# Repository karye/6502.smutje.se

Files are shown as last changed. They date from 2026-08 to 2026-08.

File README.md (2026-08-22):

# W65C02 8-bitarsdator med Arduino Mega-emulering

En hembyggd 8-bitarsdator med **W65C02S** CPU och **Arduino Mega 2560** som minnesemulator och klockgenerator. Projektet byggs stegvis — från en blinkande LED till en fullt fungerande dator med I/O-expansion (W65C22 VIA) och LCD-display styrd direkt av 6502-processorn.

---

## Webbplatsen (Material for MkDocs)

Sajten (6502.smutje.se) byggs från markdown-filerna i `docs/` med **Material for MkDocs**. `docs/` är källan — du redigerar bara markdown, aldrig `site/`.

### Bygga

```bash
cd /var/www/6502.smutje.se
.venv/bin/mkdocs build      # bygger site/ — Apache servear site/ direkt
.venv/bin/mkdocs serve      # lokal förhandsvisning på http://localhost:8000
```

### Arbetsflöde

1. Redigera `docs/*.md` (text, tabeller, bildreferenser)
2. Kör `mkdocs build`
3. Sajten är omedelbart uppdaterad — inget mer behövs

### Regler att hålla

- **Blankrader kring tabeller** — en tabell måste ha tomrad före och efter. Utan tomrad efter tabellen slukar tabellen nästa rubrik som tabellrad.
- **Kodrutorna är live** — kod visas via snippets (`--8<--`) direkt från `Mega_2560_6502/src/*.inc`, `asm/*.asm` och `scripts/*.py`. Ändra källfilen → nästa bygge visar nya koden, utan att röra md.
- **`site/` rörs aldrig** — genereras vid varje bygge och skrivs över.
- **`legacy/`** — arkiv av den gamla handskrivna HTML-sajten (stepX.html, style.css).
- Nya sidor läggs till i `nav:` i `mkdocs.yml`.

### Installation på ny maskin

```bash
python3 -m venv .venv
.venv/bin/pip install mkdocs-material mdx-truly-sane-lists
```

---

## Komponenter (alla steg)

| Antal | Komponent |
|---|---|
| 1 | W65C02S (DIP-40) |
| 1 | Arduino Mega 2560 |
| 1 | W65C22 VIA (DIP-40) — steg 7 |
| 1 | 74HC00 (quad NAND) — steg 7 |
| 1 | 74HC00 (quad NAND) — steg 10 (EEPROM-avkodning) |
| 1 | 62256 SRAM (DIP-28, 32 KB) — steg 9 |
| 1 | AT28C256 EEPROM (DIP-28, 32 KB) — steg 10 |
| 1 | Arduino Mega 2560 (till) — EEPROM-programmerare, steg 10 |
| 1 | LCD 16×2 eller 20×4 (parallell, t.ex. QC1602A) — steg 5 |
| 1 | Lysdiod (klockindikering) |
| 1 | 220 Ω motstånd (LED-strömbegränsning) |
| 1 | 220 Ω motstånd (LCD-bakgrundsbelysning) |
| 1 | 10 kΩ potentiometer (LCD-kontrast) |
| 4 | 10 kΩ motstånd (pull-up: RDY, IRQB, NMIB, SOB) |
| 1 | 10 kΩ motstånd (pull-up: BE → +5V) |
| 8 | 100 Ω motstånd (databuss-skydd) |
| 1 | 100 nF keramisk kondensator (avkoppling CPU) |
| 1 | 10 µF elektrolytisk kondensator (strömstabilisering) |
| 2 | Tryckknappar (klocksteg, instruktionssteg) |
| 1 | 16 MHz-oscillator (DIL-14) — steg 12 |
| 1 | 74HC393 (dubbel 4-bitars ripple-räknare) — steg 12 |
| 1 | Tryckknapp (till) — reset, steg 12 |
| 1 | 10 kΩ motstånd (till) — reset pull-up, steg 12 |
| 1 | 10 µF elektrolytisk kondensator (till) — reset-RC, steg 12 |
| — | Kopplingsdäck + kopplingstråd |

---

## W65C02S — pinout  

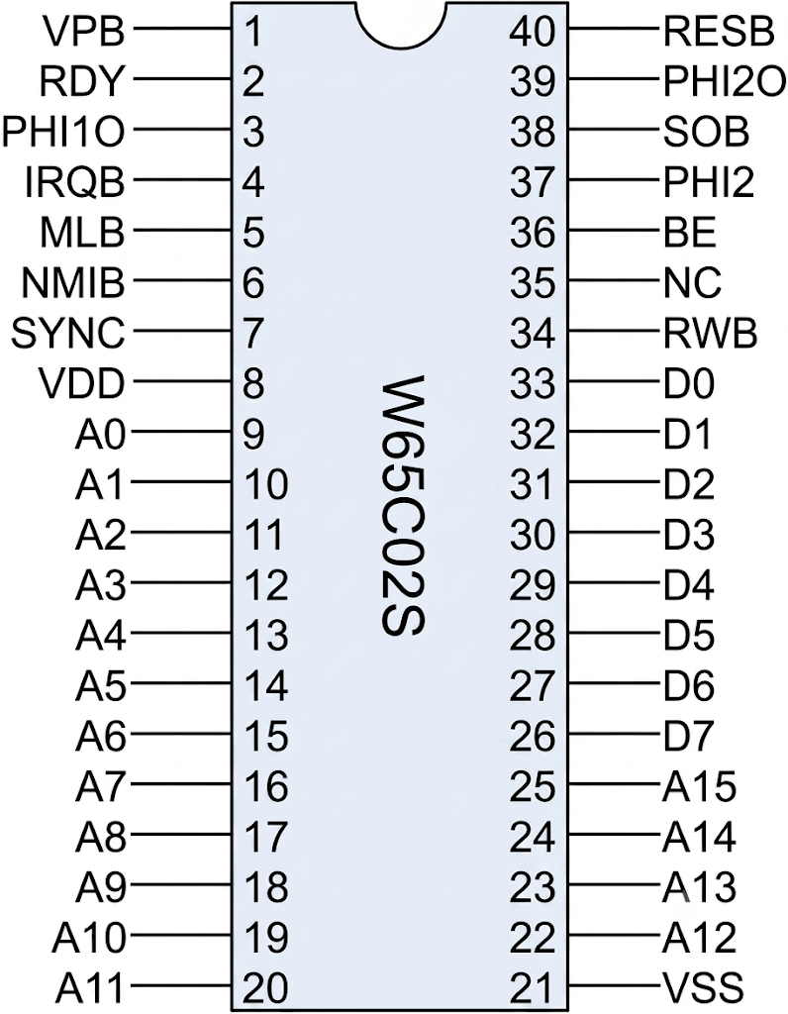
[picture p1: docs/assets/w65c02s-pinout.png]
W65C02S pinout


| Pin | Namn | I/O | Beskrivning |
|-----|---|-----|---|
| 1 | VPB | Ut | Vector Pull — utgång, ansluts ej |
| 2 | RDY | In | Ready — HÖG = CPU kör, LÅG = paus |
| 3 | PHI1O | Ut | Phase 1 Out — klocka ut, ansluts ej |
| 4 | IRQB | In | Interrupt Request (aktiv LÅG) |
| 5 | MLB | Ut | Memory Lock — utgång, ansluts ej |
| 6 | NMIB | In | Non-Maskable Interrupt (aktiv LÅG) |
| 7 | SYNC | Ut | Opcode fetch — HÖG vid instruktionshämtning |
| 8 | VDD | — | Strömmatning +5V |
| 9 | A0 | Ut | Adressbuss bit 0 |
| 10 | A1 | Ut | Adressbuss bit 1 |
| 11 | A2 | Ut | Adressbuss bit 2 |
| 12 | A3 | Ut | Adressbuss bit 3 |
| 13 | A4 | Ut | Adressbuss bit 4 |
| 14 | A5 | Ut | Adressbuss bit 5 |
| 15 | A6 | Ut | Adressbuss bit 6 |
| 16 | A7 | Ut | Adressbuss bit 7 |
| 17 | A8 | Ut | Adressbuss bit 8 |
| 18 | A9 | Ut | Adressbuss bit 9 |
| 19 | A10 | Ut | Adressbuss bit 10 |
| 20 | A11 | Ut | Adressbuss bit 11 |
| 21 | VSS | — | Systemjord GND |
| 22 | A12 | Ut | Adressbuss bit 12 |
| 23 | A13 | Ut | Adressbuss bit 13 |
| 24 | A14 | Ut | Adressbuss bit 14 |
| 25 | A15 | Ut | Adressbuss bit 15 |
| 26 | D7 | I/O | Databuss bit 7 (MSB) |
| 27 | D6 | I/O | Databuss bit 6 |
| 28 | D5 | I/O | Databuss bit 5 |
| 29 | D4 | I/O | Databuss bit 4 |
| 30 | D3 | I/O | Databuss bit 3 |
| 31 | D2 | I/O | Databuss bit 2 |
| 32 | D1 | I/O | Databuss bit 1 |
| 33 | D0 | I/O | Databuss bit 0 (LSB) |
| 34 | RWB | Ut | Read/Write — HÖG = läs, LÅG = skriv |
| 35 | NC | — | Ej ansluten |
| 36 | BE | In | Bus Enable — HÖG = bussar aktiva, LÅG = tri-state |
| 37 | PHI2 | In | Phase 2 In — klockingång |
| 38 | SOB | In | Set Overflow (aktiv LÅG) |
| 39 | PHI2O | Ut | Phase 2 Out — klocka ut, ansluts ej |
| 40 | RESB | In | Reset (aktiv LÅG) |

---

## W65C22 VIA — pinout

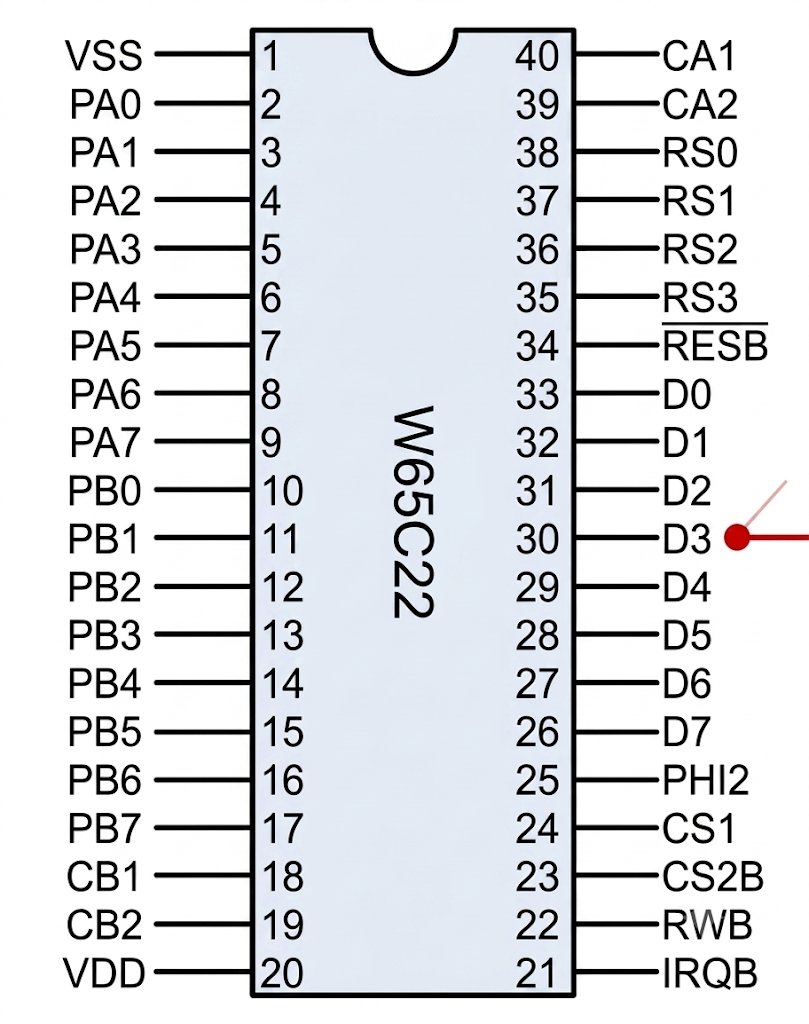
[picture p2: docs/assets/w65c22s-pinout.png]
W65C22 VIA pinout


## 74HC00 — pinout

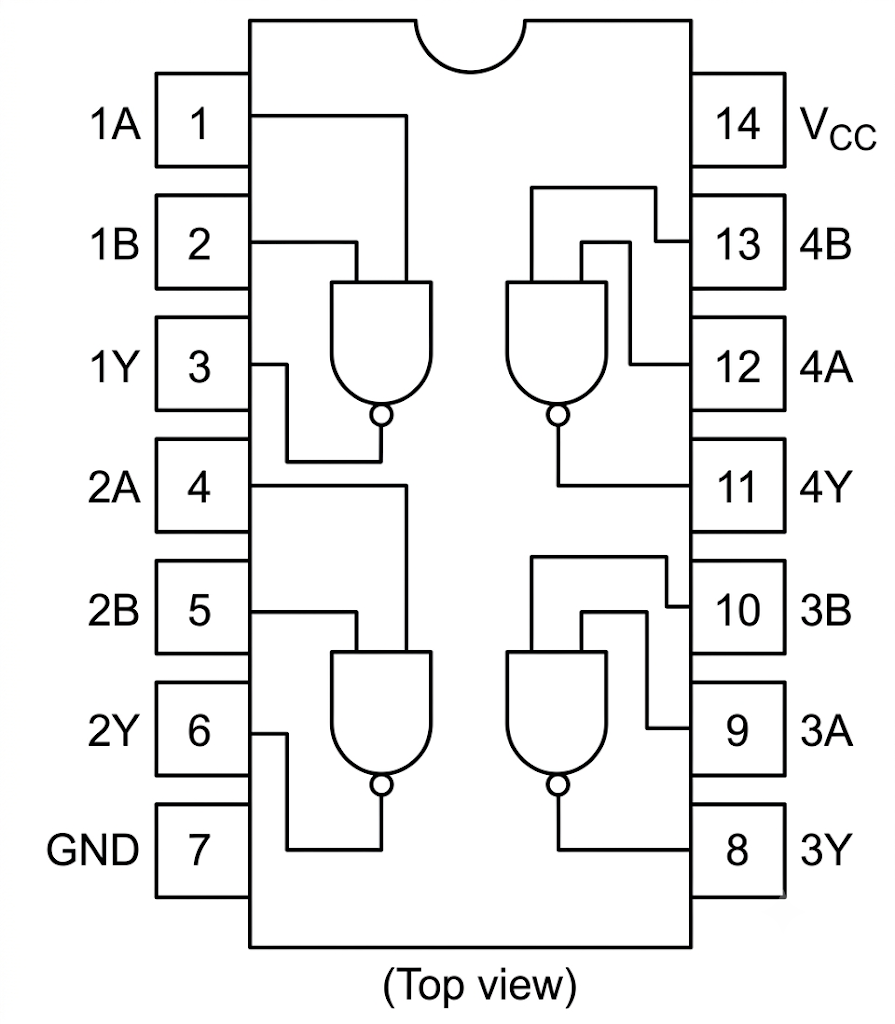
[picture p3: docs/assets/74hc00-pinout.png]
74HC00 pinout


---

## CPU-kopplingar (gäller alla steg)

| CPU-pin | Signal | Arduino | Not |
|---|---|---|-----|
| 8 | VDD | 5V | Strömmatning |
| 21 | VSS | GND | Systemjord |
| 37 | PHI2 | D2 | Klocka (500 Hz) |
| 34 | R/W | D3 | Read/Write |
| 40 | /RESET | D4 | Reset |
| 2 | RDY | 5V via 10kΩ | Pull-up |
| 4 | /IRQ | 5V via 10kΩ | Pull-up |
| 6 | /NMI | 5V via 10kΩ | Pull-up |
| 36 | BE | +5V via 10kΩ | Bus Enable — HÖG = bussar aktiva |
| 38 | /SO | 5V via 10kΩ | Pull-up |

### Adressbuss (1:1)
| CPU | Arduino | Register |
|-----|---|---|
| A0–A7 (pin 9–16) | A0–A7 | `PORTF` |
| A8–A15 (pin 17–20,22–25) | A8–A15 | `PORTK` |

### Databuss
| CPU | Arduino | Register |
|-----|---|---|
| D0–D7 (pin 26–33) | D22–D29 | `PORTA` |

### Knappar & SYNC
| Signal | Arduino |
|---|---|
| SYNC (CPU pin 7) | D13 |
| BTN1 (klocksteg) | D11 → GND |
| BTN2 (instr.steg) | D12 → GND |

---

## Adressrymd

```
$FFFF ┌──────────────┐
      │  EEPROM ROM   │  $C000–$FFFF (steg 11: program + vektorer)
$C000 ├──────────────┤
$BFFF │  W65C22 VIA   │  $8000–$BFFF (I/O-fönster, 16 KB)
$8000 ├──────────────┤
      │              │
$7FFF ├──────────────┤
      │  62256 SRAM   │  $0000–$7FFF (steg 11: 32 KB, hela chippet)
$0000 └──────────────┘
```

Steg 7–10 använde VIA på $4000 (register speglas i $4000–$7FFF). Steg 9–10 använde SRAM på $0000–$3FFF; steg 7–8 hade Arduino-emulerat RAM (1 KB). Från och med steg 11: SRAM täcker hela 32 KB, VIA sitter i ett I/O-fönster på $8000 och EEPROM på $C000.

---

## Stegöversikt

| Steg | Innehåll | Ny hårdvara |
|---|---|---|
| 1 | CPU + ström + klocka + LED | CPU, LED, 100nF, 10µF |
| 2 | Adressbuss + reset | 16 kopplingstrådar |
| 3 | Databuss + minnesemulering | 8×100Ω |
| 4 | Knappar + stegning | 2 knappar |
| 5 | LCD via Arduino (parallell 4-bit) | LCD, 10kΩ pot, 220Ω |
| 6 | Eget 6502-program (räknare) | — (samma hårdvara) |
| 7 | W65C22 VIA + 74HC00, LCD via VIA | VIA, 74HC00 |
| 8 | Assembler-bygge med ca65 | — (samma hårdvara) |
| 9 | Riktigt RAM (62256 SRAM) | 62256 SRAM |
| 10 | EEPROM som ROM (AT28C256) | AT28C256 EEPROM, 2:a 74HC00, 2:a Arduino (programmerare) |
| 11 | Städad adressrymd | — (omkoppling, ingen ny krets) |
| 12 | Fristående klocka | 16 MHz-oscillator, 74HC393 |

---

## Steg 5–6: LCD-koppling (parallell 4-bit, Arduino direkt)

| LCD-pin | Arduino | Funktion |
|---|---|---|
| VSS (1) | GND | Jord |
| VDD (2) | 5V | Ström |
| VO (3) | Potentiometer | Kontrast |
| RS (4) | D5 | Register Select |
| R/W (5) | GND | Write-only |
| E (6) | D6 | Enable |
| DB4 (11) | D10 | Data (omvänd ordning) |
| DB5 (12) | D9 | |
| DB6 (13) | D8 | |
| DB7 (14) | D7 | |
| A (15) | 5V via 220Ω | Bakgrundsbelysning |
| K (16) | GND | |

## PlatformIO — växla mellan steg

Steg 1–11 finns som separata `.inc`-filer i `src/`. `main.cpp` är en dispatcher som inkluderar rätt fil baserat på `-DSTEPx`. Steg 12 är helt fristående — ingen Arduino-kod, programmet bränns i EEPROM:en.

### I VS Code
Välj aktiv miljö i PlatformIO-fliken: `env:step1` … `env:step11`, klicka sedan Upload.

### Kommandorad
```bash
pio run -e step11 -t upload -t monitor  # steg 11 (städad adressrymd)
pio run -e step10 -t upload -t monitor  # steg 10 (EEPROM som ROM)
pio run -e step8 -t upload -t monitor   # steg 8 (assembler-bygge)
pio run -e step7 -t upload -t monitor   # steg 7 (VIA + LCD)
pio run -e step6 -t upload -t monitor   # steg 6 (räknarprogram)
pio run -t upload -t monitor            # default = steg 9
```

### Filstruktur
```
src/
├── main.cpp        # dispatcher (#ifdef)
├── step1.inc       # klocka + lysdiod
├── step2.inc       # adressbuss + reset
├── step3.inc       # databuss + NOP
├── step4.inc       # knappar
├── step5.inc       # LCD via Arduino
├── step6.inc       # räknarprogram
├── step7.inc       # VIA + LCD
├── step8.inc       # Assembler-bygge (ca65)
├── step9.inc       # 62256 SRAM
├── step10.inc      # EEPROM som ROM
├── step11.inc      # städad adressrymd
├── program_hello.h # genereras av build_asm.py (ca65 → ld65 → bin2h)
└── program_fib.h   # genereras av build_asm.py

asm/
├── program.cfg     # ld65-länkskript
├── program_hello.asm
└── program_fib.asm

scripts/
├── build_asm.py    # pre-build-hook: ca65 + ld65 + bin2h för alla *.asm
├── bin2h.py        # .bin → C-header
└── upload_eeprom.py # skicka .bin till EEPROM-programmeraren (steg 10)

EEPROM_programmer/
└── EEPROM_programmer.ino  # separat Arduino (steg 10, Arduino IDE)
```

## Steg 7: LCD via VIA (8-bit parallell)

CPU:n ($8000-programmet) styr LCD:n genom att skriva till VIA:ns register ($4000–$4003).
Arduinon är endast minnesemulator + klocka — all LCD-logik körs på 6502.

### VIA → LCD

| VIA-pin | Signal | LCD-pin | Funktion |
|---|---|---|---|
| 2 | PA0 | 4 (RS) | Register Select |
| 4 | PA2 | 6 (E) | Enable |
| 10–17 | PB0–PB7 | 7–14 (DB0–DB7) | 8-bitars data |

### 74HC00 adressavkodning → VIA $4000–$400F

| 74HC00 | Ansluts till | Funktion |
|---|---|---|
| 1, 2 (U4A in) | CPU A15 | Inverterare (NOT A15) |
| 3 (U4A ut) | U4B pin 4 | NOT A15 → NAND-ingång |
| 5 (U4B in) | CPU A14 | (NOT A15) NAND A14 |
| 6 (U4B ut) | VIA pin 23 (CS2B) | LÅG vid $4000–$7FFF → VIA aktiv |
| 14 (VCC) | +5V | Strömmatning |
| 7 (GND) | GND | Systemjord |

### 6502-programflöde (steg 7)

1. **Sätt VIA-portar:** `LDA #$FF` → `STA $4002` (DDRB) → `STA $4003` (DDRA)
2. **LCD-init (8-bit):** $30 × 3 → $38 (function set) → $0C (display ON) → $01 (clear) → $06 (entry mode)
3. **Skriv text:** Flytta cursor via kommando ($80, $C0 för rad 1–2), skriv tecken via PORTB + pulsa E på PORTA
4. **Clear + loop:** $01 (clear display) → JMP tillbaka till start

### Felsökning steg 7

| Symptom | Trolig orsak |
|---|---|
| CPU startar ej (RWB=L, adress=0) | BE ej kopplad till +5V, eller RESB når ej CPU |
| CPU läser $FFFC/$FFFD men hoppar till $0000 | Databuss-timing: `DDRA=0x00` måste ske EFTER `PHI2=LOW` |
| VIA-skrivningar i logg men LCD visar inget | Kontrollera VIA→LCD-kablar, särskilt DB0–DB7 (8 st) |
| E/RS växlar men LCD blank | Vrid kontrast-potentiometer, kolla bakgrundsbelysning (A/K) |
| Text skrivs om på flera rader | JMP pekar tillbaka till hello-start istället för halt-loop |

---

## Varningar

- **100Ω seriemotstånd på databussen är obligatoriska** — utan dem kan en busskollision förstöra CPU och Arduino.
- **BE (pin 36) måste vara HÖG (+5V)** — LÅG tri-statar bussarna.
- **Använd 12–18V DC-adapter** till Arduino för stabil 5V-matning.
- **Kopplingsbrädor kan ha dolda kortslutningar** — flytta kretsen vid misstänkt fel.

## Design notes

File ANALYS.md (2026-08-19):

# Analys av 6502-projektet

Datum: 2026-08-19
Omfattning: hela repot (HTML, README, Arduino-kod, asm, byggskript, git).
KiCad-scheman är **utanför** denna granskning (hanteras manuellt) — men TODO-posternas förslag om BE/CS1 varnas för i avsnittet *Kritiska rön*, eftersom de är fel och påverkar det manuella arbetet.

## 1. Sammanfattning

Projektet är tekniskt väl genomtänkt och stegvis pedagogiskt uppbyggt. Kärnan — 6502-emuleringen i Arduino (portregister, DDRA-timing, tri-state), ca65/ld65-bygget och adressavkodningen i HTML-dokumentationen — är korrekt. Men det finns **tre kritiska rön**, två av dem i dokumentationen (BE-pinnen) och byggskriptet, och ett som är en kod-/dokument-motsägelse (adressläsningen i steg 2–6). Därutöver en handfull allvarliga luckor (steg 10–11 saknar körbar kod, README är inaktuell) och många mindre synkfel.

## 2. Metod och kriterier

Analysen utgår från följande källhierarki (per projektägarens direktiv):

1. **HTML-sidorna (steg 6–11) = referens** — mest aktuella sanningen om adressrymd, avkodning och kopplingar.
2. **KiCad-scheman** — hanteras manuellt, ej granskade här.
3. **README.md** — behandlad som föråldrad dokumentation; avvikelser mot HTML flaggas som inaktuella.
4. **Arduino-kod + asm + byggskript** — granskade mot HTML där de beskriver samma sak.

Kriterier: teknisk korrekthet mot datablad (w65c02s.pdf, w65c22.pdf), konsistens mellan källorna, byggbarhet/reproducerbarhet, kodkvalitet, kompletthet och git-hygien. Byggkedjan (ca65/ld65) testades körande; databladen verifierades med `pdftotext`.

## 3. Inventering

### HTML (referens)
| Fil | Senast ändrad | Kommentar |
|-----|---|---|
| step1–5.html | 13 aug | Grundsteg |
| step6–11.html | 19 aug | Senaste arbetsytan (steg 9–11 mest aktuella) |
| index.html | 13 aug | Översikt, alla länkar pekar på befintliga filer ✓ |

### Arduino-kod (Mega_2560_6502)
- `src/main.cpp` — dispatcher med `STEP1`–`STEP9` (inget `STEP10`/`STEP11`).
- `src/step1–9.inc` — steg 1–9. Steg 10 och 11 har **ingen** .inc-fil.
- `asm/` — program_hello.asm, program_fib.asm, program.cfg (+ kommitterade `.bin`/`.o`).
- `scripts/` — build_asm.py (trasig, se K2), bin2h.py (fungerar).
- `platformio.ini` — env:step1–step9; `default_envs = step9`.

### Övrigt
- `schematics/` — PNG för steg 1–7, 9, 10-1, 10-2. Saknas: steg-8 (medvetet, samma hårdvara som steg 7) och steg-11 (step11.html har placeholder ”Schema kommer snart”).
- `docs/` — datablad (w65c02s.pdf, w65c22.pdf) + pinout-PNG:er.
- Git: 339 commits; grenarna main, via-c000 (efter, sannolikt övergiven), responsive (tom mot main).

## 4. Verifierat korrekt

- **ca65/ld65-kedjan fungerar.** `program.cfg` + `program_hello.asm` och `program_fib.asm` bygger till 2054-byte-binärer som är identiska med de kommitterade `.bin`-filerna och `.h`-headerarna. Reproducerbart.
- **Steg 11:s program.cfg (från step11.html) fungerar.** ld65 ger 16 384-byte ROM med vektorer på $FFFA (reset → $C000) — verifierat körande.
- **LCD-kopplingen stämmer** mellan kod, README och HTML: RS=D5, E=D6, DB4=D10, DB5=D9, DB6=D8, DB7=D7.
- **BE-nivån i HTML** (steg 1, 2, 3, 7, 9): BE = +5V via 10 kΩ, HÖG = bussar aktiva — stämmer med databladet.
- **VIA CS1/CS2B per HTML**: CS1 (pin 24) = +5V, /CS2 (pin 23) = avkodning — stämmer med databladet (CS1 måste vara HÖG, /CS2B LÅG).
- **Adressavkodningen i HTML (steg 9/10/11)** är elektriskt korrekt: SRAM $0000–$3FFF (U4C+U4D), VIA $4000–$7FFF (U4A+U4B), EEPROM $8000–$FFFF (steg 10, NOT A15) respektive $C000–$FFFF (steg 11, NAND(A15,A14)).
- **Steg 7–9-koden** har korrekt portregisterhantering, tri-state före PHI2-stigande flank, och minnesrutor utan uppenbara fel (undantag: A4 nedan).
- **index.html** — alla interna länkar pekar på befintliga filer.

## 5. Rön

### Kritiska

#### K1 — BE-pinnen: README och TODO föreslår fel nivå (GND), databladet kräver HÖG
Databladet (docs/w65c02s.pdf, avsnitt 3.2): *”When Bus Enable is high, the Address, Data and RWB buffers are active. When BE is low, these buffers are set to the high impedance status.”*

Fel i README.md:
- rad 19: `10 kΩ motstånd (pull-down: BE → GND)` — ska vara pull-**up** till +5V.
- rad 69: `BE | In | Bus Enable — LÅG = bussar aktiva, HÖG = tri-state` — omvänt.
- rad 99: `BE | GND | Bus Enable — LÅG = bussar aktiva` — fel.

Rätt i README: rad 243 (felsökning) och rad 254 (varning). HTML-sidorna har rätt (+5V via 10 kΩ).

**TODO.md-varning:** posten ”BE (CPU pin 36) → GND i KiCad för alla steg” är fel — gör inte detta. Koppla BE till **+5V via 10 kΩ** i stället. (Viktigt inför det manuella KiCad-arbetet.)

Åtgärd: rätta README-rad 19/69/99; ändra TODO-posten till ”BE → +5V via 10kΩ”.

#### K2 — build_asm.py bygger en fil som inte finns
`Mega_2560_6502/scripts/build_asm.py` (rad 14–17) pekar på `asm/program_hello.hello.asm` — filen heter `program_hello.asm`. ca65 misslyckas → `pio run -e step8` / `-e step9` avbryts i pre-build-steget. (De kommitterade `.h`/`.bin`-filerna gör att befintliga byggen ser ut att fungera, men en ren checkout går inte att bygga.)

Åtgärd: byt till `program_hello.asm` (och justera `.o`/`.bin`-namnen i samma skript för konsistens).

#### K3 — Adressläsningen är byte-vänt i steg 2–6
- `src/step2.inc` … `src/step6.inc`: `uint16_t addr = (PINK << 0) | (PINF << 8);`
- `src/step7.inc`–`src/step9.inc`: `uint16_t a = (PINF << 0) | (PINK << 8);` (korrekt)
- HTML-tabellerna (step2–6 ”Kopplingar”): A0–A7 → Arduino A0–A7 (PORTF), A8–A15 → Arduino A8–A15 (PORTK). Låg byte = PINF.
- Exempelutskrifterna i step2/3/6.html visar korrekta adresser ($FFFC, $8000, $0200) — de motsäger formeln i steg 2–6.

Formeln i steg 2–6 introducerades i commit f2d2a41 (”Fix address calculation…”) — samma commit gav step8.inc den korrekta kl/kh-formen. Med nuvarande steg 2–6-kod och dokumenterad koppling skulle reset-vektorn läsas som $FCFF i stället för $FFFC och programmet aldrig starta på $8000.

Slutsats: antingen är koden fel (mest troligt, eftersom steg 7–9 och HTML-exemplen använder motsatt ordning) eller så är kopplingstabellerna fel. Måste verifieras mot hårdvara (se Öppna frågor), men kod och dokumentation måste i vilket fall synkas.

Åtgärd: ändra steg 2–6 till `(PINF << 0) | (PINK << 8)` — eller, om hårdvaran verkligen är omvänd, rätta tabellerna i stället.

### Allvarliga

#### A1 — README:s minneskarta för steg 11 är inaktuell
README rad 126–139: VIA på $A000–$A00F, EEPROM på $A010–$FFFF och $8000–$9FFF.
HTML (step11.html, referens): SRAM $0000–$7FFF (32 KB), VIA $8000–$BFFF (I/O-fönster), EEPROM $C000–$FFFF.
Åtgärd: uppdatera README till $8000/$C000-layouten (eller peka på step11.html).

#### A2 — Steg 10 och 11 har ingen körbar kod i repot
- Ingen `src/step10.inc` / `src/step11.inc`, inga `env:step10`/`env:step11` i platformio.ini, inga `STEP10`/`STEP11` i main.cpp.
- Steg 10:s EEPROM-programmerare (Arduino-skiss) och `upload_eeprom.py` (Python) finns bara som kodblock i step10.html.
- Steg 11:s Arduino-kod och nya program.cfg (ROM $C000) finns bara i step11.html.

Det går alltså inte att bygga steg 10–11 från repot. Åtgärd: lägg till kodfiler + envs (och gärna `upload_eeprom.py` under t.ex. `Mega_2560_6502/scripts/`).

#### A3 — README:s komponentlista saknar steg 9–11-hårdvara
62256 SRAM, AT28C256 EEPROM, andra Arduinon (programmerare, steg 10) och andra 74HC00 (steg 10) saknas i ”Komponenter (alla steg)”. BOM-raden för BE är dessutom fel (K1).

#### A4 — Latent busskollision på $4010–$7FFF i steg 7–10
I steg 7–10 är `is_via()` = $4000–$400F, men den fysiska VIA:n (CS1=+5V, /CS2 låg vid $4000–$7FFF) svarar på hela fönstret. Arduino:n driver då 0xEA på läsningar i $4010–$7FFF — båda driver databussen samtidigt. Demoprogrammen når aldrig dit, men en avläsning av området (t.ex. vid felsökning) ger en krock. I steg 11 är `is_via()` = $8000–$BFFF — korrekt hanterat där.
Åtgärd: utöka `is_via()` till hela VIA-fönstret även i steg 7–10.

### Mindre

- **M1 — Default-steg motsäger varandra:** main.cpp-kommentar ”default = steg 7”, fallback inkluderar step8.inc, README ”default = steg 8”, platformio.ini `default_envs = step9`.
- **M2 — Klockfrekvens-dokumentationen:** README rad 93 ”Klocka (20 Hz)” och stegtabeller i HTML (steg 2/3/7) säger 20 Hz; koden kör 500 Hz (steg 2+) / 1 Hz (steg 1). program_fib.asm-kommentaren ”≈ 1 sekund vid 50 Hz” är också inaktuell (nu ~0,1 s vid 500 Hz).
- **M3 — Inaktuella README-texter:** rad 180 ”Alla sju steg” (det finns nio .inc); rad 183 ”env:step1 … env:step8” (nio envs); rad 138 ”Steg 7–10 använde … SRAM på $0000–$3FFF” (steg 7–8 hade inget fysiskt SRAM); rad 157 steg 11 ”(andra 74HC00)” (HTML säger ”inga nya kretsar” — den andra 74HC00 kom i steg 10).
- **M4 — TODO.md: ”Via CS1 (pin 4) kopplas till GND — steg 7” (bockad):** fel pinnummer — CS1 är pin **24** (pin 4 är PA2, LCD E) — och fel nivå: CS1 ska vara **HÖG** för att VIA:n ska svara. Kontrollera om denna ändring redan gjordes i KiCad; i så fall fungerar inte VIA:n. (Viktigt inför det manuella KiCad-arbetet.)
- **M5 — Steg 1, RESB:** HTML säger ”/RESET lämnas flytande — CPU:n startar själv”, medan step1.inc håller RESB låg via D4 (CPU i reset). Dokumentation och kod säger emot varandra.
- **M6 — program_fib.h byggs inte automatiskt:** build_asm.py genererar bara program_hello.h. Vid ändring av program_fib.asm måste headern genereras manuellt.
- **M7 — Byggartefakter i git:** `asm/*.bin` och `asm/*.o` är kommitterade; Mega_2560_6502/.gitignore har inaktuella sökvägar (`src/program.o`, `src/program.bin`) och ignorerar inte `asm/*.o`, `asm/*.bin`.
- **M8 — Grenen `via-c000`** ligger efter main och innehåller en äldre VIA-$C000-variant — sannolikt övergiven. Rensa eller arkivera.
- **M9 — README ”6502-programflöde (steg 7)”** beskriver 4-radersprogrammet ($94/$D4), medan step7.inc skriver 2 rader (”W65C02 VIA LCD” + ”smutje.se W65C02”).

### Kosmetiska

- **Kos1 — step1.html:** step11-länken i nav har annorlunda indragning; step1 saknar ”→ Steg 2”-länk (övriga sidor har prev/next).
- **Kos2 — step9/step10-minneskartor** visar $4010–$7FFF som ”oanvänt” trots att VIA-register speglas där (presentationsval — förtydliga eller justera).

## 6. Status per steg

| Steg | Status |
|---|---|
| 1 | Kod ok; RESB-diskrepans (M5); klocka 1 Hz i kod vs ”20 Hz”-dok. |
| 2–6 | **Byte-vänt adressläsning (K3)**; LCD-koppling (steg 5–6) korrekt. |
| 7 | Kod korrekt med rik diagnostik; VIA-avkodning per HTML korrekt; latent krock (A4); README-flöde beskriver 4 rader (M9). |
| 8 | Byggkedjan dokumenterad men build_asm.py trasig (K2); program_hello.asm kompilerar; default-otydlighet (M1). |
| 9 | Kod ok (förutom A4); SRAM-avkodning i HTML korrekt; program_fib.h byggs ej automatiskt (M6). |
| 10 | Kod bara i HTML (A2); minneskarta ok i HTML; BOM saknar 2:a Arduino + 74HC00 + AT28C256 (A3). |
| 11 | Referenssida; minneskarta/avkodning korrekt och verifierad mot ld65; kod + program.cfg bara i HTML (A2); README inaktuell (A1); schema-placeholder ”kommer snart”. |

## 7. Prioriterad åtgärdslista

1. **K1** – Rätta BE i README (rad 19/69/99) och TODO (koppla BE till +5V via 10 kΩ, inte GND).
2. **M4** – Kontrollera CS1 i KiCad (pin 24 ska vara HÖG) innan schemana ritas klart.
3. **K2** – Fixa filnamnet i build_asm.py.
4. **K3** – Verifiera adressbussens koppling på hårdvara och synka steg 2–6-koden med steg 7–9 och HTML.
5. **A1** – Uppdatera README-minneskartan för steg 11.
6. **A2** – Lägg till körbar kod för steg 10–11 (step10/11.inc, env:step10/11, programmeraren + upload_eeprom.py).
7. **A3** – Komplettera README-komponentlistan.
8. **A4** – Utöka is_via() till hela VIA-fönstret i steg 7–10.
9. **M1–M3, M5–M9** – Dokumentations- och hygiensynk.
10. **Kos1–Kos2** – Kosmetik.

## 8. Öppna frågor (kräver hårdvara eller projektägaren)

- Är adressbussen i steg 2–6 verkligen kopplad A0–A7 → PORTF enligt tabellerna (då var koden fel), eller omvänt? Koden är nu synkad med tabellerna (K3-åtgärden); verifiera på hårdvara att steg 2–6 visar korrekta adresser i loggen.
- Har CS1-ändringen (”pin 4 → GND” i gamla TODO) redan gjorts i KiCad? (M4)
- Är det korrekt att steg 11 inte kräver någon ny krets (HTML), eller krävs ”andra 74HC00” (gamla README)? (M3)

## 9. Åtgärdsstatus (uppdaterad efter åtgärderna)

| Punkt | Åtgärd | Status |
|---|---|---|
| K1 | BE → +5V via 10 kΩ i README (BOM, pinout, CPU-tabell) + TODO.md rensad | ✅ |
| K2 | build_asm.py bygger nu rätt filnamn (alla asm/*.asm) | ✅ |
| K3 | steg 2–6-adressläsningen synkad med steg 7–9 (`PINF \| PINK<<8`) | ✅ (verifieras på hårdvara) |
| M4 | TODO.md: CS1 (pin 24) ska vara +5V — korrekt vägledning inför KiCad-arbetet | ✅ (dok) |
| A1 | README-minneskartan för steg 11 uppdaterad till $8000/$C000 | ✅ |
| A2 | step10.inc + step11.inc + env:step10/11 + EEPROM_programmer.ino + upload_eeprom.py | ✅ |
| A3 | README-BOM kompletterad (62256, AT28C256, 2:a Arduino, 2:a 74HC00) | ✅ |
| A4 | is_via() utökad till hela VIA-fönstret i steg 7–10 (+ step8/9/10.html-kodblocken) | ✅ |
| M1 | Default-steg synkat: main.cpp + platformio.ini + README → steg 9 | ✅ |
| M2 | Klockfrekvens-dok: 500 Hz i README + step7/9.html + fib-kommentar | ✅ |
| M3 | README-texter: ”elva steg”, env:step1…11, steg 9–10-SRAM, steg 11 utan ny krets | ✅ |
| M5 | step1.html: /RESET hålls låg av Arduino (i stället för ”flytande”) | ✅ |
| M6 | build_asm.py bygger både program_hello och program_fib (headers verifierade identiska) | ✅ |
| M7 | asm/*.o + asm/*.bin borttagna från git-spårning; .gitignore uppdaterad | ✅ |
| M8 | Grenen via-c000 lämnas — radera/arkivera vid tillfälle | ⏳ |
| M9 | README:s steg-7-programflöde korrigerat till 2 rader ($80, $C0) | ✅ |
| Kos1 | step1.html: nav-indragning rättad (nästa-länk fanns redan) | ✅ |
| Kos2 | Minnesskartornas presentationsval ($4010–$7FFF som ”oanvänt”) lämnas | ⏳ |

Ej gjorda (kräver projektägaren): M8 (grenrensning), Kos2 (presentation), KiCad-nätlister/PNG-export, samt hårdvaruverifiering av K3.

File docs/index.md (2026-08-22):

# W65C02 8-bitarsdator

## En hembyggd dator från grunden

 Ända sedan jag först läste om hur enkla 8-bitarsprocessorer fungerar har jag drömt om att bygga en egen dator. Inte en snabb, inte en modern — utan en dator där *varje komponent går att förstå*. En dator där jag kan följa varje etta och nolla från processorns instruktionsregister hela vägen ut till en lysdiod eller en LCD-display. 

## En Arduino som startmotor

En 6502-dator från 1970-talet behövde ROM och RAM som fysiska chips — och för att testa ett nytt program fick man bränna ett nytt EPROM under UV-ljus, en process som tog 20 minuter per försök. Här använder jag en **Arduino Mega 2560** som startmotor: den står för klocka, minne och diagnostik i början, så att jag kan fokusera på processorn och se varje signal på kopplingsdäcket. 

Steg för steg ersätter jag Arduinons uppgifter med riktiga kretsar. **SRAM**-chippet tar över minnet, **EEPROM**:et tar över programkoden, **VIA**-kretsen tar över I/O till LCD-displayen. 

Det här är inte en emulator i mjukvara — processorn kör på riktigt, med riktiga elektriska signaler. Allt jag lär mig om 6502:ans instruktionsuppsättning, timing och bussprotokoll gäller på riktigt. 

## Hur det hänger ihop

Så här pratar de olika kretsarna med varandra. CPU:n i mitten, adressbussen åt ena hållet och databussen åt det andra. Arduino är startmotorn — streckad, eftersom den fasas ut steg för steg.
Översikt över 6502-datorn

## Hur fungerar en 6502-processor?

### Två bussar — adress och data

Processorn har två uppsättningar ledningar ut till världen. Den första är adressbussen — 16 ledningar som tillsammans bildar ett tal mellan 0 och 65 535. Det talet är en minnesadress: *"jag vill läsa från adress 32 768"*, eller i hexadecimalt: `$8000`. Processorn lägger ut adressen på stiften A0–A15 och alla kretsar på bussen ser den samtidigt.

Den andra uppsättningen är databussen — 8 ledningar. Här kommer svaret tillbaka. När processorn vill läsa från en adress lägger den ut adressen, sätter R/W-signalen till HÖG (Read), och väntar. Den krets som känner igen adressen — i början Arduino, senare SRAM, EEPROM eller VIA — lägger ut rätt byte på databussen. Processorn läser av den och går vidare till nästa instruktion.

### Arduino emulerar ram och rom

En **6502**-dator från 1970-talet hade ROM och RAM som fysiska chips. Varje gång man vill testa ett nytt program får man bränna ett nytt EPROM under UV-ljus — en process som tar 20 minuter per försök. Arduino vänder på det här: jag laddar upp ett nytt program på två sekunder över USB. Arduino läser av processorns adressbuss, slår upp rätt byte i sin interna array, och lägger ut den på databussen — allt inom samma klockcykel. 

Detta är inte en emulator i mjukvara — processorn kör på riktigt, med riktiga elektriska signaler. Arduinon är bara minnet. Det betyder att allt jag lär mig om 6502:ans instruktionsuppsättning, timing och bussprotokoll gäller på riktigt. Jag kan ta bort Arduino och ersätta den med ett EEPROM och ett SRAM-chip — och datorn fungerar precis likadant. 

### Arduino läser adressbussen

Arduino Mega har 54 digitala I/O-pinnar — nästan tillräckligt för att täcka 16 adresslinjer + 8 datalinjer + kontrollsignaler. Men den har också något bättre: portregister. Istället för att läsa en pinne i taget med `digitalRead()` (långsamt!) läser jag hela 8-bitarsportar på en gång: 

- PORTF — 8 bitar, läser CPU:ns A0–A7 i en enda maskininstruktion
- PORTK — 8 bitar, läser CPU:ns A8–A15
- PORTA — 8 bitar, driver databussen D0–D7 (eller går tri-state)

Tre registerläsningar, en villkorssats, och jag vet exakt vad processorn vill göra — redo att svara inom samma klockcykel. 

## Byggstegen

| Steg | Du lär dig | Svårighet |
|---|---|---|
| 1 · Ström och klocka | 5V, GND, klocka, lysdiod | Lätt |
| 2 · Adressbuss | Hex, reset-vektorn, portregister | Lätt |
| 3 · Databuss | R/W, tri-state, minnesemulering | Medel |
| 4 · Knappar | SYNC, enstegning, debounce | Lätt |
| 5 · LCD | Parallell kommunikation, kontrast | Lätt |
| 6 · Eget program | Maskinkod, opcode/operand, little-endian | Medel |
| 7 · VIA + LCD | I/O-krets, minnesmappad I/O, adressavkodning | Hög — seriens största kliv |
| 8 · Assembler | ca65/ld65, labels, subrutiner | Hög |
| 9 · SRAM | Riktigt minne, chip enable, zero page, carry-aritmetik | Medel |
| 10 · EEPROM | ROM, programmering, bränning | Medel |
| 11 · Adressrymd | Chip select, spegling, minimal avkodning | Hög |
| 12 · Fristående klocka | Oscillator, frekvensdelning, tidshantering (delay-loopar) | Medel |

Fastnade du på ett ord? Se [Begrepp och förkortningar](begrepp.md).

## Verktyg och programvara
| Verktyg | Används till | Från steg |
|---|---|---|
| Multimeter | Mäta spänningar och kontrollera signaler — felsökningens viktigaste verktyg | 1 |
| Kopplingsdäck + trådar | Bygga kretsen utan lödning | 1 |
| PlatformIO + VS Code | Bygga och ladda upp Arduino-koden | 1 |
| ca65 + ld65 | Assemblera 6502-program till binärer | 8 |
| Python + pyserial | Skicka .bin-filer till EEPROM-programmeraren | 10 |
| Arduino IDE | Ladda upp EEPROM-programmeraren (andra Arduinon) | 10 |

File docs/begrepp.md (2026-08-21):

# Begrepp och förkortningar

En uppslagsplats för alla ord du möter i serien — förklaringar som är korta nog att slå upp mitt i bygget, och tillräckligt djupa för att du ska förstå varför.

## Bussar och signaler

Adressbuss — 16 ledningar (A0–A15) som talar om var processorn vill läsa eller skriva. Värdet på bussen är en adress, t.ex. `$8000`.

Databuss — 8 dubbelriktade ledningar (D0–D7) som bär själva datan mellan kretsarna.

R/W (Read/Write) — signalen som talar om ifall processorn läser (HÖG) eller skriver (LÅG). Pinnen på processorn heter `RWB`.

Klocka (`PHI2`) — pulsen som driver processorn. W65C02S är *statisk CMOS*: klockan kan stoppas hur länge som helst utan att tillståndet försvinner.

Tri-state — ett läge där en krets inte driver en ledning alls (hög impedans), så att någon annan kan göra det i stället.

Pull-up / pull-down — ett motstånd till +5V (pull-up) eller GND (pull-down) som håller en signal på en känd nivå när inget annat driver den.

Fallande flank — ögonblicket då en signal går från HÖG till LÅG. LCD:n läser databussen just då.

Chip select — en ingång som talar om för en krets om just den ska svara på bussen just nu.

## Minne

Adressrymd — alla 65 536 möjliga adresser (`$0000`–`$FFFF`) som processorn kan nå.

Reset-vektor — adresserna `$FFFC`/`$FFFD` där processorn efter reset läser var programmet börjar.

Hex — hexadecimala tal, bas 16, med prefixet `$`. `$FF` = 255, `$8000` = 32 768.

Little-endian — ordningen där en 16-bitars adress lagras med låg byte först (`$8000` skrivs `00 80`).

Zero page — minnesområdet `$0000`–`$00FF`; nås med kortare och snabbare instruktioner.

Stacken — minnesområdet `$0100`–`$01FF` där `JSR`/`PHA`/`RTS` automatiskt sparar och hämtar data.

RAM / SRAM — arbetsminne som försvinner när strömmen bryts. 62256 är 32 KB SRAM.

ROM / EEPROM — beständigt minne. AT28C256 är 32 KB EEPROM som kan raderas och skrivas om elektriskt.

Minnesmappad I/O — när en I/O-krets svarar på adresser som om den vore minne: att skriva till adressen styr en pinne.

Spegling (mirroring) — när en krets svarar på fler adresser än den behöver, eftersom chip select bara tittar på ett fåtal adressbitar.

## Program

Opcode — den första byten i en instruktion; talet som talar om vad processorn ska göra.

Operand — de följande 0–2 byten; data eller adress som instruktionen behöver.

Assembler — mänskligt läsbar 6502-kod (`LDX`, `STA`…) som översätts till maskinkod.

ca65 / ld65 — assembler och länkare från cc65-verktygslådan; bygger `.asm` till `.bin`.

Label — ett namn på en minnesadress i assembler, t.ex. `reset:` eller `fib_loop`.

Subrutin — ett namngivet kodblock som anropas med `JSR` och återvänder med `RTS`.

Carry-flagga — en minnesbit som minns om förra additionen rymdes; grunden för 16-bitars räkning i en 8-bitars CPU.

Branch — ett villkorligt hopp som beror på en flagga (`BEQ`, `BCC`, `BNE`…).

## Kretsar

VIA (W65C22) — I/O-krets med två 8-bitars portar (PA, PB) och kontrollpinnar; sitter på processorns bussar.

DDR — Data Direction Register; bestämmer om varje portpinne är utgång (1) eller ingång (0).

Port — en grupp pinnar som kretsen styr eller avläser som en byte.

74HC00 — krets med fyra NAND-grindar (14 pinnar); används här som adressavkodare.

LCD — flytande kristall-display (HD44780-kontroller) med parallell databuss och RS/E-signaler.

Avkopplingskondensator — en liten kondensator (100 nF) nära varje krets som filtrerar bort brus på strömförsörjningen.

Kristalloscillator — en komplett klockkrets i en kapsel (kristall + förstärkare): matning in, ren fyrkantsvåg ut. Här en 16 MHz-oscillator i DIL-14.

Ripple-räknare — en räknare där varje utsteg halverar ingångsfrekvensen (74HC393): 16 MHz → 8, 4, 2 och 1 MHz. Alla utgångar har 50% arbetscykel.

## Bygget

Kopplingsdäck — plåtar med förbundna hål som kopplar ihop komponenter utan lödning.

Kopplingstråd — trådar som förbinder hål på kopplingsdäcket.

Multimeter — instrument för att mäta spänning, ström och resistans; felsökningens viktigaste verktyg.

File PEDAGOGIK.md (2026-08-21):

# Pedagogisk analys av 6502-webbplatsen

Datum: 2026-08-19
Fokus: inlärningsupplevelsen i index.html + step1–11.html.
Viktning (per projektägaren): **jämn svårighetskurva utan plötsliga hopp** och **konkret byggbarhet** — man ska kunna bygga och testa fysiskt. Design/visualisering utvärderas som pedagogiskt verktyg, inte estetiskt.

## 1. Sammanfattning

Sajten är pedagogiskt stark: varje steg har Mål → Kopplingar (med *varför*) → Exempel på körning (med förväntad utdata) → Om det inte fungerar (med mätvärden), en genomgående berättelse och bra analogier (klocka = hjärtslag, R/W = trafikljus, buss = motorväg, Arduino = startmotor). Den stora styrkan är **konkretionen** — allt går att verifiera fysiskt.

De två svagaste punkterna, sett ur din viktning:

1. **Två plötsliga svårighetshopp**: steg 6→7 (VIA + 74HC00 + LCD-direkt + ett ~10× längre maskinkodsprogram på en gång) och steg 8→9 (från hello-program till Fibonacci med carry-aritmetik, stack och decimalomvandling i ett enda steg).
2. **Tre konkreta hål** där bygginstruktionen är ofullständig eller felaktig: step11 saknar kopplingsschema (placeholder), step8.html säger `pio run -t upload` (bygger nu default steg 9, inte steg 8), och step11.html pekar på `src/program.cfg` (filen ligger i `asm/`).

Därutöver: få aktiva lärande-markörer, ingen ordlista, ingen print-CSS, den mänskliga berättarrösten finns bara på index (se avsnitt 10) — och utseendet är inte helt enhetligt (se avsnitt 11).

## 2. Metod och kriterier

Analysen utgår från kriterierna i planen, med dina två viktningar överst:

1. **Jämn progression** — ett nytt konceptkluster per steg; inga hopp.
2. **Konkret byggbarhet** — varje steg ska gå att bygga och verifiera fysiskt.
3. Överblick och navigering.
4. Begrepp och förklaringar (definitioner, analogier, varför).
5. Aktivt lärande (övningar, experiment, kontrollfrågor).
6. Två spår: begrepp (hur en dator fungerar) och färdighet (bygga/felsöka).
7. Visualisering som pedagogiskt stöd.
8. Tillgänglighet/UX (mobil, kontrast, alt-texter, print).
9. **Röd tråd och berättarröst** (tillagt av projektägaren) — varje sida läses som en berättelse, inte en manual: mänsklig introduktion, konsekvent röst som bär genom hela sidan, framåtblickande avslut.
10. **Enhetligt utseende** (tillagt av projektägaren) — sidorna ska se ut som en serie: samma byggstenar (tabeller, kodblock, serielloggar, callouts, minneskartor), samma färger och formatering. Igenkänning hjälper läsaren.

## 3. Svårighetskurvan — kärnan

| Steg | Nya konceptkluster | Bedömning |
|---|---|---|
| 1 | Ström/5V, klocka (statisk CMOS), LED+motstånd, pull-ups, reset låg | Lugn start ✓ |
| 2 | Adressbuss, hex, reset-vektor $FFFC/$FFFD, portregister, seriemonitor | Mjuk ✓ |
| 3 | Databuss (dubbelriktad), R/W, tri-state/DDRA, minnesemulator, NOP-fallback | Största kodsteget hittills, väl förklarat ("kodens fyra lager") ✓ |
| 4 | SYNC, klocksteg vs instruktionssteg, debounce | Lätt ✓ |
| 5 | LCD 4-bit, LiquidCrystal, kontrastpot | Mjuk ✓ |
| 6 | Maskinkod (opcode/operand), little-endian, X-register, 4 opcodes | Mjuk — bra tabell per instruktion ✓ |
| 7 | **VIA + register + DDR + minnesmappad I/O + 74HC00-avkodning + chip select + LCD direkt från 6502 + tri-state-pass-through + program ~10× längre** | **HOPP ⚠** |
| 8 | Assembler (labels, JSR/RTS, segment, .byte/.word), ca65/ld65, program.cfg | Brant men utan ny hårdvara — acceptabelt |
| 9 | SRAM (CE/OE/WE), alla 4 NAND-grindar, zero page, **carry-aritmetik, stack, branchar, decimalomvandling** | **HOPP ⚠ (programmeringsfärdighet)** |
| 10 | EEPROM, bränning, andra Arduino + Python, sidprotokoll | Nytt arbetsflöde men begreppsmässigt lätt ✓ |
| 11 | Avkodningsdesign (chip select, spegling, minimal NAND), ny minneskarta | Djup men fokuserad, bra avslut ✓ |

### Hopp 1: steg 6 → 7

Steg 7 introducerar fem saker samtidigt: (a) vad en VIA är och dess register, (b) minnesmappad I/O med adressavkodning (74HC00 + chip select), (c) att 6502:an själv styr LCD:n via portpinnar, (d) tri-state-pass-through i Arduino-koden, (e) ett maskinkodsprogram som är en tiopotens längre än steg 6:s. Sektionerna är välstrukturerade (pinouts, registertabell, maskinkodstabell), men den samlade kognitiva belastningen är klart högst i hela serien.

**Förslag för att jämna ut:**
- Lägg till en kort konceptsektion "Så här fungerar en VIA" innan kopplingarna (register = brevlådor, DDR = vägskyltar för riktning, minnesmappad I/O = "chipet svarar på adresser som om det vore minne").
- Lägg en explicit "Vad är nytt i detta steg"-lista överst (Mål gör det delvis — gör checklistan fem punkter, en per kluster).
- Chunk:a maskinkodstabellen: först VIA-init, sedan LCD-init, sedan text — med en rubrik per chunk (tabellen har redan stegnummer — förstärk med delrubriker).

### Hopp 2: steg 8 → 9 (assembler-färdighet)

Steg 8 lär ut assembler med ett enkelt program (labels, JSR/RTS, LDA line1,x, .byte/.word). Steg 9 kräver på en gång: carry-aritmetik (CLC/ADC/SEC/SBC), branch-mönster (BCC/BNE), stack (PHA/PLA), jämförelseloopar (CMP), TXA/DEX/DEY, zero-page-variabler och en avancerad decimalomvandlingssubrutin. Texten förklarar allt väl — men *färdighetssteget* är stort, och till skillnad från steg 6 saknas en referenstabell över de nya instruktionerna.

**Förslag:**
- Lägg till en "Nya instruktioner i detta program"-tabell (som steg 6:s), med exempel på användning.
- Lägg till ett spårat exempel: "så här går det till när 144 ska visas" — följ show_num steg för steg (hundratal, tiotal, ental, mellanslagen).
- Alternativt/komplement: ett mellansteg — ett enkelt "räkna till 255 och visa på LCD" innan Fibonacci.

## 4. Konkret byggbarhet

**Styrkor (byggbarheten är sajtens bästa sida):**
- Varje steg har kopplingstabeller med *varför*-kolumn.
- Exempel på körning visar förväntad utdata (serieloggar, LCD-renderingar).
- Felsökningssektionerna ger mätbara kontroller (t.ex. steg 7: "PHI2 ~2,5 V medel, BE > 4,8 V, /CS2 LÅG vid $4000–$7FFF") och en logikanalysator-tips.
- Komponenttabeller per steg ("Nya komponenter").

**Hål:**
- **step11: inget kopplingsschema** — placeholder "Schema kommer snart". Det sista steget är det minst byggbara tills schemat finns. (Känt — pågår.)
- **step8.html "Så här använder du det": `pio run -t upload -t monitor`** bygger nu *default_envs = step9*, inte steg 8. Instruktionen måste vara `pio run -e step8 -t upload -t monitor`. (Introducerades när default ändrades — analysens tekniska runda ändrade default till steg 9 men step8.html uppdaterades inte.)
- **step11.html: "Öppna `src/program.cfg`"** — filen ligger i `asm/program.cfg`. Sökvägen leder fel.
- **step10.html:s exempel** anropar `python3 upload_eeprom.py …` — filen ligger nu i `scripts/`; exemplet bör visa korrekt sökväg (och `pio run -e step10` fungerar nu när env:step10 finns).
- Steg 6 saknar helt "Nya komponenter"-sektion (alla andra steg har en, även steg 11 med "inga nya kretsar!") — ett litet konsistenshål.

## 5. Överblick och navigation

- index.html är en stark ingång: SVG-blockschema, "Hur fungerar en 6502-processor?" (begreppsgrund), komponenttabell, stegtabell, minneskarta.
- **Saknas på översikten:** (a) en "vad du lär dig per steg"-karta (färdigheter/svårighet — skulle direkt adressera kurvan), (b) en "verktyg och programvara"-sektion (PlatformIO, ca65, Python, multimeter, kopplingsdäck) — i dag nämns verktyg först i steg 8, (c) en tidsuppskattning per steg.
- Sektionsordningen är förutsägbar på alla stegsidor ✓; TOC + prev/next finns ✓.
- Namn-inkonsekvens: steg 1 använder "Komponenter för detta steg", övriga "Nya komponenter"; steg 7 använder "Kopplingar — krets för krets".

## 6. Begrepp och förklaringar

- **Styrka:** nya begrepp definieras i regel vid första användning (little-endian, opcode/operand, tri-state, chip select …), och många "varför"-förklaringar är utmärkta (100 Ω-skyddet i steg 3, DDRA-timing, avkodningens logik i steg 11).
- **Ingen ordlista/begreppssida finns.** För en serie med ~30 facktermer vore en appendix-sida (eller en sektion på index) värdefull: opcode, operand, little-endian, hex, pull-up, tri-state, DDR, chip select, zero page, fallande flank, spegling …
- **Terminologi-inkonsekvens:** samma signal skrivs R/W (39 förekomster), RWB (30) och Read/Write (4). Föreslå en standard: R/W för signalen i text, RWB när pinnen (CPU pin 34) avses — och enhetlig genomgång.
- "körs på 6502:an — inte på Arduino" markeras explicit först i steg 7–8; steg 6 borde ha samma tydliga markering (programmet laddas in av Arduino men exekveras av processorn).

## 7. Aktivt lärande

- **Få markörer:** "Lägg märke" (4), "Prova att" (1), "Testa" (1). Inga övningar, inga självtest, inga "fundera på"-frågor.
- Det enda experimentet (ändra CLOCK_HZ i steg 1) är bra — samma mönster saknas i senare steg.
- **Förslag:** avsluta varje steg med 1–2 "Prova själv"-förslag (ändra texten på LCD, räkna baklänges, flytta en koppling och se vad som händer, mät med multimetern…). Kostar lite, höjer lärandet mycket.
- Felsökningssektionerna ger facit per symptom; ett par rader om *metod* (mät → isolera → verifiera) skulle lära ut tänkandet, inte bara svaren.

## 8. Visualisering som pedagogiskt stöd

- **Styrkor:** konsekvent färgkodning (grön = SRAM, gul = VIA, lila = EEPROM, blå = Arduino) genom index, minneskartor och loggar; pinout-SVG:er på varje ny krets; minneskartor som staplar; sanningstabell i steg 11; LCD-renderingar i Exempel-sektionerna.
- Färgbetydelsen finns förklarad i index ("■ Adressbuss…") och i minneskartorna — men inte på varje sida där färgerna används; en återkommande enradslegend vore hjälpsamt.
- Några SVG:er har role="img" + aria-label (index, steg 1/5/7/9/10), andra saknar — enhetlighet saknas.

## 9. Tillgänglighet och UX

- **Mobil:** tabeller rullar (overflow-x-auto), SVG:er skalar, nav wrappar — bra.
- **Print saknas:** ingen `@media print` — utskrift/PDF ger mörk nav och bakgrundsfärger. För en byggserie man gärna skriver ut är detta värt en liten CSS.
- Kontrast och teckenstorlek är i allmänhet bra.
- Minnesskartorna (div-baserade) saknar motsvarighet till alt-text — mindre.

## 10. Röd tråd och berättarröst

Kriterium (tillagt av projektägaren): varje sida ska ha en röd tråd och en tydlig röst som berättar — från början med en mänsklig introduktion. Ingen sida ska kännas rörig.

**Nuläget:**
- **index.html har den mänskliga "jag"-rösten** (”Ända sedan jag först läste om hur enkla 8-bitarsprocessorer fungerar har jag drömt om att bygga en egen dator…”). Stegsidorna har nästan ingen "jag"-röst — de är skrivna i instruktiv "vi"-form.
- **Mål-sektionerna har redan en sorts berättarröst** (”I steg 1 gav vi…”, ”Hittills har… Nu kopplar vi in…”, ”Det kändes slarvigt”) — konsekvent och med bakåt-/framåtreferenser. Det är seriens starkaste tråd.
- **Tråden bryts i sidornas mitt och slut:** referensblock (pinouts, tabeller, minneskartor) staplas utan övergångsmeningar, och ingen sida slutar med en framåtblick — ”Om det inte fungerar” följs direkt av prev/next-länkar. Undantag: step11:s ”Lägg märke till skillnaden mot steg 10…”.

**Per-sida-bedömning:**

| Sida | Öppning/röst | Tråd genom sidan | Rörighet |
|---|---|---|---|
| index | Utmärkt — personlig "jag"-röst | Bra | Ren |
| 1–6 | Bra öppningar (”Alla datorer behöver en puls”, ”Dags att skriva vårt första egna 6502-program!”) | Bra | Rena |
| 7 | Bra öppning (”Nu tar vi nästa stora kliv”) | Finns men tunnas ut — mitten är flera stora referensblock i rad | Tätast sidan (inte fel ordning, men rösten bär inte läsaren genom mitten) |
| 8 | Bra öppning | **Trådbrott:** ”Minneskarta” ligger mitt i byggkedje-berättelsen, och ”Så här använder du det” kommer efter kod-detaljerna | Rörig sektionsordning |
| 9 | Bra öppning (”vackrare än hello-programmet”) | Bra | Ren |
| 10 | Bra; världsbytena programmerare/dator är tydligt markerade (”Den andra Arduino…”, ”Först programmeraren… Sedan datorn…”) | Bra | Lång men markerad |
| 11 | Bra öppning (”Det kändes slarvigt”) | Bra | Hål: schema-placeholder mitt i tråden |

**Förslag (innehållsarbete):**
1. Lägg en kort personlig öppningsrad överst på varje stegsida (före eller som första mening i Mål) — samma "jag" som på index (t.ex. steg 6: ”Det är en speciell känsla första gången en dator du byggt själv kör ett program du skrivit själv.”).
2. Lägg en framåtblickande avslutning före prev/next-länkarna på varje sida — ”Vad händer härnäst” (t.ex. steg 1: ”Nu när processorn har puls kan vi börja prata med den — nästa steg kopplar in adressbussen.”).
3. Steg 8: flytta ”Minneskarta” ut ur byggkedje-berättelsen och ”Så här använder du det” närmare ”Byggkedjan”, så ordningen följer berättelsen: Mål → Nya verktyg → Byggkedjan → PlatformIO-byggskript → Så här använder du det → 6502-programmet i assembler → Arduino-kod → Minnestarta → Exempel på körning → Om det inte fungerar.
4. Steg 7: lägg korta övergångsmeningar mellan de stora referensblocken (pinout → kopplingar → minneskarta → program) så rösten bär läsaren.

## 11. Enhetligt utseende

Kriterium (tillagt av projektägaren): sidorna ska se ut som en serie — samma byggstenar, samma färger, samma formatering. Igenkänning hjälper läsaren att hitta rätt typ av innehåll.

**Vad som redan är enhetligt:**
- Tabeller: exakt samma klass överallt (`w-full … bg-white rounded-lg shadow`) ✓
- Kodblock: samma vita stil (`bg-white … border`) på alla sidor ✓
- Minnesskartor: färgade staplar (grön SRAM / gul VIA / lila EEPROM) på steg 6–11 ✓
- Nav, footer, TOC, prev/next: konsekventa ✓

**Inkonsekvenser:**
1. **Seriellog-stilen finns i två varianter.** Standard är `bg-gray-900 text-green-400 p-3 rounded-lg overflow-x-auto` — men step2, step5 och step8 har en äldre variant (`text-gray-100`, `rounded` utan `rounded-lg`, utan `overflow-x-auto`).
2. **Callout-rutor används ojämt.** Färgade rutor (röd = varning, grön = tips/notis, gul = steg 11) finns på step1/3/6/7/8/11 men inte alls på step2/4/5/9/10. Samma typ av notis är ruta på en sida och vanligt stycke på en annan.
3. **step8 använder nästan inga signal-spans** (1 förekomst jämfört med 20–60 på övriga sidor) — signalnamn formateras därmed annorlunda där.
4. **Chip-fetstilen är inte helt genomförd:** steg 11 fetar inte ”Arduino” (0 förekomster, jämfört med 4–14 på andra sidor).

**Förslag:**
1. Uppdatera seriellog-blocken i step2/5/8 till standardstilen.
2. Definiera callout-konventionen (grön = tips/”lägg märke”, röd = varning, gul = notis) och tillämpa den konsekvent — eller konvertera befintliga rutor till vanliga stycken så att byggstenen försvinner helt.
3. Lägg signal-spans i step8 där signalnamn nämns.
4. Städa chip-fetstil i step11 (CPU, Arduino, SRAM, VIA, EEPROM, LCD, 74HC00).

## 12. Per-steg-bedömning

| Steg | Pedagogik | Byggbarhet | Kommentar |
|---|---|---|---|
| 1 | Bra | Bra | Experimentet med CLOCK_HZ är föredömligt |
| 2 | Bra | Bra | Reset-vektorn förklaras väl |
| 3 | Utmärkt | Bra | "Kodens fyra lager" + trafikljus-analogin |
| 4 | Bra | Bra | SYNC-konceptet tydligt |
| 5 | Bra | Bra | LiquidCrystal förklaras på rätt nivå |
| 6 | Utmärkt | Bra | Instruktionstabellen är mönsterexempel; saknar "körs på 6502"-markering och "Nya komponenter"-sektion |
| 7 | Strukturerad men överlastad | Bra | Det stora hoppet; felsökningen är den bästa i serien |
| 8 | Bra | **Hål** | Fel env-kommando i "Så här använder du"; annars bra byggkedjeförklaring |
| 9 | Bra förklaring, stort färdighetssteg | Bra | Saknar instruktionsreferens och spårat exempel |
| 10 | Bra | Bra | Tvåfas-flödet (bränn → flytta) är konkret; sökvägar till filer bör stämmas |
| 11 | Utmärkt konceptuellt | **Hål** | Saknar schema + fel program.cfg-sökväg |

## 13. Prioriterad åtgärdslista

**Snabba fixar (dokument, liten insats):**
1. ✅ step8.html: `pio run -t upload` → `pio run -e step8 -t upload -t monitor` (alla tre ställen).
2. ✅ step11.html: `src/program.cfg` → `asm/program.cfg`.
3. ✅ step10.html: `python3 scripts/upload_eeprom.py …` i exemplet + println i kodblocket (och EEPROM_programmer.ino synkat).
4. ✅ Steg 6: ny sektion ”Nya komponenter — inga, samma hårdvara” + markeringen ”Lägg märke till: programmet körs på 6502-processorn”.
5. ✅ Terminologi: granskad — RWB förekommer bara i kod (makronamn, korrekt) och R/W i löptext (korrekt). Ingen ändring behövdes.
6. ✅ Print-CSS tillagd i style.css (@media print). SVG:erna hade redan role="img" — ingen ändring behövdes där.

**Innehållsarbete (större insats):**
7. ✅ Steg 7: ny sektion ”Så här fungerar en VIA” (register = brevlådor, DDR, minnesmappad I/O, chip select, fallande flank) + ”Vad är nytt i det här steget?”-checklista. Maskinkodstabellen var redan chunkad med delrubriker.
8. ✅ Steg 9: tabell över nya instruktioner (CLC/ADC/BCC/SBC/CMP/PHA/PLA/TXA/DEX/DEY/BNE/zero page) + spårat exempel ”Så här visas 144”.
9. ✅ ”Prova själv”-förslag i slutet av varje steg (h3 i Exempel på körning) — 11 sidor.
10. ✅ Ny begrepp.html (5 grupper, ~30 begrepp) + ”Vad du lär dig per steg”-karta och ”Verktyg och programvara” på index; begreppslänk i navet på alla sidor.
11. ✅ Enhetlig färglegend (blå/grön/gul/lila/grå) i minneskartorna på steg 6–11.
12. ✅ Personlig öppningsrad överst på varje stegsida — samma ”jag”-röst som på index.
13. ✅ Framåtblickande avslut (”Vad händer härnäst?”) före prev/next-länkarna på varje sida.
14. ✅ Steg 8: sektionsordning omstrukturerad så byggkedjan följer berättelsen (”Så här använder du det” fick också sin saknade section-wrapper). Steg 7: förbättrat med två nya sektioner; övergångsmeningar mellan varje enskilt referensblock återstår som kosmetisk finputs.
15. ✅ Seriellog-blocken i step2/5/8 → standardstilen (text-green-400, rounded-lg, overflow-x-auto).
16. ✅ ”Om det inte fungerar”-boxen borttagen på step10/11 (nu som övriga sidor, med inledningen ”Här är några saker att kontrollera:”). Konvention: standardsektioner utan box; färgade rutor reserveras för ⚠-varningar (steg 3), byggkedjekort (steg 8) och gammal/ny-jämförelser (steg 11).
17. ✅ step8: RS/E signal-spans i löptexten. step11:s ”Arduinon” verifierad — bestämd form fetas inte någonstans (samma praxis som steg 3), ingen ändring behövdes.
Bonus: step2–6.html:s visade kodblock synkade med den rättade adressformeln (K3-komplettering) — referenssidorna matchar nu repo-koden.

**Pågår hos projektägaren:** steg 11-schemat (bygger för närvarande på att det blir klart).

Inga ändringar görs utan godkännande — säg till vilka punkter du vill att jag utför (jag kan börja med de snabba fixarna 1–6).

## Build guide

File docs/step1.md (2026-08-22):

# Strömmatning och klocka

Det är något speciellt i att hålla en processor i handen och veta att den snart ska vakna.

## Mål

Alla datorer behöver en puls. ETt hjärtslag som får processorn att ta ett steg i taget. I det här första steget kopplar jag in ström och klocka till **W65C02S**-processorn, eller CPU. CPU:n kommer inte att *göra* något ännu (jag har varken minne eller program), men jag kan verifiera att den lever.

**W65C02S** är en *statisk CMOS-krets*. Det betyder att klockan kan vara hur långsam som helst — till och med stoppas helt — utan att CPU:n tappar sitt interna tillstånd. 

En lysdiod kopplas till klocklinjen. När dioden blinkar vet jag att klockpulsen når fram. Med en multimeter mäter jag också att CPU:n får `5V` mellan `VDD` och `VSS`.

## Komponenter för detta steg

Här är allt som krävs för att väcka CPU:n till liv.

??? note "📦 Komponenter — CPU, klocka och ström"

    | Antal | Komponent | Namn |
    |---|---|---|
    | 1 | W65C02S (DIP-40) | CPU |
    | 1 | Arduino Mega 2560 | Kontrollenhet |
    | 1 | Lysdiod (röd) | D1 |
    | 1 | 220 Ω motstånd (klock-LED) | R6 |
    | 5 | 10 kΩ motstånd (pull-up: RDY, IRQB, NMIB, SOB) | R1, R2, R3, R4, R5 |
    | 1 | 100 nF keramisk kondensator (avkoppling CPU) | C1 |

## W65C02S pinout

Här är alla pinnar på **W65C02S**-processorn. 

W65C02S pinout

## Arduino Mega 2560 pinout

Här är alla pinnar på **Arduino Mega 2560**.

Arduino Mega 2560 pinout

## Kopplingsschema

Så här ser det kompletta kopplingsschemat ut när allt ligger på kopplingsdäcket: CPU:n till vänster, Arduino till höger, lysdiod och pull-up-motstånd på sina platser. 

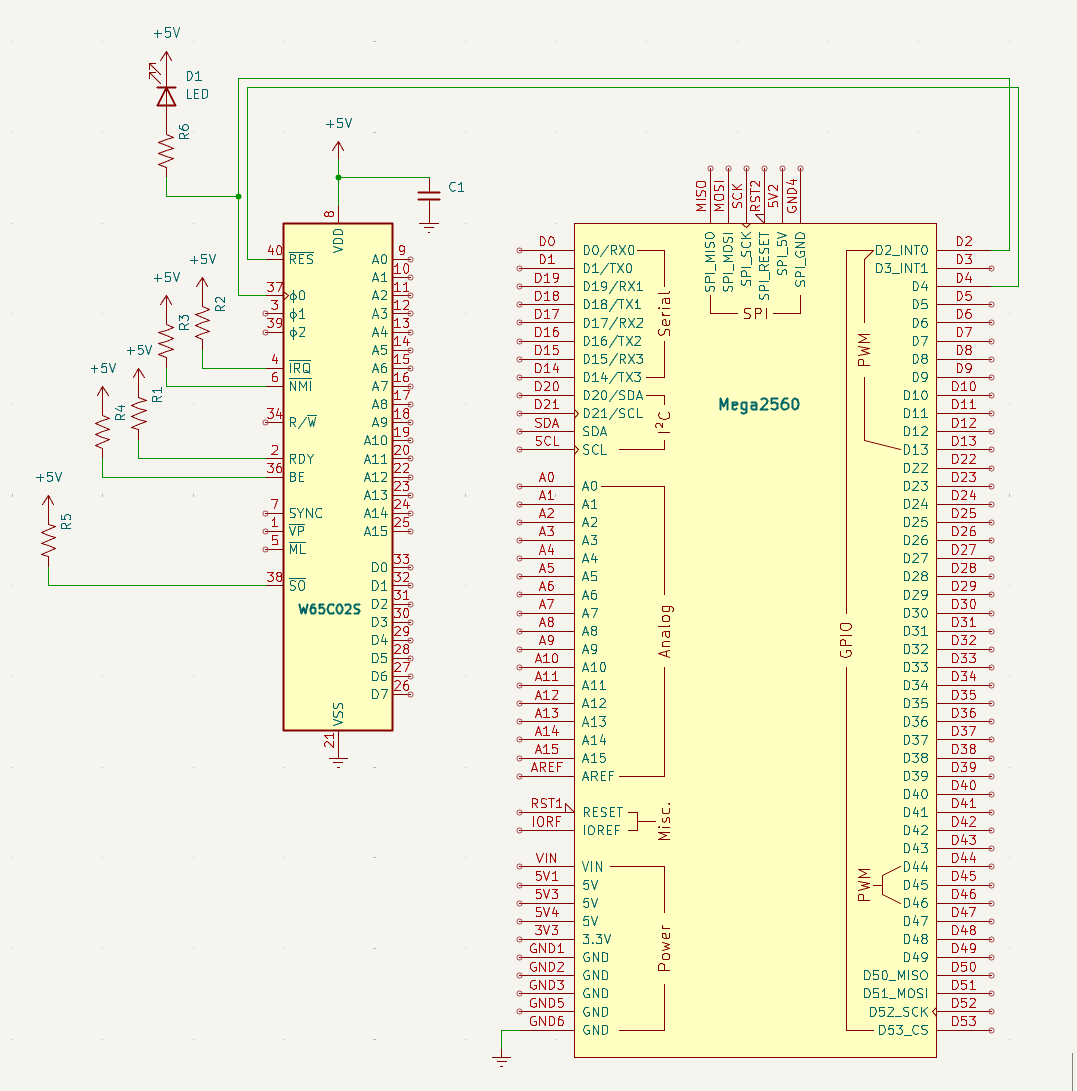
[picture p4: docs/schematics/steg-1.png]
Steg 1 — Ström och klocka


## Kopplingar

Här är varenda koppling i steg 1, pinne för pinne. Avkopplingskondensatorn är markerad separat längst ner.

??? note "📦 Kopplingar — CPU, klocka och ström"

    | Pin | Signal | Kopplas till | Varför |
    |---|---|---|---|
    | 8 | `VDD` | +5V | Strömmatning — CPU:ns driftspänning |
    | 21 | `VSS` | GND | Systemjord — sluten krets |
    | 37 | `PHI2` | Arduino D2 | Klockingång — Arduino skickar fyrkantsvåg |
    | 2 | `RDY` | +5V via 10kΩ | Ready — HÖG = CPU får köra. Utan denna stannar CPU:n |
    | 4 | `/IRQ` | +5V via 10kΩ | Interrupt request — HÖG = inget avbrott (jag använder ej avbrott än) |
    | 6 | `/NMI` | +5V via 10kΩ | Non-maskable interrupt — måste vara HÖG, annars kraschar CPU:n |
    | 36 | `BE` | +5V via 10kΩ | Bus Enable — HÖG = bussarna aktiva. Utan denna är CPU:n bortkopplad! |
    | 38 | `/SO` | +5V via 10kΩ | Set Overflow — HÖG = avaktiverad |
    | 40 | `/RESET` | Arduino D4 | Hålls låg av Arduino — CPU:n ligger i reset |
    | — | 100nF | Mellan VDD (pin 8) och VSS (pin 21) | Avkopplingskondensator — filtrerar bort brus på strömmatningen. Sätt den så nära CPU:n som möjligt! |

## Arduino-kod

Nu ska jag skriva koden som väcker processorn till liv. Det här är första gången jag laddar upp något till **Arduinon** — och det är ett perfekt tillfälle att förstå hur ett **Arduino**-program är uppbyggt.

### Så fungerar ett Arduino-program

Varje **Arduino**-program består av två funktioner som plattformen anropar automatiskt:

- `setup()` — körs *en enda gång* när **Arduinon** startar (eller efter reset). Här konfigurerar jag pinnar, startar seriekommunikation och initierar allt som behöver vara klart innan programmet börjar loopa.
- `loop()` — körs *om och om igen i all oändlighet*. Varje varv i loopen är en chans att läsa sensorer, uppdatera utgångar eller — som i mitt fall — generera en klockpuls.

### Kodens arkitektur i detta steg

Koden är uppdelad i tre lager:

1. **Definitioner och konstanter** — längst upp definierar jag pinnar (`PHI2`, `RESB`) och räknar ut klockfrekvensen. Genom att använda namngivna konstanter istället för magiska siffror blir koden läsbar och lätt att ändra — vill jag testa en snabbare klocka ändrar jag bara `CLOCK_HZ`.
2. **Hjälpfunktionen** `pulse()` som genererar en komplett klockcykel. Funktionen drar `PHI2` HÖG i 500 ms (lysdioden lyser), sedan LÅG i 500 ms (lysdioden släcks). Resultatet är en symmetrisk fyrkantsvåg på 1 Hz — tillräckligt långsamt för att jag ska kunna följa med i vad som händer. 
3. **Funktionerna** `setup()` och `loop()` — i `setup()` konfigurerar jag pinnar, håller CPU:n i reset och startar seriekommunikation. I `loop()` anropar jag bara `pulse()`.

### Vad jag ser när koden kör

När jag laddat upp koden och öppnar seriemonitorn ser jag texten "Steg 1 — Klocka och ström". Lysdioden på klocklinjen blinkar en gång per sekund — den är tänd när `PHI2` är hög (CPU:n arbetar) och släckt när `PHI2` är låg. Jag har just gett processorn dess första hjärtslag.

??? note "📦 Arduino-kod"

    ```cpp
    --8<-- "Mega_2560_6502/src/step1.inc"
    ```

## Exempel på körning

När jag öppnar seriemonitorn i **VS Code** eller **PlatformIO** ser jag:

```text title="Terminal"
Steg 1 — Klocka och ström
Lysdioden på PHI2 ska blinka 1 Hz
```

Jag provar att ändra `CLOCK_HZ` från `1` till `10` och laddar upp igen. Dioden blinkar nu tio gånger per sekund — för snabbt för att urskilja enskilda pulser, men jag ser att den lyser svagare eftersom den är släckt halva tiden. Det här är samma princip som senare steg använder när klockan körs i 500 Hz — då syns inte blinkandet alls, men processorn jobbar för fullt.

## Så här felsöker man

Här är några saker att kontrollera om koden inte beter sig som förväntat:

- Dioden blinkar inte? Då kontrollerar jag att jag har rätt pinne (`D2`), att dioden är rättvänd (långa benet till `D2` via motstånd, korta till `GND`), och att motståndet är 220Ω.
- Dioden lyser konstant? Då har jag förmodligen glömt `delay()` eller har en kortslutning.
- Spänningen under 4.8V? Då använder jag en 12V DC-adapter i Arduinons barrel-jack. USB-portar ger ofta för låg spänning.
- Jag glömmer inte avkopplingskondensatorn! 100nF keramisk mellan `VDD` och `VSS`, så nära CPU:n som möjligt. Utan den kan CPU:n bete sig oberäkneligt.

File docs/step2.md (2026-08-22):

# Adressbuss och reset

Första gången jag såg en **6502** leta upp sin egen startadress i seriemonitorn var ögonblicket då allt föll på plats.

## Mål

I steg 1 gav jag processorn ström och klocka. Nu ska jag ge den kontroll över adressbussen — 16 ledningar som talar om *var* i minnet CPU:n vill läsa eller skriva.

Alla **6502**-processorer startar på samma sätt: efter reset läses den sk reset-vektorn på adress `$FFFC` och `$FFFD` för att få reda på var programmet börjar. Det är inbyggt i kisel — ingen mjukvara, ingen konfiguration. 

Jag kopplar också in `/RESET` (pin 40) till Arduino `D4`. När jag håller `RESB` låg i minst 2 klockcykler nollställs CPU:ns interna register. När jag sedan släpper den (HÖG) börjar CPU:n köra från reset-vektorn.

## Nya komponenter

Det här steget kräver inga nya elektroniska komponenter bara kopplingstrådar. Sexton stycken för adresslinjerna `A0–A15` och en extra för reset-signalen, eftersom jag nu tar kontroll över CPU:ns uppstart via `/RESET`.

| Antal | Komponent |
|---|---|
| 17 | Kopplingstrådar (16 adress + 1 `RESB`) |

## Kopplingsschema

Schemat visar den nya kopplingen: 16 adresslinjer som löper från CPU:ns `A0–A15` till Arduinons analoga portar `A0–A15`, plus reset-signalen från `D4` till `/RESET`. Allt annat är oförändrat från steg 1.

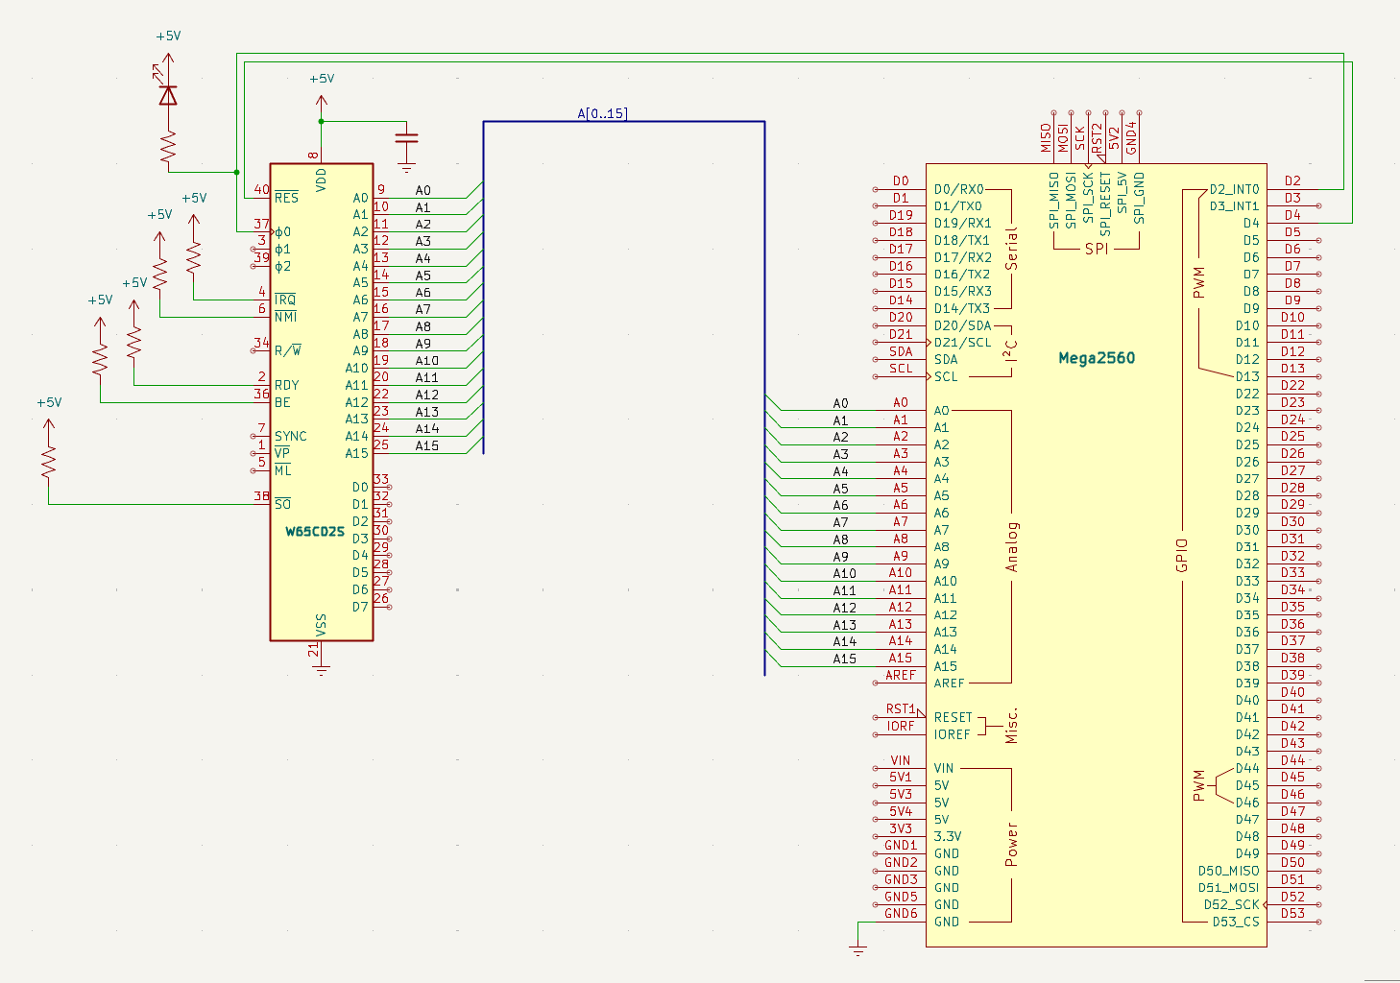
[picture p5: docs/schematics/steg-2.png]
Steg 2 — adressbuss och reset


## Kopplingar

Här är varenda koppling i steg 2, pinne för pinne. 

??? note "📦 Kopplingar — CPU, klocka, ström, adressbuss och reset"

    | Pin | Signal | Kopplas till | Varför |
    |---|---|---|---|
    | 8 | `VDD` | +5V | Strömmatning — CPU:ns driftspänning |
    | 21 | `VSS` | GND | Systemjord — sluten krets |
    | 37 | `PHI2` | Arduino D2 | Klockingång — Arduino skickar fyrkantsvåg |
    | 2 | `RDY` | +5V via 10kΩ | Ready — HÖG = CPU får köra. Utan denna stannar CPU:n |
    | 4 | `/IRQ` | +5V via 10kΩ | Interrupt request — HÖG = inget avbrott |
    | 6 | `/NMI` | +5V via 10kΩ | Non-maskable interrupt — måste vara HÖG |
    | 36 | `BE` | +5V via 10kΩ | Bus Enable — HÖG = bussarna aktiva. Utan denna är CPU:n bortkopplad! |
    | 38 | `/SO` | +5V via 10kΩ | Set Overflow — avaktiverad |
    | 40 | `/RESET` | Arduino D4 | Kontrollerad reset — Arduino håller CPU:n i reset tills jag är redo |
    | 9–16 | `A0–A7` | Arduino A0–A7 | Låga adressbyte — läses via PORTF |
    | 17–20, 22–25 | `A8–A15` | Arduino A8–A15 | Höga adressbyte — läses via PORTK |

## Arduino-kod

I steg 1 gav jag processorn liv. Nu ska jag lyssna på vad den säger. Koden i detta steg gör något fundamentalt: den *läser av processorns adressbuss* — 16 ledningar som tillsammans talar om var i minnet CPU:n vill läsa — och skriver ut adressen i seriemonitor. Det är som att koppla in en logikanalysator, fast gratis.

### Portregister — att läsa 8 pinnar på en gång

**Arduino Mega 2560** har 54 digitala pinnar, men att läsa dem en och en med `digitalRead()` är alldeles för långsamt. Varje anrop tar flera mikrosekunder — och med 16 adresslinjer skulle jag tappa synkroniseringen med processorn direkt. Lösningen är *portregister* — specialregister som läser eller skriver 8 pinnar samtidigt i en enda maskininstruktion:

- `DDRF = 0x00` — sätt alla 8 pinnar på `PORTF` som ingångar. Motsvarar 8 × `pinMode()` men går på några nanosekunder.
- `PINF` — läs alla 8 pinnar på en gång. Varje bit i byten motsvarar en pinne. Här är det CPU:ns `A0–A7`.
- `PINK` — läser CPU:ns `A8–A15` på samma sätt.

För att få ihop en 16-bitars adress skiftar jag ihop de två byten:

```asm
uint16_t addr = (PINF << 0) | (PINK << 8);
```

Resultatet är ett tal mellan 0 och 65 535 — processorns fullständiga adressrymd.

### Reset-sekvensen — vad som händer när CPU:n vaknar

Koden gör tre saker i `setup()`:

1. Håller CPU:n i reset — `RESB = LOW` i minst 2 klockcykler (jag kör 5 för säkerhets skull). Under denna tid är CPU:ns interna register nollställda och bussarna är tri-state.
1. Släpper reset — `RESB = HIGH`. Detta är ögonblicket CPU:n vaknar. Den gör inget val, fattar inget beslut — den läser helt enkelt reset-vektorn på adress `$FFFC` och `$FFFD`.
1. Läser och loggar — i `loop()` läser jag adressbussen i varje klockcykel och skriver ut den. Första två raderna kommer alltid att vara `$FFFC` och `$FFFD` — reset-vektorn. Det är processorns sätt att fråga "var ska jag börja?".
### Vad som är nytt jämfört med steg 1

Klockan har höjts från 1 Hz till 500 Hz — för snabbt för att se med ögat, men lagom för att läsa adressbussen i seriemonitor. `pulse()` har förenklats (ingen lysdiod denna gång) och `loop()` gör nu det tunga jobbet: läsa portregister, skifta ihop adressen, skriva ut. `setup()` har fått en reset-sekvens — den viktigaste nyheten i detta steg.

??? note "📦 Arduino-kod"

    ```cpp
    --8<-- "Mega_2560_6502/src/step1.inc"
    ```

## Exempel på körning

När jag öppnar seriemonitor efter uppladdning ser jag ungefär detta:

```text title="Terminal"
Steg 2 — adressbuss och reset
R $FFFC
R $FFFD
R $8000
R $8001
R $8002
R $8003
Klar — nu loopar vi:
R $8004
R $8005
R $8006
...
```

Varje rad börjar med `R` (Read — CPU:n läser) följt av `$` och en hexadecimal adress. De två första raderna är alltid `$FFFC` och `$FFFD` — reset-vektorn. Processorn frågar "var ska jag börja?" och svaret (som just nu är skräp eftersom databussen inte är inkopplad) leder den till någon adress — ofta `$8000` eller `$0000` beroende på vad som ligger på de flytande datalinjerna.

Lägg märke till att `$FFFC` och `$FFFD` bara dyker upp en gång — efter reset. Sedan räknar adresserna uppåt när CPU:n hämtar instruktioner. Utan databuss (steg 3) kan CPU:n inte hämta riktiga opcodes, men adressbussen fungerar redan — och det är precis vad jag ville bevisa.

## Så här felsöker man

Här är några saker att kontrollera om koden inte beter sig som förväntat:

- Ser jag bara `0` eller `1`? Då är CPU:n fortfarande i reset eller `BE` är LÅG. Jag kontrollerar att `RESB` går HÖG efter reset-sekvensen, och att `BE` har +`5V`.
- Ser jag `FFFC` men inte `FFFD`? Då är någon adresslinje felkopplad. Jag dubbelkollar `A0–A15` en och en.
- Skräptecken i seriemonitor? Då måste baud rate vara 115200. Jag kontrollerar `platformio.ini` om jag använder PlatformIO.

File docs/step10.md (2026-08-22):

# EEPROM som ROM

Det här är steget där datorn slutar vara ett bygge och blir en maskin: slå av strömmen, slå på den — och den startar ändå. Programmet sitter i kisel nu.

## Mål

Hittills har Arduino levererat 6502-programmet — varje gång CPU:n läser från `$8000` och uppåt är det Arduinons minnesarray som svarar. Det fungerar utmärkt, men en riktig dator har sitt program i ROM — icke-flyktigt minne som överlever strömavbrott. Nu tar jag det sista stora klivet: jag bränner in programmet på en **AT28C256** EEPROM och låter den ersätta Arduino som ROM.

En *andra Arduino Mega* används som EEPROM-programmerare. Via USB tar den emot en `.bin`-fil från datorn, bränner den på **AT28C256**, och verifierar att varje byte sitter rätt. Sedan flyttar jag EEPROM-chippet till datorns kopplingsdäck — och datorn startar direkt från äkta ROM, precis som en Commodore 64 eller Apple II.

Arduinon på kopplingsdäcket finns kvar som klocka och diagnostikverktyg.

## Nya komponenter

En **AT28C256** EEPROM på 32 KB blir datorns ROM, en extra Arduino Mega agerar programmerare som bränner programmet, en extra 74HC00 avkodar `$8000`–`$FFFF` för EEPROM:et, och en kondensator avkopplar strömmen.

| Antal | Komponent | Används till |
|---|---|---|
| 1 | AT28C256 (32KB EEPROM, DIP-28) | Programminne — ersätter Arduino för $8000–$FFFF |
| 1 | Arduino Mega 2560 (extra) | EEPROM-programmerare — används endast vid bränning |
| 1 | 74HC00 (extra) | Adressavkodning för EEPROM — /CE vid $8000–$FFFF |
| 1 | 100 nF keramisk kondensator | Avkoppling vid EEPROM:ets VCC/GND |
| — | Kopplingstråd | Adress, data, kontroll |

## AT28C256 — pinout

DIP-28-kapsel. 15 adresslinjer, 8 datalinjer, 3 kontrollsignaler. Nästan identisk med 62256 SRAM men med `/WE` som styr bränning och RDY/BUSY som signalerar när bränningen är klar (jag använder en enkel timeout istället).
AT28C256 pinout

## Kopplingsschema — programmeraren

Den andra Arduino Mega kopplas 1:1 till AT28C256. Här finns inga andra kretsar — bara Arduino, EEPROM, och 100Ω skyddsmotstånd på databussen. När bränningen är klar kopplas allt isär.

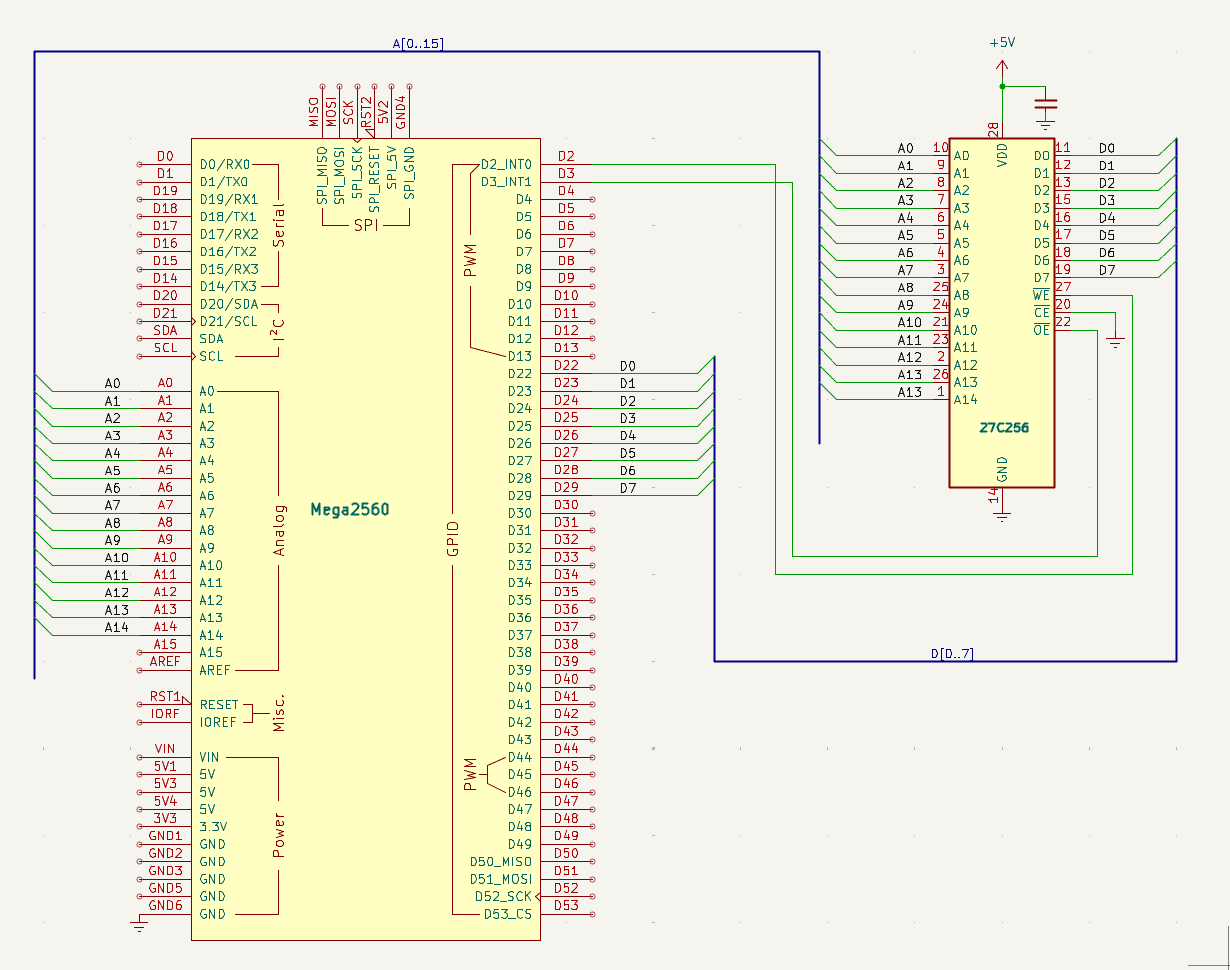
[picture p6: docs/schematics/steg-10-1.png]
Steg 10 — EEPROM-programmerare


## Kopplingsschema — datorn med EEPROM

EEPROM:et sitter nu på datorns adress- och databuss tillsammans med SRAM, VIA och Arduino. En extra 74HC00 avkodar `A15` till `/CE` — EEPROM:et aktiveras vid `$8000–$FFFF`.

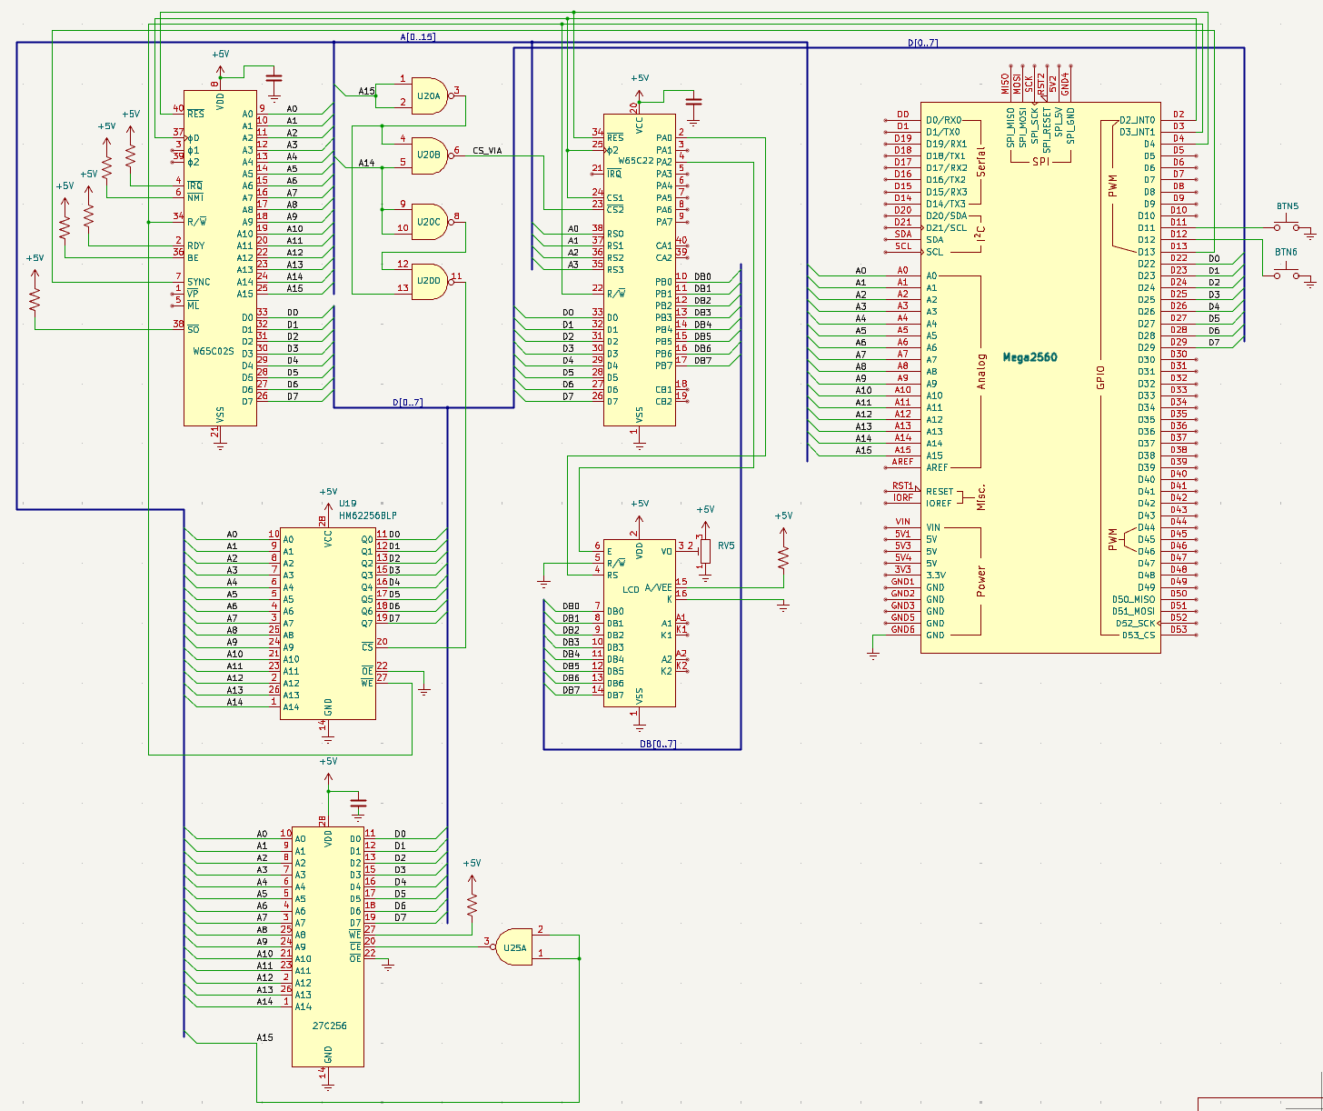
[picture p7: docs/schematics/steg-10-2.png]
Steg 10 — datorn med EEPROM


## Kopplingar

Först programmeraren — en enkel 1:1-koppling. Sedan datorn — fyra enheter på samma buss.

### Programmeraren — Arduino till AT28C256

Här är kopplingarna när den extra Arduinon programmerar EEPROM:et.

??? note "📦 Kopplingar — Arduino och EEPROM"

    | Signal       | Arduino         | AT28C256               | Varför                                         |
    | ------------ | --------------- | ---------------------- | ---------------------------------------------- |
    | `VDD`, `VSS` | 5V, GND         | `VDD` (28), `VSS` (14) | Strömmatning — glöm inte 100nF avkoppling      |
    | `A0–A7`      | A0–A7 (PORTF)   | `A0–A7`                | Låga adressbyte — vilken byte som ska brännas  |
    | `A8–A14`     | A8–A14 (PORTK)  | `A8–A14`               | Höga adressbyte — 15 bitar = 32 768 adresser   |
    | `D0–D7`      | D22–D29 (PORTA) | `D0–D7` via 100Ω       | Data — samma portregister som alltid           |
    | `/WE`        | D2              | `/WE` (27)             | Write Enable — pulsas LÅG för att bränna       |
    | `/OE`        | D3              | `/OE` (22)             | Output Enable — LÅG vid läsning/verifiering    |
    | `/CE`        | GND             | `/CE` (20)             | Chip Enable — alltid aktiv under programmering |

### Datorn — EEPROM på bussen

Här är kopplingarna när EEPROM:et sitter på datorns adress- och databuss tillsammans med SRAM, VIA och Arduino. 

??? note "📦 Kopplingar — CPU, VIA, SRAM, Arduino och EEPROM"

    | Pin | Signal | Ansluts till | Varför |
    |---|---|---|---|
    | 28, 14 | `VDD`, `VSS` | +5V, GND | Strömmatning |
    | 1–10, 21–26 | `A0–A14` | CPU `A0–A14` | Delad adressbuss med SRAM, VIA, Arduino |
    | 11–13, 15–19 | `D0–D7` | CPU `D0–D7` via 100Ω | Delad databuss |
    | 20 | `/CE` | 74HC00-utgång | Aktiveras vid $8000–$FFFF (A15=1) |
    | 22 | `/OE` | GND | Alltid läs ut — EEPROM är read-only i datorn |
    | 27 | `/WE` | +5V | Aldrig skriva — ROM-läge |

### 74HC00 — EEPROM-avkodning (ny grind)

En extra 74HC00 vid sidan av den från steg 7/9. En enda grind används som inverterare för `A15`.

??? note "📦 Kopplingar — 74HC00 för EEPROM"

    | Pin | Signal | Kopplas till | Varför |
    |---|---|---|---|
    | 1, 2 | `A15` (in) | CPU `A15` | Båda ingångarna till A15 → NAND = NOT A15 |
    | 3 | NOT `A15` (ut) | EEPROM `/CE` (pin 20) | LÅG när A15=1 → EEPROM aktivt vid $8000–$FFFF |
    | 14 | `VCC` | +5V | Strömmatning |
    | 7 | `GND` | GND | Systemjord |

## Minneskarta

**EEPROM**:et tar över `$8000–$FFFF` från **Arduino**. Programmet ligger nu i äkta **ROM**.

<div class="memmap">

      <div style="height:200px;display:flex;align-items:stretch;border-bottom:2px solid #d1d5db;border-bottom:2px solid #a855f7">
        <div style="min-height:8px;width:5rem;padding-right:.75rem;display:flex;flex-direction:column;justify-content:space-between;text-align:right">
          <span style="color:#6b7280">$FFFF</span>
          <span style="color:#6b7280">$8000</span>
        </div>
        <div style="flex:1 1 0%;background-color:#f3e8ff;border-left:1px solid #a78bfa;border-right:1px solid #a78bfa;padding-left:.5rem;padding-right:.5rem;display:flex;align-items:center;font-weight:700">AT28C256 EEPROM — 32 KB ROM</div>
        <div style="width:3.5rem;text-align:right;color:#6b7280;padding-right:.5rem">32 KB</div>
      </div>
      <div style="height:100px;display:flex;align-items:stretch;border-bottom:1px solid #e5e7eb">
        <div style="width:5rem;text-align:right;padding-right:.75rem;color:#9ca3af;align-self:flex-start;padding-top:.25rem">$7FFF</div>
        <div style="flex:1 1 0%;background-color:#f3f4f6;padding-left:.5rem;padding-right:.5rem;display:flex;align-items:center;color:#9ca3af">oanvänt</div>
        <div style="width:3.5rem;text-align:right;color:#9ca3af;padding-right:.5rem;align-self:flex-start;padding-top:.25rem">~16 KB</div>
      </div>
      <div style="min-height:8px;display:flex;align-items:stretch;border-bottom:2px solid #d1d5db;border-bottom:2px solid #eab308">
        <div style="min-height:8px;width:5rem;padding-right:.75rem;display:flex;flex-direction:column;justify-content:space-between;text-align:right">
          <span style="color:#6b7280">$4010</span>
          <span style="color:#6b7280">$4000</span>
        </div>
        <div style="min-height:8px;flex:1 1 0%;background-color:#fef9c3;border-left:1px solid #facc15;border-right:1px solid #facc15;padding-left:.5rem;padding-right:.5rem;display:flex;align-items:center;font-weight:700">W65C22 VIA — fysisk I/O</div>
        <div style="width:3.5rem;text-align:right;color:#6b7280;padding-right:.5rem">16 B</div>
      </div>
      <div style="height:100px;display:flex;align-items:stretch;border-bottom:2px solid #d1d5db;border-bottom:2px solid #22c55e">
        <div style="min-height:8px;width:5rem;padding-right:.75rem;display:flex;flex-direction:column;justify-content:space-between;text-align:right">
          <span style="color:#6b7280">$3FFF</span>
          <span style="color:#6b7280">$0000</span>
        </div>
        <div style="flex:1 1 0%;background-color:#dcfce7;border-left:1px solid #4ade80;border-right:1px solid #4ade80;padding-left:.5rem;padding-right:.5rem;display:flex;align-items:center;font-weight:700">62256 SRAM — 16 KB RAM</div>
        <div style="width:3.5rem;text-align:right;color:#6b7280;padding-right:.5rem">16 KB</div>
      </div>
    
</div>

## Arduino-kod — programmeraren

Det här programmet laddas upp på den andra Arduino Mega — den som tillfälligt kopplas in som EEPROM-programmerare. Koden är enkel: ta emot 32 768 bytes över serieporten, bränn dem på AT28C256, och verifiera. Programmet körs en gång i `setup()` och rapporterar resultatet — `loop()` är tom.

### Hur EEPROM-bränning går till

**AT28C256** har inbyggd själv-timing. För att bränna en byte sätter jag adress och data, drar `/WE` låg, väntar minst 10 millisekunder (jag använder 10 för marginal), och drar `/WE` hög igen. Kretsen sköter resten internt. För att läsa tillbaka drar jag `/OE` låg och läser `PINA` — precis som med SRAM.

Verifieringen läser tillbaka varje byte och jämför med originaldatan. Om något inte stämmer rapporteras adressen och de två värdena. Annars: "OK — 32768 bytes verifierade".

??? note "📦 EEPROM-programmeraren"

    ```cpp
    --8<-- "Mega_2560_6502/EEPROM_programmer/EEPROM_programmer.ino"
    ```

## Python-skript — skicka .bin-fil till programmeraren

Ett enkelt Python 3-skript som läser `program.bin` och skickar det sida för sida över serieporten. Kräver `pyserial` (`pip install pyserial`).

??? note "📦 Python-skript"

    ```python
    --8<-- "Mega_2560_6502/scripts/upload_eeprom.py"
    ```

## Arduino-kod — datorn

Koden på datorns Arduino förenklas dramatiskt. `program[2048]` och de hundratals `write_mem()`-anropen försvinner. Istället får jag en ny funktion `is_eeprom()` som returnerar `true` för adresser mellan `$8000` och `$FFFF`. När CPU:n läser från dessa adresser tri-statar Arduino bussen — EEPROM:et svarar själv.

Arduinon är nu reducerad till *klockgenerator, reset-kontroll och seriell diagnostik*. Alla minnesarrayer utom `vectors[6]` är borta. Vektorn på `$FFFA–$FFFF` ligger sist i EEPROM-bilden — `.segment "VECTORS"` i assembler-koden placerar dem där.

Koden nedan är baserad på steg 9 men med `is_eeprom()` istället för `program[]`. `read_mem()` returnerar 0 för EEPROM-adresser — Arduino rör dem inte.

??? note "📦 Datorns Arduino — step10.inc · 124 rader"
    ```cpp
    --8<-- "Mega_2560_6502/src/step10.inc"
    ```

## Exempel på körning

### Fas 1 — bränna EEPROM

Bygga programmet med **ca65** som vanligt, köra Python-skriptet för att bränna:

```text title="Terminal"
$ pio run -e step10 -t upload    # Ladda upp dator-Arduinon
$ python3 scripts/upload_eeprom.py asm/program_hello.bin /dev/ttyACM1

AT28C256 EEPROM-programmerare
Redo att ta emot .bin-fil...
Sida 1/8: Bränner sida 1 (adress $0000)... OK
Sida 2/8: Bränner sida 2 (adress $0100)... OK
...
Sida 8/8: Bränner sida 8 (adress $0700)... OK
Alla sidor mottagna.
Verifierar...
KLAR
Totalt brända bytes: 2054
```

### Fas 2 — flytta EEPROM till datorn

Koppla bort programmerings-Arduinon. Flytta **AT28C256**-chippet till datorns kopplingsdäck och anslut enligt kopplingstabellen ovan. Slå på strömmen.

=== "Terminal"

    ```text
    Steg 10 — EEPROM som ROM
    Programmet ligger i AT28C256 — inte i Arduino.
    CPU startad. EEPROM levererar programkoden.

    R $FFFC  ← RESET-VEKTOR LÅG (EEPROM)
    R $FFFD  ← RESET-VEKTOR HÖG (EEPROM)
    R $8000  ← EEPROM
    R $8001  ← EEPROM
    W $4002  ← VIA: FF
    W $4003  ← VIA: FF
    W $4000  ← VIA: 30  (LCD-init)
    ...
    W $4000  ← VIA: 3D  (=)
    ...
    ```

=== "LCD 16×2"

    ```text
    === 6502 VIA LCD ===
    Hello from W65C02!
    ```

Varje gång jag ser `← EEPROM` i loggen är det AT28C256 som svarar — inte Arduino. Reset-vektorn på `$FFFC`/`$FFFD` ligger i EEPROM:ets sista bytes, inskrivna av assembler-kedjan. CPU:n läser dem, hoppar till `$8000`, och kör programmet direkt från äkta ROM.

Kopplar jag bort Arduinon helt (ersätter klockan med kristalloscillator) så har jag en helt fristående 6502-dator. Programmet överlever strömavbrott — slå på strömmen imorgon och det finns kvar, inbränt i kisel. Jag stängde av, satte på, stängde av, satte på — bara för att se den starta varje gång.

## Så här felsöker man

Här är några saker jag kontrollerar:

- Läser CPU:n `$FFFC`/`$FFFD` men hoppar till fel adress? Då är EEPROM:ets `/CE` förmodligen inte rätt avkodat. Jag kontrollerar att 74HC00-grinden får `A15` på båda ingångarna och att utgången går till EEPROM pin 20.
- Körs programmet inte alls? Då kontrollerar jag att `/OE` är kopplat till `GND` och `/WE` till +`5V`. Utan `/OE` låg kör EEPROM:et inte ut data.
- Misslyckas bränningen? Då mäter jag spänningen vid EEPROM:ets `VDD` — den måste vara minst 4.8V. Jag använder 12V DC-adapter till programmerings-Arduinon.
- Busskrockar? Då är 100Ω motstånd på databussen nu ännu viktigare — fyra enheter delar på samma 8 ledningar.
- Jag glömmer inte avkopplingskondensatorn vid EEPROM:ets VDD/GND.

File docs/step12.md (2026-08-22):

# Fristående klocka

Det sista som påminner om Arduinon är klockan. Nu byter jag ut den mot en riktig kristall — när datorn sedan startar med strömmen behöver den ingen hjälp alls.

## Mål

Sedan steg 10 levererar EEPROM:et programmet och SRAM:et minnet — men Arduino har fortfarande skött *klockan*. Nu kopplar jag in en riktig klockgenerator: en 16 MHz-oscillator vars frekvens jag delar ner med en **74HC393** till 1 MHz. En enkel RC-krets sköter reset.

När det här steget är klart kan jag koppla bort Arduinon helt. Slå på strömmen och datorn startar på egen hand — programmet ur EEPROM:en, minnet i SRAM:en, texten på LCD:n. En riktig, fristående 6502-dator.

Hastigheten förändrar en sak: vid 1 MHz tar varje instruktion bara några mikrosekunder, och LCD:n hinner inte med om programmet inte själv väntar. Därför lär jag mig också *tidshantering* — delay-subrutiner som ger displayen de pauser den kräver.

1 MHz är samma fart som original-Apple II:n — snabbt nog att kännas som en riktig dator, långsamt nog att följa med i vad som händer.

## Nya komponenter

| Antal | Komponent | Används till |
|---|---|---|
| 1 | 16 MHz-oscillator (DIL-14, 5V) | Klockans källa — ren 16 MHz fyrkantsvåg direkt på utgången |
| 1 | 74HC393 (dubbel 4-bitars ripple-räknare, DIP-14) | Delar 16 MHz → 1 MHz (÷16) för `PHI2` |
| 1 | Tryckknapp | Manuell reset |
| 1 | 10 µF elektrolytisk kondensator | Reset-RC — håller `/RESET` låg en stund vid start |
| 1 | 10 kΩ motstånd | Pull-up till `/RESET` |
| 1 | 100 nF keramisk kondensator | Avkoppling vid 74HC393:ns VCC/GND |

## Kopplingsschema

Schemat visar klockkedjan: oscillatorn längst till vänster, 74HC393:an i mitten som delare, och `PHI2` ut till CPU:n. Resten av datorn (SRAM, VIA, EEPROM) är oförändrad från steg 11.

Schema kommer snart — se klockkedjan och kopplingstabellerna nedan så länge.

## Klockkedjan — från 16 MHz till 1 MHz

En oscillator är en komplett klockkrets i en kapsel: kristallen och förstärkaren sitter inbyggda, och utgången ger en ren fyrkantsvåg direkt — inget att bygga runt. 16 MHz är för snabbt för W65C02S (max 14 MHz), så jag delar ner frekvensen med en 74HC393.

74HC393:an innehåller *två* oberoende 4-bitars räknare. Varje steg halverar frekvensen, och alla utgångar har 50% arbetscykel — perfekt för `PHI2`:

| Utgång | Delning | Frekvens | Användning |
|---|---|---|---|
| 1Q0 (pin 3) | ÷2 | 8 MHz | Snabbast som är säker — men LCD-timing kräver många delay-loopar |
| 1Q1 (pin 4) | ÷4 | 4 MHz | Mellanfart |
| 1Q2 (pin 5) | ÷8 | 2 MHz | Mellanfart |
| 1Q3 (pin 6) | ÷16 | 1 MHz | Jag använder denna — klassisk 6502-fart, snäll mot LCD:n |

## 74HC393 — pinout

DIP-14-kapsel. Två oberoende 4-bitars ripple-räknare (1 och 2). `1Q3` är den utgång jag använder — 16 MHz ÷16 = 1 MHz till `PHI2`.
74HC393 pinout

## Kopplingar

Tre små kretsar att koppla: oscillatorn, delaren och reset-kretsen. Allt annat — ström, bussar, SRAM, VIA, EEPROM — är oförändrat från steg 11.

### Oscillator (DIL-14, 5V, 16 MHz)

Här är kopplingarna för 16 MHz-oscillatorn. Den har inbyggd kristall och förstärkare, och utgången ger en ren fyrkantsvåg direkt.

??? note "📦 Kopplingar — 16 MHz-oscillator"

    | Pin | Signal | Kopplas till | Varför |
    |---|---|---|---|
    | 14 | `VCC` | +5V | Strömmatning — glöm inte 100 nF avkoppling |
    | 7 | `GND` | GND | Systemjord |
    | 8 | `OUT` | 74HC393 pin 1 (`1CLK`) | 16 MHz fyrkantsvåg till räknaren |
    | 1 | `ENA` | — (lämnas oansluten) | Enable — de flesta moduler kör alltid |

### 74HC393 — frekvensdelare

Här är kopplingarna för 74HC393:an som delar ner 16 MHz → 1 MHz. Jag använder bara den ena räknaren (1) och utgången `1Q3` (pin 6) till CPU:n.

??? note "📦 Kopplingar — 74HC393"

    | Pin | Signal | Kopplas till | Varför |
    |---|---|---|---|
    | 1 | `1CLK` | Oscillatorns ut (pin 8) | 16 MHz in — räknaren tickar på varje fallande flank |
    | 2 | `1MR` | GND | Master reset — LÅG = räknaren räknar |
    | 6 | `1Q3` | CPU `PHI2` (pin 37) | 16 MHz ÷16 = 1 MHz — datorns nya hjärtslag |
    | 14 | `VCC` | +5V | Strömmatning — 100 nF avkoppling till GND |
    | 7 | `GND` | GND | Systemjord |

### Reset-RC — start utan Arduino

Här är den enkla RC-kretsen som håller `/RESET` låg en stund vid start. När strömmen slås på laddas kondensatorn långsamt upp via motståndet, och `/RESET` hålls LÅG tills kondensatorn är fulladdad. Sedan stiger spänningen till +5V och datorn börjar köra.

??? note "📦 Kopplingar — reset-RC"

    | Komponent | Kopplas till | Varför |
    |---|---|---|
    | 10 kΩ | +5V → CPU `/RESET` (pin 40) | Pull-up — håller `/RESET` HÖG i drift |
    | 10 µF | CPU `/RESET` → GND | Laddas långsamt vid start → `/RESET` hålls LÅG några ms, sedan HÖG |
    | Knapp | CPU `/RESET` → GND | Manuell reset — tryck så startar datorn om |

## Programmet — nu med tidshantering

Programmet är samma LCD-hello som tidigare, men med en viktig skillnad: vid 1 MHz tar en instruktion bara ~2–3 µs, och HD44780-displayen kräver pauser mellan kommandon (klartext-rensning tar t.ex. 1,64 ms). Förut, vid 500 Hz, hanns allt med av sig själv — nu måste 6502-programmet *självt* vänta.

Lösningen är en `delay_ms`-subrutin med nästlade loopar. Varje varv i den inre loopen tar ~4 cykler ≈ 4 µs; 250 varv ≈ 1 ms. `lcd_cmd` väntar ~2 ms efter varje kommando, `lcd_data` ~1 ms efter varje tecken. Displayen får alltid den paus den behöver.

??? note "📦 Programmet"

    ```asm
    --8<-- "Mega_2560_6502/asm/standalone/program_standalone.asm"
    ```

Programmet byggs med ca65 + ld65 och bränns om i EEPROM:en med steg 10-programmeraren:

``` title="Terminal"
cd Mega_2560_6502
ca65 -o asm/standalone/program_standalone.o asm/standalone/program_standalone.asm
ld65 -C asm/standalone/program_standalone.cfg -o asm/standalone/program_standalone.bin asm/standalone/program_standalone.o
python3 scripts/upload_eeprom.py asm/standalone/program_standalone.bin /dev/ttyACM1
```

Binären är 16 KB och ligger på EEPROM-adress 0 (= CPU `$C000`) med vektorer på `$3FFA` (= `$FFFA`) — samma minneskarta som steg 11. Länkskriptet `program_standalone.cfg` finns i `asm/standalone/`.

## Ingen Arduino-kod

Det här steget har ingen Arduino-kod — Arduino finns inte med på kopplingsdäcket längre. Allt som återstår av den gamla startmotorn är minnet av hur den hjälpte mig: klockan sköter kristallen nu, reset sköter RC-kretsen, och programmet ligger i EEPROM:en.
## Exempel på körning

Slå på strömmen. Inget att ladda upp, inget att ansluta — datorn bara startar. Efter en kort stund (LCD-initieringen) visas:

```text title="LCD 16×2"
6502 FRISTAENDE
1 MHz KRISTALL
```

- Texten skrivs om i en loop: visa en stund, rensa, börja om.
- Stäng av strömmen och slå på igen — datorn startar direkt ur EEPROM:en.
- Tryck på reset-knappen — datorn startar om utan att strömmen bryts.
- Koppla bort Arduino helt om den fortfarande sitter i — den behövs inte.

Ingen seriemonitor längre: LCD:n är datorns enda ansikte utåt. Jag vred på strömmen och datorn bara vaknade — precis som jag tänkt mig.

### Så här provar jag

- Jag kopplar en lysdiod (med 220 Ω) från `PHI2` (pin 37) till `GND` — den lyser svagt, eftersom den är på halva tiden (50% arbetscykel vid 1 MHz).
- Jag mäter `1Q0`–`1Q3` med multimetern — medelspänningen halveras för varje delningssteg (≈2,5 V, ≈1,25 V, ≈0,6 V, ≈0,3 V).
- Jag flyttar klockan från `1Q3` till `1Q0` (8 MHz) — jag ser vad som händer med LCD:n: programmets delay-loopar är räknade för 1 MHz, så displayen hinner inte med.
- Jag mäter `/RESET` (pin 40) med multimetern strax efter start — den ska ligga nära 0 V direkt, sedan stiga mot 5 V.

## Så här felsöker man

Här är några saker jag kontrollerar:

- Ingen klocka? Då mäter jag oscillatorns ut (pin 8) — en multimeter visar ~2,5 V medel om 16 MHz-pulsen finns. Jag kontrollerar VCC (pin 14) och GND (pin 7).
- Startar CPU:n inte? Då mäter jag `PHI2` (pin 37) — ska vara 1 MHz, och `/RESET` (pin 40) — ska vara HÖG efter start. Jag kontrollerar reset-RC: 10 kΩ till +5V, 10 µF till GND.
- Är LCD:n blank? Då måste programmet i EEPROM:en vara rätt version — med delay-loopar. Jag bränner om med `program_standalone.bin` (inte hello-programmet från steg 10).
- Skakig eller felaktig text? Då kontrollerar jag avkopplingen (100 nF) vid 74HC393:ns VCC/GND och att `1MR` (pin 2) är GND.
- Busskrockar? Samma som tidigare: exakt en enhet ska vara aktiv per klockcykel — jag mäter chip-selects medan jag stegar.

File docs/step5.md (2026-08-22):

# LCD-display

Datorn fungerar — men den pratar bara med en laptop. Det här är steget där bygget börjar kännas som en riktig maskin: tecken visas på en egen skärm.

## Mål

Datorn fungerar — men all feedback går via seriemonitorn på en laptopen. Nu kopplar jag in en LCD-display (16×2 tecken) som visar vad CPU:n gör direkt på kopplingsdäcket. Ingen datorskärm behövs egentligen längre.

LCD:n kopplas i *4-bitars parallellt läge* till Arduino. Det innebär att jag skickar data 4 bitar i taget via pinnar `D7–D10`. Arduino-biblioteket `LiquidCrystal` sköter all kommunikation — jag behöver bara tala om vilka pinnar som används.

Viktig detalj: datapinnarna är i omvänd ordning. Arduino `D10` går till LCD `DB4`, `D9` till `DB5`, `D8` till `DB6`, `D7` till `DB7`. Koden måste spegla detta:

```text title="Terminal"
LiquidCrystal lcd(
  5,  // RS
  6,  // E
  10, // DB4
  9,  // DB5
  8,  // DB6
  7   // DB7
);
```
## Nya komponenter

En 16×2 LCD-display, en 10 kΩ-potentiometer för kontrast och ett 220Ω-motstånd för bakgrundsbelysningen. 

| Antal | Komponent |
|---|---|
| 1 | 16×2 (parallell, t.ex. QC1602A) |
| 1 | 10 kΩ potentiometer (kontrast) |
| 1 | 220 Ω motstånd (bakgrundsbelysning) |

## Kopplingsschema

Schemat visar LCD-displayen ansluten i 4-bitarsläge: `RS` till `D5`, E till `D6`, och datapinnarna `DB4–DB7` till `D10`, `D9`, `D8`, `D7` i omvänd ordning. 

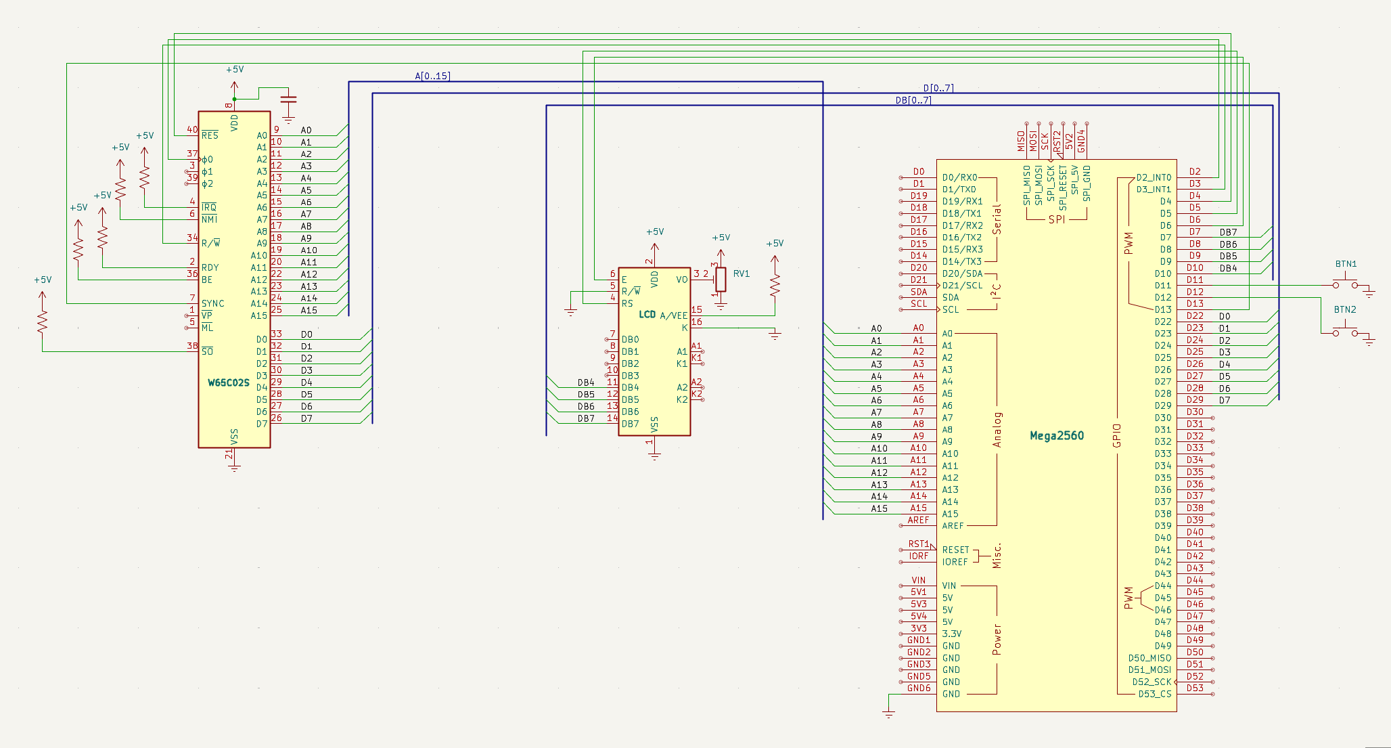
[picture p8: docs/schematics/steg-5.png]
Steg 5 — LCD-display


## LCD 16×2 — pinout

16-pin SIL (single in-line). Pin 1 är närmast kanten på de flesta moduler. Justera kontrasten med potentiometern på `VO` (pin 3).
LCD 16×2 pinout

## Kopplingar

Här är varenda koppling i steg 5, pinne för pinne.

??? note "📦 Kopplingar — CPU, klocka, ström, adressbuss, reset, databuss och LCD"

    | Pin | Signal | Kopplas till | Varför |
    |---|---|---|---|
    | 8 | `VDD` | +5V | Strömmatning — CPU:ns driftspänning |
    | 21 | `VSS` | GND | Systemjord — sluten krets |
    | 37 | `PHI2` | Arduino D2 | Klockingång — Arduino skickar fyrkantsvåg |
    | 2 | `RDY` | +5V via 10kΩ | Ready — HÖG = CPU får köra. Utan denna stannar CPU:n |
    | 4 | `/IRQ` | +5V via 10kΩ | Interrupt request — HÖG = inget avbrott |
    | 6 | `/NMI` | +5V via 10kΩ | Non-maskable interrupt — måste vara HÖG |
    | 36 | `BE` | +5V via 10kΩ | Bus Enable — HÖG = bussarna aktiva. Utan denna är CPU:n bortkopplad! |
    | 38 | `/SO` | +5V via 10kΩ | Set Overflow — avaktiverad |
    | 40 | `/RESET` | Arduino D4 | Kontrollerad reset — Arduino håller CPU:n i reset tills jag är redo |
    | 9–16 | `A0–A7` | Arduino A0–A7 | Låga adressbyte — läses via PORTF |
    | 17–20, 22–25 | `A8–A15` | Arduino A8–A15 | Höga adressbyte — läses via PORTK |
    | 34 | `R/W` | Arduino D3 | HÖG = CPU läser, LÅG = CPU skriver. Arduino måste veta detta |
    | 33 | `D0` | Arduino D22 via 100Ω | Databit 0 (LSB) |
    | 32 | `D1` | Arduino D23 via 100Ω | Databit 1 |
    | 31 | `D2` | Arduino D24 via 100Ω | Databit 2 |
    | 30 | `D3` | Arduino D25 via 100Ω | Databit 3 |
    | 29 | `D4` | Arduino D26 via 100Ω | Databit 4 |
    | 28 | `D5` | Arduino D27 via 100Ω | Databit 5 |
    | 27 | `D6` | Arduino D28 via 100Ω | Databit 6 |
    | 26 | `D7` | Arduino D29 via 100Ω | Databit 7 (MSB) |
    | 7 | `SYNC` | Arduino D13 | HÖG = CPU:n hämtar första byten av ny instruktion |
    | LCD 16×2 (parallell 4-bit) |  |  |  |
    | 1 | `VSS` | GND | Jord |
    | 2 | `VDD` | +5V | Strömmatning |
    | 3 | `VO` | Potentiometer mittben | Kontrast — sidoben till +5V och GND |
    | 4 | `RS` | Arduino D5 | Register Select — 0 = kommando, 1 = data |
    | 5 | `R/W` | GND | Alltid skrivläge — jag läser aldrig från LCD:n |
    | 6 | `E` | Arduino D6 | Enable — Arduino pulserar för att skicka data |
    | 11 | `DB4` | Arduino D10 | Data bit 4 — omvänd ordning! |
    | 12 | `DB5` | Arduino D9 | Data bit 5 |
    | 13 | `DB6` | Arduino D8 | Data bit 6 |
    | 14 | `DB7` | Arduino D7 | Data bit 7 |
    | 15 | `A` | +5V via 220Ω | Bakgrundsbelysning + |
    | 16 | `K` | GND | Bakgrundsbelysning − |

## Arduino-kod

Hittills har all feedback från datorn gått via seriemonitor på en laptop. Det fungerar, men det känns inte som en riktig dator. Nu kopplar jag in en LCD-display direkt på kopplingsdäcket — och vips är datorn fristående. Ingen PC krävs för att se vad CPU:n gör.

### LCD i 4-bitarsläge — att prata med displayen

LCD-displayer med **HD44780**-kontroller (standard för 16×2 och 20×4) kan köras i två lägen: 8-bitars (alla 8 datapinnar används) eller 4-bitars (endast `DB4–DB7`). Jag använder 4-bitarsläget för att spara pinnar på Arduino. Arduino-biblioteket `LiquidCrystal` hanterar all kommunikation — jag behöver bara tala om vilka pinnar som används, och som jag såg i Mål-avsnittet speglar konstruktorn den omvända pin-ordningen.

### LCD-uppdatering inuti `pulse()`

Den stora kodändringen sitter i `pulse()`. Efter varje klockcykel uppdateras LCD:n:

- Rad 0: visar aktuell adress i formatet `A:$8000`. Padding med mellanslag håller displayen ren när adressen växlar mellan olika längder.
- Rad 1: visar data på databussen i formatet `D:$EA`. Enstaka hex-siffror paddas med en nolla för jämn bredd.

`setup()` initierar LCD:n med `lcd.begin(16, 2)` och skriver en välkomsttext. `loop()` är oförändrad från steg 4 — knapparna fungerar precis som tidigare, men nu ser jag resultatet både i seriemonitor och på displayen.

### Vad som är nytt jämfört med steg 4

I koden: `#include <LiquidCrystal.h>`, LCD-objektet, och `lcd.print()`-anropen i `pulse()`. Det är allt — resten är samma beprövade minnesemulator som tidigare.

??? note "📦 Arduino-kod"

    ```cpp
    --8<-- "Mega_2560_6502/src/step1.inc"
    ```

## Exempel på körning

Direkt efter uppladdning visar både seriemonitor och LCD-displayen att allt är redo:

=== "Terminal"

    ```text
    Steg 5 — LCD-display
    ```

=== "LCD 16×2"

    ```text
    W65C02S Steg 5

    ```
När jag trycker på Knapp 1 (klocksteg) uppdateras båda vyerna samtidigt. Seriemonitor loggar varje minnesaccess, LCD:n visar adress och data i realtid:

=== "Terminal"

    ```text
    Steg 5 — LCD-display
    R $FFFC
    R $FFFD
    R $8000
    R $8001
    ```

=== "LCD 16×2"

    ```text
    A:$8001
    D:$EA
    ```
    
Samma information på båda ställena — adress (`$8001`) och data (`$EA`, `NOP`). Skillnaden är att LCD:n visar *just nu* medan seriemonitor bygger en historik. Med Knapp 2 (instruktionssteg) ser jag flera rader i seriemonitor per tryck medan LCD:n uppdateras för varje klockcykel — ett snabbt flimmer av adresser tills `SYNC` går hög.

Datorn har blivit fristående. Jag kan koppla bort USB-kabeln (om Arduino drivs via DC-adaptern) och fortfarande stega genom programmet och se allt på LCD:n. Seriemonitor är praktisk för att logga och felsöka, men displayen på kopplingsdäcket gör datorn till en egen, komplett enhet. 

## Så här felsöker man

Här är några saker jag kontrollerar:

- Helt tom skärm? Då justerar jag kontrasten med potentiometern och testar båda ytterlägena.
- Svarta rutor på första raden? Då är LCD:n i 8-bitarsläge men får ingen data. Jag kontrollerar att `lcd.begin(16,2)` körs.
- Förvrängda tecken? Då är datapinnarna i fel ordning. Jag provar `LiquidCrystal lcd(5, 6, 7, 8, 9, 10)` om min display har rak ordning.
- Ingen bakgrundsbelysning? Då kontrollerar jag 220Ω till A (pin 15) och `GND` till K (pin 16).

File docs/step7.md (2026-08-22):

# VIA + LCD, styrd av 6502

Det här är det stora steget: från att Arduino sköter allt till att processorn själv styr LCD-displayen.

## Mål

I steg 6 styrde Arduino LCD-displayen direkt. Nu tar jag nästa stora kliv: jag kopplar in en **W65C22** VIA (Versatile Interface Adapter) — en I/O-krets som ger 6502-processorn 20 egna pinnar att styra. VIAn sitter på CPU:ns adress- och databuss, precis som ett RAM-minne, men istället för att lagra data styr den fysiska pinnar.

En **74HC00** (två NAND-grindar) avkodar adressbussen så att VIA:n hamnar på adress `$4000–$400F`. U4A inverterar `A15`, U4B NAND:ar med `A14` — resultat: VIA aktiveras när `A14`=1 och `A15`=0.

6502-programmet på `$8000` gör följande:

1. Sätter VIA:ns portar som utgångar
1. Initierar LCD:n i 8-bitarsläge (8-bitars databuss, 2 rader, 5×8 font, display on, entry mode)
1. Skriver två rader text genom att lägga ASCII-värden på port B och pulsa enable-signalen på port A — sedan *clear display* och loopa om från början

När allt fungerar har jag en dator där CPU:n själv styr I/O via minnesmappade adresser. Arduino är nu bara minnesemulator och klocka — all logik för LCD:n körs på 6502.

## Nya komponenter

De här kretsarna är starten på en riktig datorarkitektur. En **W65C22** VIA ger CPU:n 20 egna I/O-pinnar, en **74HC00** avkodar adressbussen så att VIA:n hamnar på `$4000`, och en 100 nF-kondensator håller VIA:ns strömmatning ren.

| Antal | Komponent | Not |
|---|---|---|
| 1 | W65C22 VIA (DIP-40) | 2×8-bit I/O-portar (PA0–PA7, PB0–PB7), 4 registerväljare |
| 1 | 74HC00 (quad 2-input NAND) | Adressavkodning — genererar chip select-signaler |
| 1 | LCD 16×2 (parallell, t.ex. QC1602A) | Ansluts till VIA:ns PB0–PB7 + kontrollpinnar |
| 1 | 100 nF keramisk kondensator | Avkoppling vid VIA:ns VCC/GND |

## Vad är nytt i det här steget?

- VIAn — en **W65C22** som ger processorn 20 egna I/O-pinnar, på samma buss som minnet.
- Minnesmappad I/O — att skriva till en adress (`$4000`) är samma sak som att styra pinnar.
- Adressavkodning — **74HC00**:ns grindar väljer ut VIAn:s fönster (`$4000`–`$7FFF`).
- LCD direkt från 6502 — processorn styr displayen själv; Arduino är bara minne + klocka.
- Ett mycket längre program — LCD-initieringen kräver en hel kommandosekvens, så programmet är tiotals gånger större än i steg 6.

## Så här fungerar en VIA

En VIA är som ett litet arkiv av brevlådor för elektriska signaler. Processorn skriver och läser på 16 registeradresser (`$4000`–`$400F`), och kretsen översätter varje värde till verkliga spänningar på sina pinnar. Tre saker räcker för att förstå allt jag gör här:

- Register = brevlådor. `$4000` (PORTB) och `$4001` (PORTA) är portarna — det värde processorn skriver dit läggs ut på pinnarna. `$4002`/`$4003` (DDRB/DDRA) bestämmer riktningen: 1 = utgång, 0 = ingång. Jag sätter `$FF` = alla 8 pinnar som utgångar.
- Minnesmappad I/O. VIAn har inga egna adressbegrepp — den tittar bara på sina chip-select-pinnar (`CS1` = HÖG, `/CS2` = LÅG). När 74HC00:an gör `/CS2` låg vid `$4000`–`$7FFF` svarar VIAn på alla adresser i fönstret, som om den vore 16 bytes minne (registren speglas).
- Skriv = styr, läs = avläs. När processorn skriver till PORTB läggs värdet ut på LCD:ns datapinnar. När den läser PORTB avläses pinnarnas spänningar.

LCD:ns *fallande flank* är den sista pusselbiten: displayen läser databussen i ögonblicket då `E` (PA2) går från HÖG till LÅG. Därför skriver varje tecken- eller kommandosekvens alltid i tre steg: data till PORTB → `E`=1 → `E`=0.

## Kopplingsschema

Schemat visar hur fyra kretsar nu delar på adress- och databussen: CPU, Arduino, VIA och **74HC00**. VIAn får sin klocka, `R/W` och reset från CPU:n, medan **74HC00**:ns utsignal till `/CS2` avgör när VIAn får prata. LCD:n har flyttat från Arduino till VIA:ns portar.

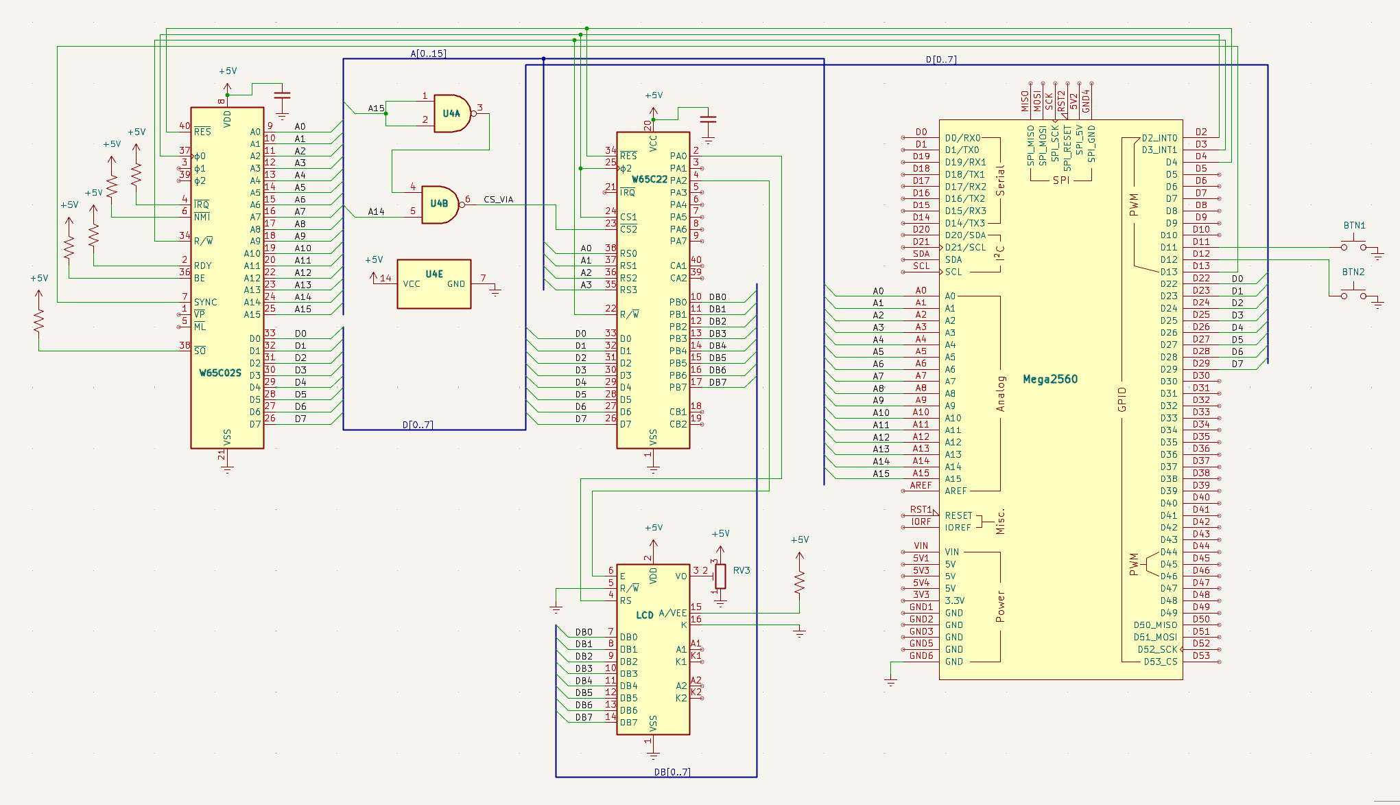
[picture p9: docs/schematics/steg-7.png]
Steg 7 — VIA + LCD


## W65C22 VIA — pinout

DIP-40-kapsel. Två 8-bitars I/O-portar (PA, PB), 4 kontrollpinnar (`CA1–CB2`), bussanslutning. Samma kapsel som CPU:n — var noga med orienteringen.
W65C22 VIA pinout

## 74HC00 — pinout

DIP-14-kapsel. Fyra 2-ingångars NAND-grindar. U4A+U4B används för VIA-avkodning, U4C+U4D är lediga (används för SRAM i steg 9).
74HC00 pinout

## Kopplingar — krets för krets

Kopplingarna är organiserade krets för krets, eftersom adress- och databussen nu delas av fyra enheter. För varje krets finns en egen tabell: vad varje pinne heter, vart den går, och varför. Börja med CPU:n, följ sedan VIA:n och 74HC00:ns avkodning, och avsluta med LCD:n.

### W65C02S CPU

Här är alla kopplingar för CPU:n. Den får klocka, `R/W` och reset från Arduino, och delar adress- och databussen med VIA:n och 74HC00:an. Avkopplingskondensatorn är markerad längst ner.

??? note "📦 Kopplingar — CPU, klocka, ström, adressbuss, reset och databuss"

    | Pin | Signal | Kopplas till | Varför |
    |---|---|---|---|
    | 8 | `VDD` | +5V | Strömmatning |
    | 21 | `VSS` | GND | Systemjord |
    | 37 | `PHI2` | Arduino D2 | Klocka — Arduino genererar 500 Hz fyrkantsvåg |
    | 34 | `R/W` | Arduino D3 + VIA pin 22 | Talar om för alla kretsar om CPU:n läser eller skriver |
    | 40 | `/RESET` | Arduino D4 + VIA pin 34 | Kontrollerad reset — båda kretsarna startar samtidigt |
    | 9–16, 17–20, 22–25 | `A0–A15` | Arduino A0–A15 + VIA + 74HC00 | Adressbuss — alla kretsar delar samma 16 linjer |
    | 26–33 | `D0–D7` | Arduino D22–D29 + VIA D0–D7 | Databuss — 100Ω seriemotstånd på varje ledning |
    | 2 | `RDY` | +5V via 10kΩ | Ready — HÖG = CPU kör, LÅG = paus |
    | 4 | `/IRQ` | +5V via 10kΩ | Interrupt — avaktiverad (HÖG = inget avbrott) |
    | 6 | `/NMI` | +5V via 10kΩ | Non-maskable interrupt — avaktiverad |
    | 36 | `BE` | +5V via 10kΩ | Bus Enable — HÖG = bussarna aktiva. Utan denna är CPU:n bortkopplad! |
    | 38 | `/SO` | +5V via 10kΩ | Set Overflow — avaktiverad |

### W65C22 VIA

Här är alla kopplingar för VIAn. Den får klocka, `R/W` och reset från CPU:n, och styr LCD:n via port A/B. Avkopplingskondensatorn är markerad längst ner.

??? note "📦 Kopplingar — W65C22 VIA"

    | Pin | Signal | Kopplas till | Varför |
    |---|---|---|---|
    | 20 | `VDD` | +5V | Strömmatning — glöm inte avkoppling 100nF till GND |
    | 1 | `VSS` | GND | Systemjord |
    | 25 | `PHI2` | CPU PHI2 (pin 37) | Samma klocka som CPU — VIAn synkroniseras med bussen |
    | 22 | `R/W` | CPU R/W (pin 34) | VIAn behöver veta om CPU:n läser eller skriver |
    | 34 | `/RESET` | CPU /RESET (pin 40) | VIAns interna register nollställs vid reset |
    | 26–33 | `D0–D7` | CPU D0–D7 | Databuss — VIAn läser/skriver data här |
    | 38–35 | `RS0–RS3` | CPU A0–A3 | Registerväljare — vilket av VIAns 16 register som adresseras |
    | 24 | `CS1` | +5V | Chip Select 1 — aktiv HÖG. Permanent aktiverad |
    | 23 | `/CS2` | 74HC00 pin 6 (utgång) | Chip Select 2 — aktiv LÅG. 74HC00 drar denna LÅG när A15=0, A14=1 |
    | 2 | `PA0` | LCD RS (pin 4) | Register Select: LÅG = kommando, HÖG = data |
    | 4 | `PA2` | LCD E (pin 6) | Enable — fallande flank får LCD:n att läsa databussen |
    | 10–17 | `PB0–PB7` | LCD DB0–DB7 | 8-bitars parallell data till LCD:n |

### 74HC00 (adressavkodning)

Här är kopplingarna för U4A + U4B i **74HC00**:an. De avgör när VIAn ska svara på CPU:ns läs- och skrivförfrågningar.

??? note "📦 Kopplingar — 74HC00 (adressavkodning för VIA)"

    | Pin | Signal | Kopplas till | Varför |
    |---|---|---|---|
    | 1, 2 | `A15` (in) | CPU `A15` | Båda ingångarna till A15 → ut = NOT A15 (inverterare) |
    | 3 | NOT `A15` (ut) | U4B pin 4 | NOT A15 → grind B ingång 1 |
    | 4 | NOT `A15` | U4A pin 3 | NOT A15 |
    | 5 | `A14` (in) | CPU `A14` | (NOT A15) NAND A14 → LÅG när A15=0, A14=1 |
    | 6 | VIA `/CS2` (ut) | VIA `/CS2` (pin 23) | LÅG vid $4000–$7FFF → VIA aktiverad |
    | 14 | `VCC` | +5V | Strömmatning |
    | 7 | `GND` | GND | Systemjord |

### LCD 16×2 (parallell)

Här är kopplingarna för LCD:n, som nu styrs av VIAn istället för Arduino. Datapinnarna `DB0–DB7` går till VIA:ns port B, och kontrollpinnarna `RS` och `E` går till port A. Jag läser aldrig från LCD:n, så `R/W` är alltid LÅG.

??? note "📦 Kopplingar — LCD 16×2"

    | Pin | Signal | Kopplas till | Varför |
    |---|---|---|---|
    | 1 | `VSS` | GND | Jord |
    | 2 | `VDD` | +5V | Strömmatning |
    | 3 | `VO` | Potentiometer (10kΩ) | Kontrast — mittbenet till VO, sidoben till +5V och GND |
    | 4 | `RS` | VIA PA0 (pin 2) | Register Select — 0 = instruktion, 1 = teckendata |
    | 5 | `R/W` | GND | Alltid skrivläge — jag läser aldrig från LCD:n |
    | 6 | `E` | VIA PA2 (pin 4) | Enable — VIAn pulserar denna för att skicka data |
    | 7–14 | `DB0–DB7` | VIA PB0–PB7 | 8-bitars data — teckenkod eller kommando |
    | 15 | `A` | +5V via 220Ω | Bakgrundsbelysning anod (+) |
    | 16 | `K` | GND | Bakgrundsbelysning katod (−) |

## Minneskarta

**6502**-processorn har 16 adresslinjer = 64 KB adressrymd. Arduinon svarar på adresser där den har data, och tri-statar vid **VIA**-adresser så den fysiska kretsen kan svara.

<div class="memmap">

      <div style="min-height:8px;display:flex;align-items:stretch;border-bottom:1px solid #e5e7eb">
        <div style="min-height:8px;width:5rem;padding-right:.75rem;display:flex;flex-direction:column;justify-content:space-between;text-align:right">
          <span style="color:#6b7280">$FFFF</span>
          <span style="color:#6b7280">$FFFA</small>
        </div>
        <div style="min-height:8px;flex:1 1 0%;background-color:#f3e8ff;border-left:1px solid #c4b5fd;border-right:1px solid #c4b5fd;padding-left:.5rem;padding-right:.5rem;display:flex;align-items:center">vectors[6] — NMI, RESET, IRQ</div>
        <div style="width:3.5rem;text-align:right;color:#6b7280;padding-right:.5rem">6 B</div>
      </div>
      <div style="height:200px;display:flex;align-items:stretch;border-bottom:1px solid #e5e7eb">
        <div style="width:5rem;text-align:right;padding-right:.75rem;color:#9ca3af;align-self:flex-start;padding-top:.25rem">$FFF9</div>
        <div style="flex:1 1 0%;background-color:#f3f4f6;padding-left:.5rem;padding-right:.5rem;display:flex;align-items:center;color:#9ca3af">oanvänt (returnerar $EA = NOP)</div>
        <div style="width:3.5rem;text-align:right;color:#9ca3af;padding-right:.5rem;align-self:flex-start;padding-top:.25rem">~30 KB</div>
      </div>
      <div style="min-height:16px;display:flex;align-items:stretch;border-bottom:1px solid #e5e7eb">
        <div style="min-height:16px;width:5rem;padding-right:.75rem;display:flex;flex-direction:column;justify-content:space-between;text-align:right">
          <span style="color:#6b7280">$8800</span>
          <span style="color:#6b7280">$8000</span>
        </div>
        <div style="flex:1 1 0%;background-color:#dbeafe;border-left:1px solid #93c5fd;border-right:1px solid #93c5fd;padding-left:.5rem;padding-right:.5rem;display:flex;align-items:center">program[2048] — 6502-program</div>
        <div style="width:3.5rem;text-align:right;color:#6b7280;padding-right:.5rem">2 KB</div>
      </div>
      <div style="height:100px;display:flex;align-items:stretch;border-bottom:1px solid #e5e7eb">
        <div style="width:5rem;text-align:right;padding-right:.75rem;color:#9ca3af;align-self:flex-start;padding-top:.25rem">$7FFF</div>
        <div style="flex:1 1 0%;background-color:#f3f4f6;padding-left:.5rem;padding-right:.5rem;display:flex;align-items:center;color:#9ca3af">oanvänt</div>
        <div style="width:3.5rem;text-align:right;color:#9ca3af;padding-right:.5rem;align-self:flex-start;padding-top:.25rem">~16 KB</div>
      </div>
      <div style="min-height:8px;display:flex;align-items:stretch;border-bottom:2px solid #d1d5db;border-bottom:2px solid #eab308">
        <div style="min-height:8px;width:5rem;padding-right:.75rem;display:flex;flex-direction:column;justify-content:space-between;text-align:right">
          <span style="color:#6b7280">$4010</span>
          <span style="color:#6b7280">$4000</span>
        </div>
        <div style="min-height:8px;flex:1 1 0%;background-color:#fef9c3;border-left:1px solid #facc15;border-right:1px solid #facc15;padding-left:.5rem;padding-right:.5rem;display:flex;align-items:center;font-weight:700">W65C22 VIA (fysisk krets)</div>
        <div style="width:3.5rem;text-align:right;color:#6b7280;padding-right:.5rem">16 B</div>
      </div>
      <div style="height:100px;display:flex;align-items:stretch;border-bottom:1px solid #e5e7eb">
        <div style="width:5rem;text-align:right;padding-right:.75rem;color:#9ca3af;align-self:flex-start;padding-top:.25rem">$3FFF</div>
        <div style="flex:1 1 0%;background-color:#f3f4f6;padding-left:.5rem;padding-right:.5rem;display:flex;align-items:center;color:#9ca3af">oanvänt</div>
        <div style="width:3.5rem;text-align:right;color:#9ca3af;padding-right:.5rem;align-self:flex-start;padding-top:.25rem">~15 KB</div>
      </div>
      <div style="min-height:8px;display:flex;align-items:stretch;border-bottom:1px solid #e5e7eb">
        <div style="min-height:8px;width:5rem;padding-right:.75rem;display:flex;flex-direction:column;justify-content:space-between;text-align:right">
          <span style="color:#6b7280">$0400</span>
          <span style="color:#6b7280">$0200</span>
        </div>
        <div style="min-height:8px;flex:1 1 0%;background-color:#dcfce7;padding-left:.5rem;padding-right:.5rem;display:flex;align-items:center">ram[1024] — ledigt RAM</div>
        <div style="width:3.5rem;text-align:right;color:#6b7280;padding-right:.5rem">512 B</div>
      </div>
      <div style="min-height:8px;display:flex;align-items:stretch;border-bottom:1px solid #e5e7eb">
        <div style="min-height:8px;width:5rem;padding-right:.75rem;display:flex;flex-direction:column;justify-content:space-between;text-align:right">
          <span style="color:#6b7280">$0200</span>
          <span style="color:#6b7280">$0100</span>
        </div>
        <div style="min-height:8px;flex:1 1 0%;padding-left:.5rem;padding-right:.5rem;display:flex;align-items:center">Stack (JSR/RTS, PHA/PLA)</div>
        <div style="width:3.5rem;text-align:right;color:#6b7280;padding-right:.5rem">256 B</div>
      </div>
      <div style="min-height:8px;display:flex;align-items:stretch">
        <div style="min-height:8px;width:5rem;padding-right:.75rem;display:flex;flex-direction:column;justify-content:space-between;text-align:right">
          <span style="color:#6b7280">$0100</span>
          <span style="color:#6b7280">$0000</span>
        </div>
        <div style="min-height:8px;flex:1 1 0%;padding-left:.5rem;padding-right:.5rem;display:flex;align-items:center">Zero page (snabbast)</div>
        <div style="width:3.5rem;text-align:right;color:#6b7280;padding-right:.5rem">256 B</div>
      </div>
    
</div>

## 6502-program — två rader via VIA

Programmet ligger på `$8000`:

1. sätter VIA-portar som utgångar,
1. initierar LCD i 8-bitarsläge,
1. skriver två rader text,
1. clear display och loopa om och loopa om. För varje byte: lägg data på PORTB, pulsa E (`PA2`) på `PORTA`.

### VIAns register (adress `$4000`–`$4003`)

| Adress | Register | Funktion |
|---|---|---|
| $4000 | ORB (PORTB) | LCD data (DB0–DB7) |
| $4001 | ORA (PORTA) | LCD kontroll (PA0=RS, PA2=E) |
| $4002 | DDRB | Data Direction B ($FF = alla utgångar) |
| $4003 | DDRA | Data Direction A |

### Att skriva ett tecken till LCD

1. Sätt data: `STA $4000` — skicka ASCII-tecknet till PORTB (LCD `DB0–DB7`)
1. Sätt `RS`=1, E=1: `LDA #$05; STA $4001` — `PA0`=`RS`=1 (data), `PA2`=E=1
1. Sätt E=0: `LDA #$01; STA $4001` — `PA2`=E=0 (fallande flank → LCD läser)

### Programmet i maskinkod

Tabellen nedan visar hur Arduino bygger 6502-programmet i minnet, byte för byte. Första delen initierar VIA-portarna och LCD-displayen (8-bitarsläge, 2 rader, 5×8 font). Därefter skrivs en textrad i taget: cursor-positionering (→ rad 1), `RS`=1 (teckenläge), och så varje ASCII-tecken med en enable-puls. Efter sista tecknet kommer clear display och ett `JMP`-hopp tillbaka till början.

??? note "6502-programmet i maskinkod"

    | Steg | Assembler | Bytes | Förklaring |
    |---|---|---|---|
    | VIA-init — sätt portar som utgångar |  |  |  |
    | 1 | LDA #$FF | A9 FF | Alla pinnar = utgång |
    | 2 | STA $4002 | 8D 02 40 | DDRB = $FF (LCD data) |
    | 3 | STA $4003 | 8D 03 40 | DDRA = $FF (RS + E) |
    | LCD-init — tvinga 8-bitarsläge ($30 × 3) |  |  |  |
    | 4–6 | LDA #$30 STA $4000 LDA #$04 · STA $4001 LDA #$00 · STA $4001 | A9 30 8D 00 40 A9 04 8D 01 40 A9 00 8D 01 40 | $30 till PORTB, pulsa E (RS=0). Upprepas 3 gånger för att garantera 8-bit |
    | Function Set: 8-bit, 2 rader, 5×8 font |  |  |  |
    | 7 | LDA #$38 STA $4000 LDA #$04 · STA $4001 LDA #$00 · STA $4001 | A9 38 8D 00 40 A9 04 8D 01 40 A9 00 8D 01 40 | $38 = 8-bit, 2 rader, 5×8 — pulsa E |
    | Display ON/OFF: display on, cursor off, blink off |  |  |  |
    | 8 | LDA #$0C STA $4000 LDA #$04 · STA $4001 LDA #$00 · STA $4001 | A9 0C 8D 00 40 A9 04 8D 01 40 A9 00 8D 01 40 | Display ON, cursor OFF |
    | Clear display + Entry mode: increment, no shift |  |  |  |
    | 9 | LDA #$01 STA $4000 LDA #$04 · STA $4001 LDA #$00 · STA $4001 | A9 01 8D 00 40 A9 04 8D 01 40 A9 00 8D 01 40 | Clear display |
    | 10 | LDA #$06 STA $4000 LDA #$04 · STA $4001 LDA #$00 · STA $4001 | A9 06 8D 00 40 A9 04 8D 01 40 A9 00 8D 01 40 | Entry mode: increment, no shift |
    | Rad 1: "=== 6502 VIA LCD ===" (cursor till $00) |  |  |  |
    | 11 | LDA #$80 · STA $4000 LDA #$04 · STA $4001 LDA #$00 · STA $4001 | A9 80 8D 00 40 … | Kommando $80 = sätt DDRAM-adress 0 (rad 1, pos 0) |
    | 12 | LDA #$01 · STA $4001 | A9 01 8D 01 40 | RS=1 (data-läge) |
    | 13 | För varje tecken: LDA #tecken · STA $4000 LDA #$05 · STA $4001 LDA #$01 · STA $4001 | A9 xx 8D 00 40 A9 05 8D 01 40 A9 01 8D 01 40 | Data + RS=1,E=1 → RS=1,E=0 (fallande flank). 19 tecken |
    | Rad 2: "W65C02" (cursor $C0) |  |  |  |
    | 14 | LDA #$C0 … | Cursor till rad 2 → "W65C02" |  |
    | Clear + loop |  |  |  |
    | 17 | LDA #$01 · STA $4000 LDA #$04 · STA $4001 LDA #$00 · STA $4001 | A9 01 8D 00 40 … | Clear display |
    | 18 | JMP hello_start | 4C xx xx | Hoppa tillbaka till rad 1 — oändlig loop |

### `is_via()` — Arduinons sätt att kliva ur vägen

Den viktigaste nya funktionen är `is_via()`. Den returnerar `true` för adresser mellan `$4000` och `$400F` — de 16 bytes som W65C22 VIA-kretsen ockuperar. När CPU:n läser eller skriver till dessa adresser måste Arduino *tri-stata* databussen (`DDRA = 0x00`) så att den fysiska VIA-kretsen kan svara. Om Arduino skulle driva bussen samtidigt som VIA:n blir det en busskollision — dyrbar rök.

Samma logik gäller i `write_mem()`: om adressen är en VIA-adress gör Arduino ingenting. VIAn tar emot skrivningen direkt från CPU:n via den delade databussen. Arduino är en passiv åskådare för just dessa 16 adresser.

### `read_mem()` och `write_mem()` — nu med full adressrymd

Minneshanteringen har vuxit. `program[2048]` täcker `$8000–$87FF` — 2 KB programkod. `ram[1024]` täcker zero page, stack och ledigt RAM (`$0000–$03FF`). `vectors[6]` täcker `$FFFA–$FFFF`. Allt annat returnerar `$EA` (`NOP`). Ordningen i `read_mem()` är viktig: VIA-adresser kontrolleras först, eftersom de inte får hanteras av Arduino över huvud taget.

### 6502-programmet byggs i `setup()`

Programmet som CPU:n ska köra byggs byte för byte med `write_mem(next++, ...)`. `next` är en pekare som automatiskt räknas upp efter varje byte — ett enkelt trick som gör koden mycket mer läsbar än hårdkodade adresser. Programmet gör följande, i tur och ordning:

1. Sätt VIA-portar som utgångar — `LDA #$FF` → `STA $4002` (DDRB) → `STA $4003` (`DDRA`). Alla 16 pinnar på port A och B blir utgångar.
1. LCD-init i 8-bitarsläge — skickar `$30` tre gånger (väcker LCD:n i 8-bitarsläge), sedan `$38` (2 rader, 5×8 font), `$0C` (display on), `$01` (clear), `$06` (entry mode). Standardsekvens för HD44780.
1. Skriv text — sätter cursor på rad 1 (`$80`), byter till data-läge (`RS`=1), och skickar en sträng tecken för tecken via PORTB. Varje tecken kräver en enable-puls: `$05` (`RS`=1, E=1) → `$01` (`RS`=1, E=0). Den fallande flanken på E får LCD:n att läsa PORTB.
1. Clear + loop — avslutar med clear display (`$01`) och `JMP` tillbaka till textutskriften. Oändlig loop.

### Arduino-koden

Koden innehåller en `phase`-variabel och fasdetektion som känner igen var i programmet CPU:n befinner sig — reset-sekvens, VIA-init, LCD-init, textutskrift, loop. Det är ovärderligt för felsökning: jag ser direkt om CPU:n fastnar i fel fas eller hoppar till en oväntad adress.

Komplett Arduino-kod för steg 7:

??? note "📦 Arduino-kod"

    ```cpp
    --8<-- "Mega_2560_6502/src/step1.inc"
    ```

## Exempel på körning

När jag laddat upp koden och öppnar seriemonitor ser jag programmet genomlöpa alla faser. Samtidigt vaknar LCD-displayen till liv — styrd helt av 6502-processorn via VIA-kretsen:

=== "Terminal"

    ```text
    ══════ RESET-SEKVENS — CPU lämnar reset ══════
    R $FFFC  ← RESET-VEKTOR LÅG
    R $FFFD  ← RESET-VEKTOR HÖG

    ══════ PROGRAMSTART $8000 — LDA #$FF ══════
    R $8000  ← OPCODE

    ══════ VIA INIT — Sätter portar som utgångar ══════
    W $4002  ← VIA: FF  (DDRB)
    W $4003  ← VIA: FF  (DDRA)

    ══════ LCD INIT — Skickar init-kommandon ══════
    W $4000  ← VIA: 30  (×3 för 8-bit)
    W $4000  ← VIA: 38  (2 rader, 5×8)
    W $4000  ← VIA: 0C  (display on)
    W $4000  ← VIA: 01  (clear)
    W $4000  ← VIA: 06  (entry mode)

    ══════ HELLO UTSKRIFT — Skriver text ══════
    W $4000  ← VIA: 3D  (=)
    ...
    ══════ KLAR — JMP loop ══════
    ```

=== "LCD 16×2"

    ```text
    === 6502 VIA LCD ===
    Hello from W65C02!
    ```
    
CPU:n har skrivit två rader text till LCD:n via VIA:ns portar. Varje tecken skickades som en `W $4000` i seriemonitor.

Varje `W $4000` eller `W $4001` är CPU:n som skriver till VIA:ns register — Arduino gör ingenting, den fysiska VIA-kretsen fångar upp skrivningen och styr LCD:n. Texten rullar fram på displayen, tecken för tecken, styrd helt av 6502-processorn.

När programmet når slutet hoppar det tillbaka till början och skriver om alltihop. Clear display, skriv text, clear display — i en oändlig loop. Datorn är nu självförsörjande: CPU:n styr I/O, Arduino levererar bara programkoden och klockan.

### Så här provar jag

- Jag ändrar rad-strängarna i `step7.inc` till mitt eget namn och laddar om — LCD:n visar min text.
- Jag mäter `/CS2` (VIA pin 23) medan jag stegar — den ska vara låg vid `$4000`–`$7FFF`.

## Så här felsöker man

Här är några saker jag kontrollerar:

1. Startar CPU:n inte? Ser jag `W $0` eller `W $1`? Då kontrollerar jag `BE` (HÖG), `PHI2` (pulser), `RESB` (HÖG efter reset).

2. Ser jag inga $4xxx-adresser? Då dubbelkollar jag 74HC00-kopplingen och att VIA:ns bussanslutningar sitter rätt.

3. Mät med multimeter:

- `PHI2` (CPU pin 37): ~2.`5V` medel (500 Hz fyrkant)
- `BE` (CPU pin 36): >4.8V
- VIA `/CS2` (pin 23): ska gå LÅG vid `$4000`–`$7FFF`
- VIA `VDD` (pin 20): >4.8V
- 74HC00 VCC (pin 14): >4.8V

4. Arduino som logikanalysator: jag kopplar `D8` till en mätpunkt och lägger till i `pulse()`:

```
Serial.print(" D8="); Serial.print(digitalRead(8));
```

5. Vanliga missar:

- `CS1` (VIA pin 24) flytande — måste ha +`5V`
- 74HC00 VCC/GND glömt
- Arduino driver databussen vid VIA-adresser — koden måste sätta `DDRA`=`0x00`
- Spänningsfall — mät `VDD` vid CPU, VIA och 74HC00 (alla >4.8V)

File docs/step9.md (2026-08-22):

# Riktigt RAM (62256 SRAM)

Att koppla in det första riktiga minneschippet känns som att ge datorn ett eget rum. Från och med nu är det äkta kisel som svarar när processorn knackar på.

## Mål

Hittills har Arduino emulerat allt minne — varje gång CPU:n läser eller skriver en byte är det Arduino som svarar. Det fungerar utmärkt för inlärning och felsökning, men en riktig dator har riktigt minne. Nu tar jag steget och kopplar in ett 62256 SRAM-chip — 32 kilobyte statiskt RAM i en DIP-28-kapsel.

SRAM-chippet tar över adresserna `$0000`–`$3FFF` (16 KB). Det täcker zero page, stacken och gott om utrymme för variabler. Arduino fortsätter att leverera programkoden från `$8000` och uppåt, samt vektorerna på `$FFFA`–`$FFFF`. VIA:n ligger kvar på `$4000`–`$400F`.

Den stora förändringen i koden: Arduino går *tri-state* (hög impedans) för alla adresser under `$4000`. När CPU:n läser från `$0200` är det SRAM-chippet som lägger ut data på bussen — inte Arduino. Jag har nu *tre enheter* som delar på databussen: SRAM, VIA och Arduino.

## Nya komponenter

Ett 62256 SRAM-chip på 32 KB — datorns första riktiga arbetsminne — plus en avkopplingskondensator och kopplingstrådar. Zero page, stack och variabler lämnar nu Arduinons mjukvaruemulering och hamnar i äkta kisel.

| Antal | Komponent |
|---|---|
| 1 | 62256 SRAM (32KB, DIP-28) |
| 1 | 100 nF keramisk kondensator (avkoppling SRAM) |
| – | Kopplingstråd (adress, data, kontroll) |

## 62256 SRAM — pinout

DIP-28-kapsel. 15 adresslinjer, 8 datalinjer, 3 kontrollsignaler. Här ser jag exakt hur kretsen ska vändas och vad varje pinne gör.
62256 SRAM pinout

## 74HC00 — pinout

DIP-14-kapsel. Alla fyra grindar används nu: U4A+U4B för VIA (steg 7), U4C+U4D för SRAM (steg 9).
74HC00 pinout

## Kopplingsschema

SRAM-chippet delar adress- och databuss med CPU, VIA och Arduino. Tre kontrollsignaler avgör vem som pratar.
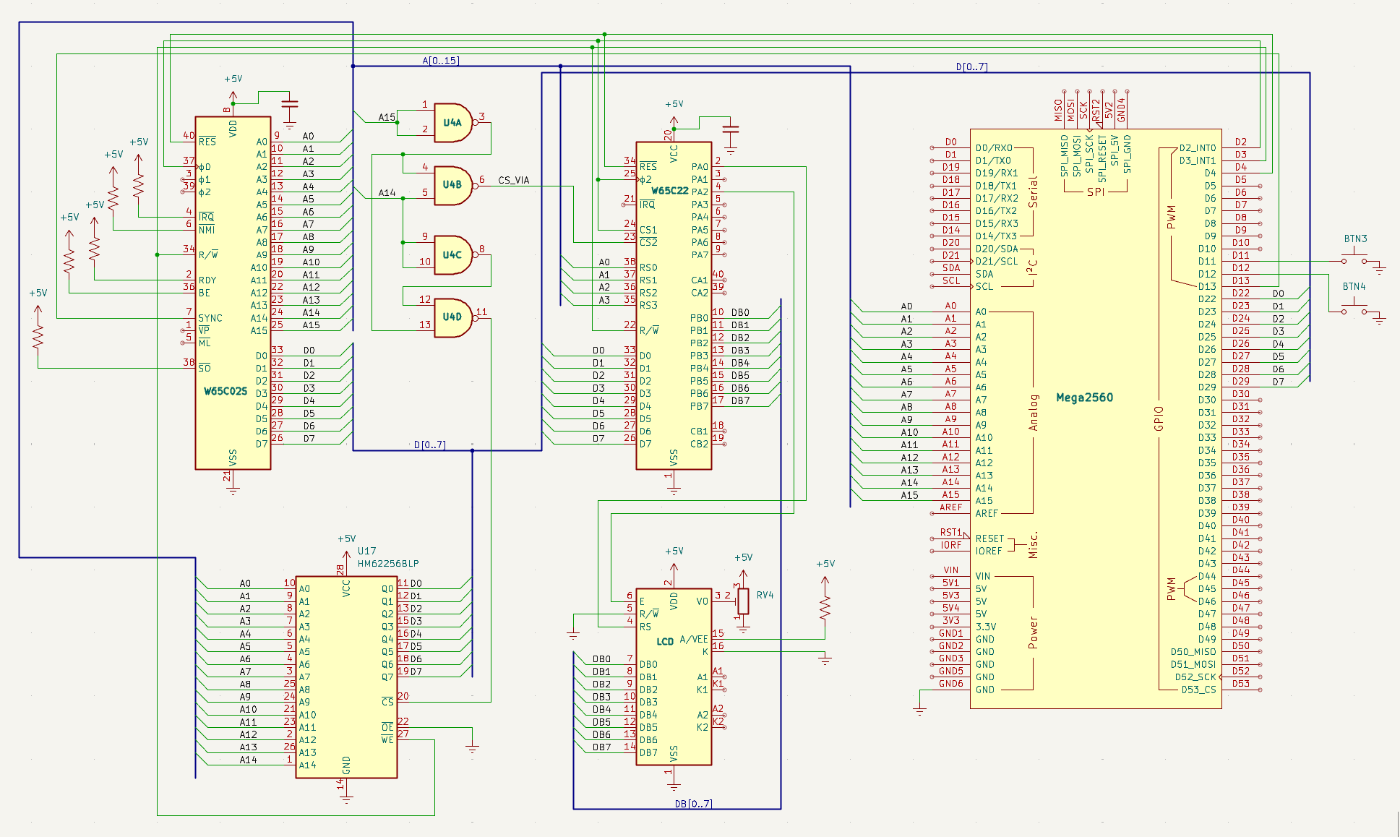
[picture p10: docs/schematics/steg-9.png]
Steg 9 — SRAM 62256


## Kopplingar

Tabellerna täcker nu fyra kretsar plus LCD:n, uppdelade efter funktion: ström och kontroll, adressbuss, databuss och övrigt. SRAM:ns avkodning presenteras för sig, eftersom U4C + U4D i **74HC00**:an är det enda nya i detta steg.

### 62256 SRAM

Här är alla kopplingar för SRAM-chippet. Avkopplingskondensatorn är markerad längst ner.

??? note "📦 Kopplingar — SRAM"

    | Pin | Signal | Kopplas till | Varför |
    |---|---|---|---|
    | 28 | `VDD` | +5V | Strömmatning — glöm inte 100nF avkoppling till GND |
    | 14 | `VSS` | GND | Systemjord |
    | 10–3, 25, 24, 21, 23, 2, 26, 1 | `A0–A14` | A0–A14 | 15 adresslinjer — SRAM behöver veta vilken byte CPU:n vill åt |
    | 11–13, 15–19 | `D0–D7` | D0–D7 (databuss) | 8 datalinjer — SRAM läser/skriver data här |
    | 20 | `/CE` | U4D pin 11 | Chip Enable — LÅG = SRAM aktivt. 74HC00 drar LÅG vid $0000–$3FFF |
    | 22 | `/OE` | GND | Output Enable — alltid LÅG (SRAM kör alltid ut data vid läsning) |
    | 27 | `/WE` | R/W (pin 34) | Write Enable — LÅG = skriv. CPU:ns R/W är LÅG vid skrivning |

### 74HC00 — adressavkodning för SRAM

Här är kopplingarna för U4C + U4D i **74HC00**:an. De avgör när SRAM ska svara på CPU:ns läs- och skrivförfrågningar.

??? note "📦 Kopplingar — SRAM-avkodning"

    | Pin | Signal | Kopplas till | Varför |
    |---|---|---|---|
    | VIA-avkodning (U4A + U4B — oförändrad från steg 7) |  |  |  |
    | 1, 2 | `A15` (in) | `A15` | Båda ingångarna till A15 → inverterare: ut = NOT A15 |
    | 3 | NOT `A15` (ut) | U4B pin 4 + U4D pin 13 | NOT A15 → till U4B och U4D |
    | 4 | NOT `A15` | U4A pin 3 (NOT A15) | NOT A15 |
    | 5 | `A14` (in) | `A14` | (NOT A15) NAND A14 → LÅG vid $4000–$7FFF |
    | 6 | VIA `/CS2` (ut) | VIA `/CS2` (pin 23) | VIA aktiveras vid $4000–$7FFF |
    | SRAM-avkodning (U4C + U4D — nytt i steg 9) |  |  |  |
    | 9, 10 | `A14` (in) | `A14` | Båda ingångarna till A14 → inverterare: ut = NOT A14 |
    | 8 | NOT `A14` (ut) | U4D pin 12 | NOT A14 → U4D ingång |
    | 12 | NOT `A14` | U4C pin 8 (NOT A14) | NOT A14 |
    | 13 | NOT `A15` | U4A pin 3 (NOT A15) | (NOT A14) NAND (NOT A15) → LÅG endast vid $0000–$3FFF |
    | 11 | SRAM `/CE` (ut) | SRAM `/CE` (pin 20) | SRAM aktiveras ENDAST vid $0000–$3FFF |
    | 14 | `VCC` | +5V | Strömmatning |
    | 7 | `GND` | GND | Systemjord |

### CPU, VIA och LCD

Här är kopplingarna för CPU, VIA och LCD — oförändrat från steg 7–8.

??? note "📦 Kopplingar — CPU, VIA, LCD"

    | Pin | Signal | Kopplas till | Varför |
    |---|---|---|---|
    | — ström och kontroll |  |  |  |
    | 8 | `VDD` | +5V | Strömmatning |
    | 21 | `VSS` | GND | Systemjord |
    | 37 | `PHI2` | Arduino D2 | Klocka — 500 Hz fyrkantsvåg |
    | 34 | `R/W` | Arduino D3, VIA pin 22, SRAM /WE | Read/Write — alla kretsar behöver veta |
    | 40 | `/RESET` | Arduino D4, VIA pin 34 | Reset |
    | 2 | `RDY` | +5V via 10kΩ | Ready — HÖG = kör |
    | 4 | `/IRQ` | +5V via 10kΩ | Interrupt — avaktiverad |
    | 6 | `/NMI` | +5V via 10kΩ | NMI — avaktiverad |
    | 36 | `BE` | +5V via 10kΩ | Bus Enable — HÖG = bussar aktiva |
    | 38 | `/SO` | +5V via 10kΩ | Set Overflow — avaktiverad |
    | — adressbuss (delas med SRAM, VIA, Arduino) |  |  |  |
    | 9–16 | `A0–A7` | Arduino A0–A7, SRAM A0–A7, VIA RS0–RS3 (A0–A3) | Låga adressbyte |
    | 17–20, 22–25 | `A8–A15` | Arduino A8–A15, SRAM A8–A14, 74HC00 | Höga adressbyte + avkodning |
    | — databuss (delas med SRAM, VIA, Arduino) |  |  |  |
    | 26–33 | `D0–D7` | Arduino D22–D29, SRAM D0–D7, VIA D0–D7 | 8-bit data — 100Ω seriemotstånd |
    | Övrigt |  |  |  |
    | 7 | `SYNC` | Arduino D13 | Opcode fetch |
    | — | BTN1 | Arduino D11 → GND | Klocksteg |
    | — | BTN2 | Arduino D12 → GND | Instruktionssteg |
    | VIA → LCD (oförändrat från steg 7) |  |  |  |
    | VIA 2 | `PA0` | 4 (RS) | Register Select |
    | VIA 4 | `PA2` | 6 (E) | Enable |
    | VIA 10–17 | `PB0–PB7` | 7–14 (DB0–DB7) | 8-bit data |
    | LCD — ström och kontrast |  |  |  |
    | 1 | `VSS` | GND | Jord |
    | 2 | `VDD` | +5V | Ström |
    | 3 | `VO` | Potentiometer mittben | Kontrast |
    | 5 | `R/W` | GND | Write-only |
    | 15 | `A` | +5V via 220Ω | Belysning + |
    | 16 | `K` | GND | Belysning − |

## Minneskarta

Nu har vi tre enheter som svarar på olika adressområden. **SRAM** tar den lägre halvan, **VIA** har sina 16 bytes, och **Arduino** levererar program och vektorer.

<div class="memmap">

      <div style="min-height:8px;display:flex;align-items:stretch;border-bottom:1px solid #e5e7eb">
        <div style="min-height:8px;width:5rem;padding-right:.75rem;display:flex;flex-direction:column;justify-content:space-between;text-align:right">
          <span style="color:#6b7280">$FFFF</span>
          <span style="color:#6b7280">$FFFA</small>
        </div>
        <div style="min-height:8px;flex:1 1 0%;background-color:#f3e8ff;border-left:1px solid #c4b5fd;border-right:1px solid #c4b5fd;padding-left:.5rem;padding-right:.5rem;display:flex;align-items:center">vectors[6] — NMI, RESET, IRQ (Arduino)</div>
        <div style="width:3.5rem;text-align:right;color:#6b7280;padding-right:.5rem">6 B</div>
      </div>
      <div style="height:200px;display:flex;align-items:stretch;border-bottom:1px solid #e5e7eb">
        <div style="width:5rem;text-align:right;padding-right:.75rem;color:#9ca3af;align-self:flex-start;padding-top:.25rem">$FFF9</div>
        <div style="flex:1 1 0%;background-color:#f3f4f6;padding-left:.5rem;padding-right:.5rem;display:flex;align-items:center;color:#9ca3af">oanvänt</div>
        <div style="width:3.5rem;text-align:right;color:#9ca3af;padding-right:.5rem;align-self:flex-start;padding-top:.25rem">~30 KB</div>
      </div>
      <div style="min-height:16px;display:flex;align-items:stretch;border-bottom:1px solid #e5e7eb">
        <div style="min-height:16px;width:5rem;padding-right:.75rem;display:flex;flex-direction:column;justify-content:space-between;text-align:right">
          <span style="color:#6b7280">$8800</span>
          <span style="color:#6b7280">$8000</span>
        </div>
        <div style="flex:1 1 0%;background-color:#dbeafe;border-left:1px solid #93c5fd;border-right:1px solid #93c5fd;padding-left:.5rem;padding-right:.5rem;display:flex;align-items:center">program[2048] — 6502-program (Arduino)</div>
        <div style="width:3.5rem;text-align:right;color:#6b7280;padding-right:.5rem">2 KB</div>
      </div>
      <div style="height:100px;display:flex;align-items:stretch;border-bottom:1px solid #e5e7eb">
        <div style="width:5rem;text-align:right;padding-right:.75rem;color:#9ca3af;align-self:flex-start;padding-top:.25rem">$7FFF</div>
        <div style="flex:1 1 0%;background-color:#f3f4f6;padding-left:.5rem;padding-right:.5rem;display:flex;align-items:center;color:#9ca3af">oanvänt (Arduino NOP-fallback)</div>
        <div style="width:3.5rem;text-align:right;color:#9ca3af;padding-right:.5rem;align-self:flex-start;padding-top:.25rem">~16 KB</div>
      </div>
      <div style="min-height:8px;display:flex;align-items:stretch;border-bottom:2px solid #d1d5db;border-bottom:2px solid #eab308">
        <div style="min-height:8px;width:5rem;padding-right:.75rem;display:flex;flex-direction:column;justify-content:space-between;text-align:right">
          <span style="color:#6b7280">$4010</span>
          <span style="color:#6b7280">$4000</span>
        </div>
        <div style="min-height:8px;flex:1 1 0%;background-color:#fef9c3;border-left:1px solid #facc15;border-right:1px solid #facc15;padding-left:.5rem;padding-right:.5rem;display:flex;align-items:center;font-weight:700">W65C22 VIA — fysisk I/O (steg 7)</div>
        <div style="width:3.5rem;text-align:right;color:#6b7280;padding-right:.5rem">16 B</div>
      </div>
      <div style="height:100px;display:flex;align-items:stretch;border-bottom:2px solid #d1d5db;border-bottom:2px solid #22c55e">
        <div style="min-height:8px;width:5rem;padding-right:.75rem;display:flex;flex-direction:column;justify-content:space-between;text-align:right">
          <span style="color:#6b7280">$3FFF</span>
          <span style="color:#6b7280">$0000</span>
        </div>
        <div style="flex:1 1 0%;background-color:#dcfce7;border-left:1px solid #4ade80;border-right:1px solid #4ade80;padding-left:.5rem;padding-right:.5rem;display:flex;align-items:center;font-weight:700">62256 SRAM — 16 KB riktigt RAM</div>
        <div style="width:3.5rem;text-align:right;color:#6b7280;padding-right:.5rem">16 KB</div>
      </div>
    
</div>

## Arduino-kod

Det här är slutsteget — och den mest genomgripande förändringen av minnesemulatorn sedan steg 3. Jag kopplar in ett SRAM-chip (32 KB statiskt RAM) som tar över adresserna `$0000–$3FFF`. Arduino måste nu *tri-stata databussen* för alla SRAM- och VIA-adresser — tre enheter delar på samma 8 datalinjer, och bara en får prata i taget.

### Tre enheter, en buss

Databussen (`D0–D7`) är nu ansluten till fyra kretsar samtidigt: CPU, Arduino, SRAM och VIA. Adressavkodningen med 74HC00 avgör vem som svarar:

- `$0000`–`$3FFF` → `is_sram()` returnerar `true`. Arduino rör inte bussen. SRAM-chippet läser och skriver helt på egen hand.
- `$4000`–`$400F` → `is_via()` returnerar `true`. Arduino rör inte bussen. VIA-kretsen hanterar I/O.
- `$8000`–`$FFFF` → Arduino svarar med programkod och vektorer. SRAM och VIA är inaktiva (deras `/CE`- och `/CS2`-signaler är höga).

Det här är en *riktig datorarkitektur*: flera enheter på en delad buss, styrda av adressavkodningslogik. Exakt så här fungerar modernare datorer också — bara med fler kretsar och högre hastigheter.

### `is_sram()` — den nya gränsen

`is_sram()` är lika enkel som `is_via()`: returnerar `true` om adressen är högst `$3FFF`. I `read_mem()` och `write_mem()` kontrolleras SRAM före allt annat — om adressen är under `$4000` gör Arduino ingenting. `pulse()` har nu tre villkor: `!is_sram(a) && !is_via(a)` — Arduino driver bussen endast när varken SRAM eller VIA gör det.

### Två programfaser

Koden är uppdelad i två faser som demonstrerar att SRAM fungerar:

1. Fas 1 — VIA/LCD-text: samma 4-radersprogram som tidigare. Visar att VIA och LCD fungerar med SRAM inkopplat. Programmet väntar sedan på ett knapptryck.
1. Fas 2 — Fibonacci: ett 6502-program som beräknar Fibonacci-sekvensen (0, 1, 1, 2, 3, 5, 8, 13, 21, 34, 55, 89, 144, 233) och visar varje tal på LCD:n. Programmet använder zero page (`$00–$02`) för att lagra variabler — minnesadresser som nu ligger i det fysiska SRAM-chippet, inte i Arduinons array.

### Vad som är nytt jämfört med steg 7–8

SRAM-chip, utökad med 74HC00-avkodning (U4C+U4D för SRAM). I koden: `is_sram()`, utökade villkor i `pulse()`/`read_mem()`/`write_mem()`, tvåfasigt programflöde i `setup()`, och Fibonacci-programmet byggt med ca65. `ram[1024]` från tidigare steg är borta — den har ersatts av äkta kisel.

??? note "📦 Arduino-kod"

    ```cpp
    --8<-- "Mega_2560_6502/src/step1.inc"
    ```

## 6502-programmet — Fibonacci i assembler

Det här programmet är intressantare än hello-programmet från steg 8 — det *beräknar* något. Fibonacci-sekvensen är en av matematikens mest berömda talserier: varje tal är summan av de två föregående. 0, 1, 1, 2, 3, 5, 8, 13, 21… och så vidare. Programmet räknar ut nästa tal, visar det på LCD:ns andra rad, pausar en stund, och gör om. Eftersom 6502:an är en 8-bitars processor ryms bara tal upp till 255 — när Fibonacci passerar 233 och försöker beräkna 377 (som är för stort) fångar programmet upp overflödet och börjar om från noll. LCD:n visar "Fib:" på första raden och det aktuella talet — 0, 1, 1, 2, 3… — på andra raden.

Strukturen känns igen från steg 8: 

1. konstanter överst
2. kod från `$8000`
3. subrutiner
4. strängdata och vektorsegment. 

Det nya är att programmet använder *zero page* — adresserna `$00` till `$02` — för att lagra Fibonacci-variablerna. Zero page är 6502:ans snabbaste minnesområde eftersom adresseringsläget bara kräver en byte. Här ligger F(n-2) på `$00`, F(n-1) på `$01`, och det nyberäknade F(n) på `$02`. Det är dessa adresser som i steg 9 ligger i det fysiska SRAM-chippet — inte i Arduinons array. När programmet läser `$00` eller skriver till `$02` är det äkta kisel som svarar.

Själva Fibonacci-beräkningen är förvånansvärt kort — bara en handfull instruktioner. Programmet rensar carry-flaggan med `CLC`, laddar F(n-2) med `LDA $00`, adderar F(n-1) med `ADC $01`, och kontrollerar om additionen spillde över med `BCC no_wrap`. Om carry är satt betyder det att talet blev större än 255 — då nollställs serien och loopen börjar om. Annars sparas resultatet, variablerna skiftas framåt (det gamla F(n-1) blir nya F(n-2), det nya F(n) blir F(n-1)), och talet visas på LCD:n. Varje varv i loopen avslutas med `JMP fib_loop` — tillbaka till början, nästa tal.

Den mest imponerande subrutinen är `show_num`. Den omvandlar ett 8-bitars tal till 1–3 ASCII-siffror genom att räkna hur många hundratal, tiotal och ental som ryms — en algoritm som liknar den jag lärde mig i grundskolan. Först subtraheras 100 upprepade gånger för att få fram hundratalet, sedan 10 för tiotalet, och resten är entalet. Varje siffra konverteras till ASCII genom att addera `'0'` (tecknet noll har ASCII-värdet 48). Efter utskriften skrivs två mellanslag — ett smart knep för att sudda bort gamla siffror när "144" följs av "5". Utan dem skulle displayen visa "544" där fjorton blev fem.

#### Så här visas tex 144

Jag följer `show_num` när A-registret innehåller 144 — talet som visas efter "Fib:":

1. Hundratal: 144 − 100 = 44, och X räknas upp till 1. 44 < 100, så subtraktionen slutar. X (1) + `'0'` = `'1'` → skriv ut.
1. Tiotal: 44 − 10 = 34 (X=1) → 24 (X=2) → 14 (X=3) → 4 (X=4). 4 < 10, klart. X (4) + `'0'` = `'4'` → skriv ut.
1. Ental: resten är 4 → `'4'` → skriv ut.
1. Städning: två mellanslag suddar bort resten av raden — nästa tal (5) skriver över utan att lämna kvar "1445".

### Nya instruktioner i det här programmet

Från steg 8 känner jag redan `LDA`, `STA`, `JSR`, `RTS`, `LDX`, `INX`, `BEQ` och `JMP`. Det här är vad som är nytt:

??? note "📦 Instruktioner i Fibonacci-programmet"

    | Instruktion | Exempel i programmet | Vad CPU:n gör |
    |---|---|---|
    | CLC / SEC | före ADC / SBC | Rensar/sätter carry-flaggan — förbereder addition respektive subtraktion. |
    | ADC $01 | F(n) = F(n-2) + F(n-1) | Adderar ett minnesvärde till A *inklusive* carry — grunden i Fibonacci-loopen. |
    | BCC no_wrap | efter ADC | Hoppar om carry = 0, dvs om summan rymdes i 8 bitar. Annars börjar serien om. |
    | SBC #100 | hundratal i show_num | Subtraherar 100 från A (med carry) — upprepas tills resten < 100. |
    | CMP #100 | "är A >= 100?" | Jämför A med ett värde utan att ändra A — flaggorna avgör sedan om jag hoppar. |
    | PHA / PLA | spara resten i show_num | Stacken: sparar A för att komma ihåg den och tar tillbaka den senare. |
    | TXA | räknaren → A | Kopierar X-registret till A så att räknaren kan skrivas ut. |
    | DEX / DEY | loopräknare | Minskar X/Y med 1 — i delay och i tiotal-uträkningen. |
    | BNE | loopar i show_num | Hoppar om resultatet inte är noll — avslutar räknar-looparna. |
    | LDA $00 / STA $02 | F-variablerna | Zero page-adressering — variabler i $00–$02 nås med bara en byte. |

??? note "📦 6502-programmet — program_fib.asm"

    ```asm
    --8<-- "Mega_2560_6502/asm/program_fib.asm"
    ```

Komplett assembler-kod: `Mega_2560_6502/asm/program_fib.asm`. Byggs med `ca65 + ld65 → program_fib.h → inkluderas av step9.inc`.

## Exempel på körning

När jag laddat upp koden körs två faser efter varandra. Först VIA/LCD-programmet, sedan — efter ett knapptryck — Fibonacci-programmet som använder det fysiska SRAM-chippet.

=== "Terminal"

    ```text
    Steg 9 — 62256 SRAM
    Fas 1: Laddar 4-raders VIA/LCD-program...
    Kor 1000 cykler (tyst)...
    Fas 1 klar — vantar pa knapptryck...
    ```

=== "LCD 16×2"

    ```text
    === Steg 9 SRAM ===
    Tryck pa knapp...
    ```

Jag trycker på valfri knapp för att gå vidare till Fibonacci:

=== "Terminal"

    ```text
    >>> Knapp 1 tryckt! <<<
    Laddar Fibonacci-program...
    Fibonacci-program kört.
    R $FFFC
    R $FFFD
    R $8000  ← OPCODE
    ...
    R $0000  ← SRAM (F(n-2))
    R $0001  ← SRAM (F(n-1))
    W $0002  ← SRAM (F(n))
    W $4000  ← VIA: 31  (siffran 1)
    W $4000  ← VIA: 34  (siffran 4)
    W $4000  ← VIA: 34  (siffran 4)
    ```

=== "LCD 16×2"

    ```text
    Fib:
    144
    ```
    
`144` är det tolfte Fibonacci-talet. Strax därefter kommer `233` — det sista som ryms i 8 bitar — sedan wrappar det.

Varje nytt Fibonacci-tal dyker upp med en kort paus. När talet når 233 (det sista som ryms i en 8-bitars byte) wrappar det tillbaka till 0 och sekvensen börjar om. Under tiden använder 6502-programmet zero page-adresser (`$00`, `$01`, `$02`) för att lagra F(n-2), F(n-1) och F(n) — adresser som nu ligger i det fysiska SRAM-chippet, inte i Arduinons mjukvaruemulerade RAM. I seriemonitor syns dessa som `R $0000` och `W $0002` med `← SRAM`-markering.

Jag har byggt en dator med tre kretsar som delar på samma buss, äkta SRAM för arbetsminne, en VIA för I/O, och en 6502-processor som kör mina egna assembler-program. Från en blinkande lysdiod till Fibonacci på LCD — hela resan på nio steg. Jag satt och tittade på 144 ett bra tag — det var mitt eget minne som räknat.

## Så här felsöker man

Här är några saker jag kontrollerar:

- Läser CPU:n `$0000` vid reset? Då är SRAM-chipets `/OE` inte `GND`. Utan `/OE`=LÅG driver SRAM inte ut data vid läsning.
- Databuss-krockar? Då får Arduino INTE sätta `DDRA`=`0xFF` vid SRAM-adresser. Jag kontrollerar att `is_sram()` returnerar rätt.
- Skriver SRAM inte? Då måste `/WE` gå till `R/W` (pin 34). Jag kontrollerar att `/CE` är avkodad korrekt via 74HC00.
- Glitchar på bussen? 62256 är snabbare än Arduino. Jag ser till att `/CE` och `/WE` är stabila innan databussen läses.

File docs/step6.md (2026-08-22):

# Eget 6502-program

Det är en speciell känsla första gången en dator jag byggt själv kör ett program jag skrivit själv. Nio bytes räcker för att få den känslan.

## Mål

Datorn är nu komplett — CPU, minne, LCD, knappar. Men den kör bara `NOP`:ar. Dags att skriva mitt första egna 6502-program!

Jag skriver en enkel räknare: öka X-registret från 0 till 255, spara värdet på adress `$0200`, och loopa. Programmet är bara 9 bytes stort — men det innehåller allt ett riktigt program behöver: initiering, beräkning, minnesskrivning och loop.

6502-program skrivs i *maskinkod* — varje instruktion är 1–3 bytes. 

- `LDX #$00` är två bytes (`$A2 $00`)
- `INX` är en byte (`$E8`)
- `STX $0200` är tre bytes (`$8E $00 $02`)

Jag skriver in dessa bytes direkt i Arduinons minnesarray, och CPU:n exekverar dem som ett riktigt program.

## Nya komponenter

Inga nya komponenter — samma koppling som steg 5. 

## Kopplingar

Samma fysiska koppling som steg 5 — ingenting har flyttats.

??? note "📦 Kopplingar — CPU, klocka, ström, adressbuss, reset, databuss och LCD"

    | Pin | Signal | Kopplas till | Varför |
    |---|---|---|---|
    | 8 | `VDD` | +5V | Strömmatning — CPU:ns driftspänning |
    | 21 | `VSS` | GND | Systemjord — sluten krets |
    | 37 | `PHI2` | Arduino D2 | Klockingång — Arduino skickar fyrkantsvåg |
    | 2 | `RDY` | +5V via 10kΩ | Ready — HÖG = CPU får köra |
    | 4 | `/IRQ` | +5V via 10kΩ | Interrupt request — HÖG = inget avbrott |
    | 6 | `/NMI` | +5V via 10kΩ | Non-maskable interrupt — måste vara HÖG |
    | 36 | `BE` | +5V via 10kΩ | Bus Enable — HÖG = bussarna aktiva |
    | 38 | `/SO` | +5V via 10kΩ | Set Overflow — avaktiverad |
    | 40 | `/RESET` | Arduino D4 | Kontrollerad reset |
    | 9–16 | `A0–A7` | Arduino A0–A7 | Låga adressbyte — läses via PORTF |
    | 17–20, 22–25 | `A8–A15` | Arduino A8–A15 | Höga adressbyte — läses via PORTK |
    | 34 | `R/W` | Arduino D3 | HÖG = CPU läser, LÅG = CPU skriver |
    | 33 | `D0` | Arduino D22 via 100Ω | Databit 0 (LSB) |
    | 32 | `D1` | Arduino D23 via 100Ω | Databit 1 |
    | 31 | `D2` | Arduino D24 via 100Ω | Databit 2 |
    | 30 | `D3` | Arduino D25 via 100Ω | Databit 3 |
    | 29 | `D4` | Arduino D26 via 100Ω | Databit 4 |
    | 28 | `D5` | Arduino D27 via 100Ω | Databit 5 |
    | 27 | `D6` | Arduino D28 via 100Ω | Databit 6 |
    | 26 | `D7` | Arduino D29 via 100Ω | Databit 7 (MSB) |
    | 7 | `SYNC` | Arduino D13 | HÖG = CPU:n hämtar ny opcode |
    | LCD 16×2 (parallell 4-bit) |  |  |  |
    | 1 | `VSS` | GND | Jord |
    | 2 | `VDD` | +5V | Strömmatning |
    | 3 | `VO` | Potentiometer mittben | Kontrast — sidoben till +5V och GND |
    | 4 | `RS` | Arduino D5 | Register Select — 0 = kommando, 1 = data |
    | 5 | `R/W` | GND | Alltid skrivläge |
    | 6 | `E` | Arduino D6 | Enable — Arduino pulserar för att skicka data |
    | 11 | `DB4` | Arduino D10 | Data bit 4 — omvänd ordning! |
    | 12 | `DB5` | Arduino D9 | Data bit 5 |
    | 13 | `DB6` | Arduino D8 | Data bit 6 |
    | 14 | `DB7` | Arduino D7 | Data bit 7 |
    | 15 | `A` | +5V via 220Ω | Bakgrundsbelysning + |
    | 16 | `K` | GND | Bakgrundsbelysning − |

## Kopplingsschema

Samma hårdvara som steg 5. LCD:n kopplas direkt till Arduino — `RS`→`D5`, E→`D6`, `DB4–DB7`→`D10`,`D9`,`D8`,`D7` (omvänd ordning).

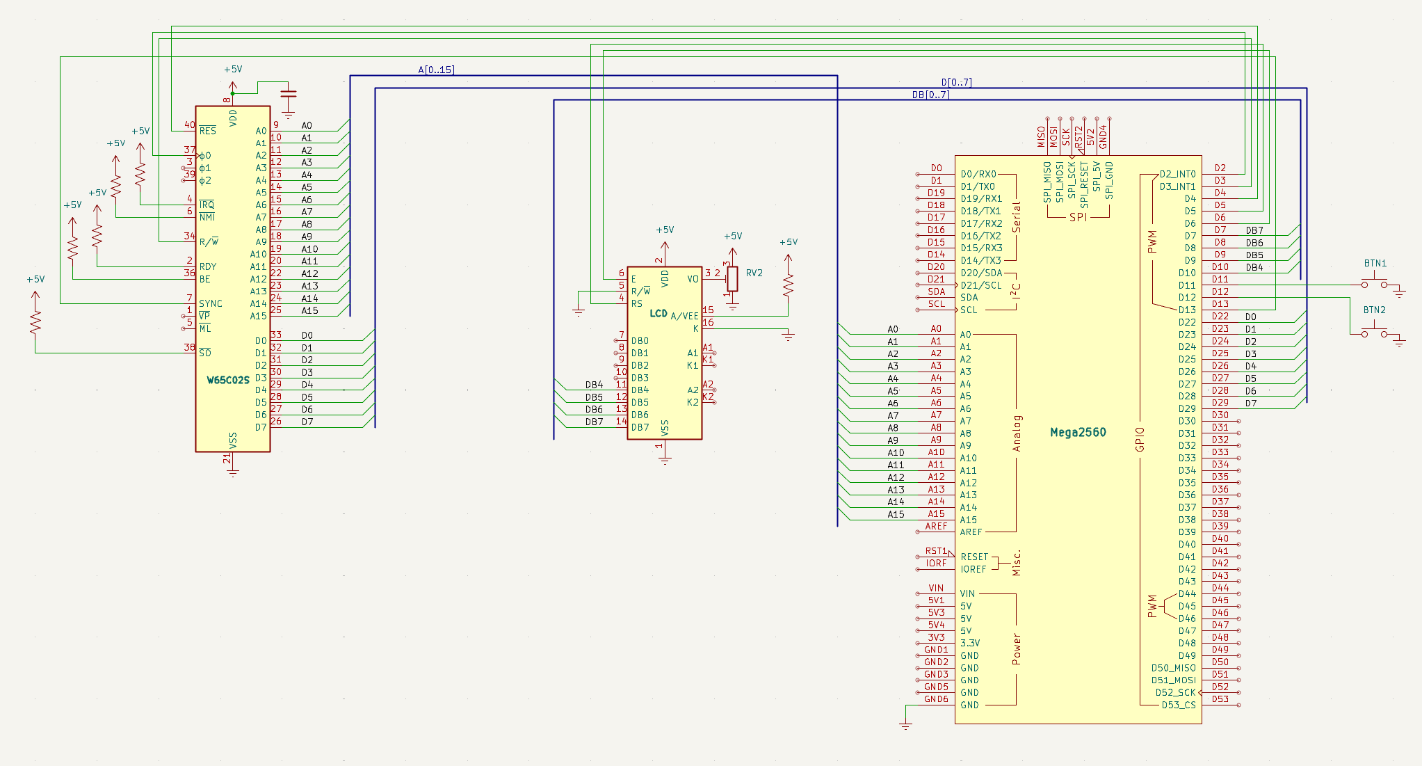
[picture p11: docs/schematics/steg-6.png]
Steg 6 — LCD kopplad till Arduino


## Minneskarta

**6502**-processorns 64 KB adressrymd, uppdelad i fyra områden:

- **Lila** (`$FFFA`–`$FFFF`): vektorer — processorn läser här efter reset för att veta var programmet börjar
- **Blå** (`$8000`–`$87FF`): vårt **6502**-program — 9 bytes maskinkod som **Arduino** laddar in från `setup()`
- **Grön** (`$0000`–`$03FF`): arbetsminne — zero page (`$0000`–`$00FF`, snabbast åtkomst), stack (`$0100`–`$01FF`, `JSR`/`RTS`/`PHA`/`PLA`), och ledigt **RAM** (`$0200`–`$03FF`). Här kan **CPU**:n läsa och skriva fritt
- **Grå**: oanvänt — **Arduino** returnerar `$EA` (`NOP`) så **CPU**:n hoppar bara vidare

<div class="memmap">

      <div style="min-height:8px;display:flex;align-items:stretch;border-bottom:1px solid #e5e7eb">
        <div style="min-height:8px;width:5rem;padding-right:.75rem;display:flex;flex-direction:column;justify-content:space-between;text-align:right">
          <span style="color:#6b7280">$FFFF</span>
          <span style="color:#6b7280">$FFFA</small>
        </div>
        <div style="min-height:8px;flex:1 1 0%;background-color:#f3e8ff;border-left:1px solid #c4b5fd;border-right:1px solid #c4b5fd;padding-left:.5rem;padding-right:.5rem;display:flex;align-items:center">vectors[6] — NMI, RESET, IRQ</div>
        <div style="width:3.5rem;text-align:right;color:#6b7280;padding-right:.5rem">6 B</div>
      </div>
      <div style="height:200px;display:flex;align-items:stretch;border-bottom:1px solid #e5e7eb">
        <div style="width:5rem;text-align:right;padding-right:.75rem;color:#9ca3af;align-self:flex-start;padding-top:.25rem">$FFF9</div>
        <div style="flex:1 1 0%;background-color:#f3f4f6;padding-left:.5rem;padding-right:.5rem;display:flex;align-items:center;color:#9ca3af">oanvänt (returnerar $EA = NOP)</div>
        <div style="width:3.5rem;text-align:right;color:#9ca3af;padding-right:.5rem;align-self:flex-start;padding-top:.25rem">~30 KB</div>
      </div>
      <div style="min-height:16px;display:flex;align-items:stretch;border-bottom:1px solid #e5e7eb">
        <div style="min-height:16px;width:5rem;padding-right:.75rem;display:flex;flex-direction:column;justify-content:space-between;text-align:right">
          <span style="color:#6b7280">$8800</span>
          <span style="color:#6b7280">$8000</span>
        </div>
        <div style="flex:1 1 0%;background-color:#dbeafe;border-left:1px solid #93c5fd;border-right:1px solid #93c5fd;padding-left:.5rem;padding-right:.5rem;display:flex;align-items:center">program[2048] — 6502-program</div>
        <div style="width:3.5rem;text-align:right;color:#6b7280;padding-right:.5rem">2 KB</div>
      </div>
      <div style="height:100px;display:flex;align-items:stretch;border-bottom:1px solid #e5e7eb">
        <div style="width:5rem;text-align:right;padding-right:.75rem;color:#9ca3af;align-self:flex-start;padding-top:.25rem">$7FFF</div>
        <div style="flex:1 1 0%;background-color:#f3f4f6;padding-left:.5rem;padding-right:.5rem;display:flex;align-items:center;color:#9ca3af">oanvänt</div>
        <div style="width:3.5rem;text-align:right;color:#9ca3af;padding-right:.5rem;align-self:flex-start;padding-top:.25rem">~16 KB</div>
      </div>
      <div style="min-height:8px;display:flex;align-items:stretch;border-bottom:1px solid #e5e7eb">
        <div style="min-height:8px;width:5rem;padding-right:.75rem;display:flex;flex-direction:column;justify-content:space-between;text-align:right">
          <span style="color:#6b7280">$0400</span>
          <span style="color:#6b7280">$0200</span>
        </div>
        <div style="min-height:8px;flex:1 1 0%;background-color:#dcfce7;padding-left:.5rem;padding-right:.5rem;display:flex;align-items:center">ram[1024] — ledigt RAM</div>
        <div style="width:3.5rem;text-align:right;color:#6b7280;padding-right:.5rem">512 B</div>
      </div>
      <div style="min-height:8px;display:flex;align-items:stretch;border-bottom:1px solid #e5e7eb">
        <div style="min-height:8px;width:5rem;padding-right:.75rem;display:flex;flex-direction:column;justify-content:space-between;text-align:right">
          <span style="color:#6b7280">$0200</span>
          <span style="color:#6b7280">$0100</span>
        </div>
        <div style="min-height:8px;flex:1 1 0%;padding-left:.5rem;padding-right:.5rem;display:flex;align-items:center">Stack (JSR/RTS, PHA/PLA)</div>
        <div style="width:3.5rem;text-align:right;color:#6b7280;padding-right:.5rem">256 B</div>
      </div>
      <div style="min-height:8px;display:flex;align-items:stretch">
        <div style="min-height:8px;width:5rem;padding-right:.75rem;display:flex;flex-direction:column;justify-content:space-between;text-align:right">
          <span style="color:#6b7280">$0100</span>
          <span style="color:#6b7280">$0000</span>
        </div>
        <div style="min-height:8px;flex:1 1 0%;padding-left:.5rem;padding-right:.5rem;display:flex;align-items:center">Zero page (snabbast)</div>
        <div style="width:3.5rem;text-align:right;color:#6b7280;padding-right:.5rem">256 B</div>
      </div>
    
</div>

## Arduino-kod

Datorn fungerar — men den har hittills bara kört `NOP`:ar. Nu skriver jag mitt första egna 6502-program. Det är bara 9 bytes stort, men det innehåller allt ett riktigt program behöver: initiering, beräkning, minnesskrivning och en loop. CPU:n kommer att räkna från 0 till 255 i en oändlig loop — och jag kommer att kunna följa varje steg.

Lägg märke till: programmet körs på 6502-processorn — Arduino laddar bara in byten i sin minnesarray och genererar klockan. Precis som tidigare är Arduino minnesemulator, inte exekverare.

### 6502-maskinkod — så här ser ett program ut

En 6502-instruktion är 1–3 bytes lång. Första byten är alltid *opcode* — en siffra som talar om för CPU:n vad den ska göra. Resten är *operander* — data eller adresser som instruktionen behöver. Vårt program har fyra instruktioner:

| Instruktion | Bytes | Vad CPU:n gör |
|---|---|---|
| LDX #$00 | A2 00 | Ladda X-registret med 0. X är min räknare. `#` betyder "omedelbart värde" — använd siffran 0, inte en minnesadress. Den här instruktionen körs bara en gång. |
| INX | E8 | Öka X med 1. En enda byte, ingen operand. Det här är loopens startpunkt — hit hoppar jag tillbaka. |
| STX $0200 | 8E 00 02 | Spara X-registrets värde till minnesadress $0200. Notera: låg byte ($00) kommer före hög byte ($02). 6502 är *little-endian*. |
| JMP $8002 | 4C 02 80 | Hoppa tillbaka till INX. Återigen: låg byte först ($02), hög byte sen ($80). Utan denna instruktion skulle CPU:n bara fortsätta rakt fram genom minnet. |

### Arduino-koden — bara `setup()` ändras

`pulse()`, `loop()` och LCD-koden är helt oförändrade från steg 5. Det enda som ändras är programladdningen i `setup()`.

- Istället för en enda `write_mem(0x8000, 0xEA)` skriver jag nu 9 bytes — en i taget, på stigande adresser från `$8000`. 
- Varje `write_mem()` placerar en byte i Arduinons `program[]`-array, och CPU:n kommer att läsa dem som instruktioner.

### Vad jag ser på LCD:n

När programmet körs kan jag med Knapp 2 (instruktionssteg) följa programflödet: `$8000` (`LDX`) → `$8002` (`INX`) → `$8003` (`STX`) → `$8006` (`JMP`) → `$8002` (`INX` igen). Varje varv genom loopen ökar värdet på adress `$0200` — och jag kan se det på LCD:ns rad 1 som `D:$01`, `D:$02`, `D:$03`… hela vägen upp till `D:$FF` (255). Sedan wrappar X-registret till 0 och loopen börjar om.

??? note "📦 Arduino-kod"

    ```cpp
    --8<-- "Mega_2560_6502/src/step1.inc"
    ```

## Exempel på körning

När jag laddat upp koden och trycker på Knapp 2 (instruktionssteg) ser jag programmet rulla genom adresserna — både i seriemonitor och på LCD-displayen:

=== "Terminal"

    ```text
    Steg 6 — Räknarprogram
    Program: LDX #$00 · INX · STX $0200 · JMP $8002

    R $FFFC
    R $FFFD
    R $8000
    R $8001
    R $8002
    R $8003
    R $8004
    R $8005
    W $0200
    R $8006
    R $8007
    R $8008
    R $8002  ← tillbaka till INX
    ...
    ```

=== "LCD 16×2"

    ```text
    A:$0200
    D:$05
    ```
Adress `$0200` håller räknarens värde. Efter 5 varv genom loopen visar `D:$05`.

För första gången ser jag ett W i loggen! CPU:n *skriver* till adress `$0200` — det är `STX $0200` som sparar X-registrets värde. På LCD:ns rad 1 ser jag `D:$01`, `D:$02`, `D:$03`… räknaren ökar för varje varv. När den når `D:$FF` (255) wrappar den till `D:$00` — X-registret är bara 8 bitar brett.

## Så här felsöker man

Här är några saker jag kontrollerar:

- Kör CPU:n `NOP` istället? Då har jag glömt att ladda det nya programmet. Jag kontrollerar `write_mem()`-anropen i `setup()`.
- Hoppar CPU:n till fel adress? Då är `JMP`-adressen fel. `$8002` är `$02 $80` (låg byte först!).
- Stannar programmet? Då kanske jag har en `BRK`-instruktion (`0x00`) någonstans. Jag dubbelkollar att alla bytes är korrekta.

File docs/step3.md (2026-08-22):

# Databuss och minne

Utan databuss är processorn blind — den pekar på saker den aldrig får se. Det här steget är datorns födelse: nu svarar någon på frågorna.

## Mål

Hittills har CPU:n kunnat tala om *var* den vill läsa mha adressbussen. Nu kopplar jag in databussen — 8 ledningar som bär den faktiska informationen mellan CPU:n och minnet. Utan databuss kan CPU:n inte hämta instruktioner och är helt blind.

Jag kopplar också in `R/W`-signalen (pin 34). Den talar om ifall CPU:n vill läsa (HÖG) eller skriva (LÅG). Arduinon använder denna för att veta om den ska skicka data till CPU:n eller ta emot.

Arduinon blir nu en *minnesemulator*: en array `ram[1024]` lagrar data, och i varje klockcykel kollar Arduinon adressen och `R/W` — om CPU:n läser, lägger den ut rätt byte på databussen via `PORTA`. Om CPU:n skriver, läser Arduinon av vad som skrevs.

Jag laddar ett minimalt 6502-program på `$8000`: en enda `NOP`-instruktion (`$EA`) som gör ingenting och går vidare till nästa adress — vilket också är `NOP`. Resultat: CPU:n loopar för evigt, och jag kan följa varje steg i seriemonitor.

## Nya komponenter

Databussen är den första känsliga kretskopplingen i projektet: åtta 100Ω-motstånd som skyddar mot busskollisioner mellan CPU och Arduino, plus en kopplingstråd för `R/W`-signalen som talar om vem som skickar data åt vilket håll.

| Antal | Komponent |
|---|---|
| 8 | 100 Ω motstånd (databuss-skydd) |
| 1 | Kopplingstråd (R/W) |

## Kopplingsschema

Nu är datorn komplett i grunden: adressbuss från steg 2, databuss `D0–D7` via 100Ω-skydd till Arduino `D22–D29`, och `R/W`-signalen från CPU pin 34 till Arduino `D3`. 

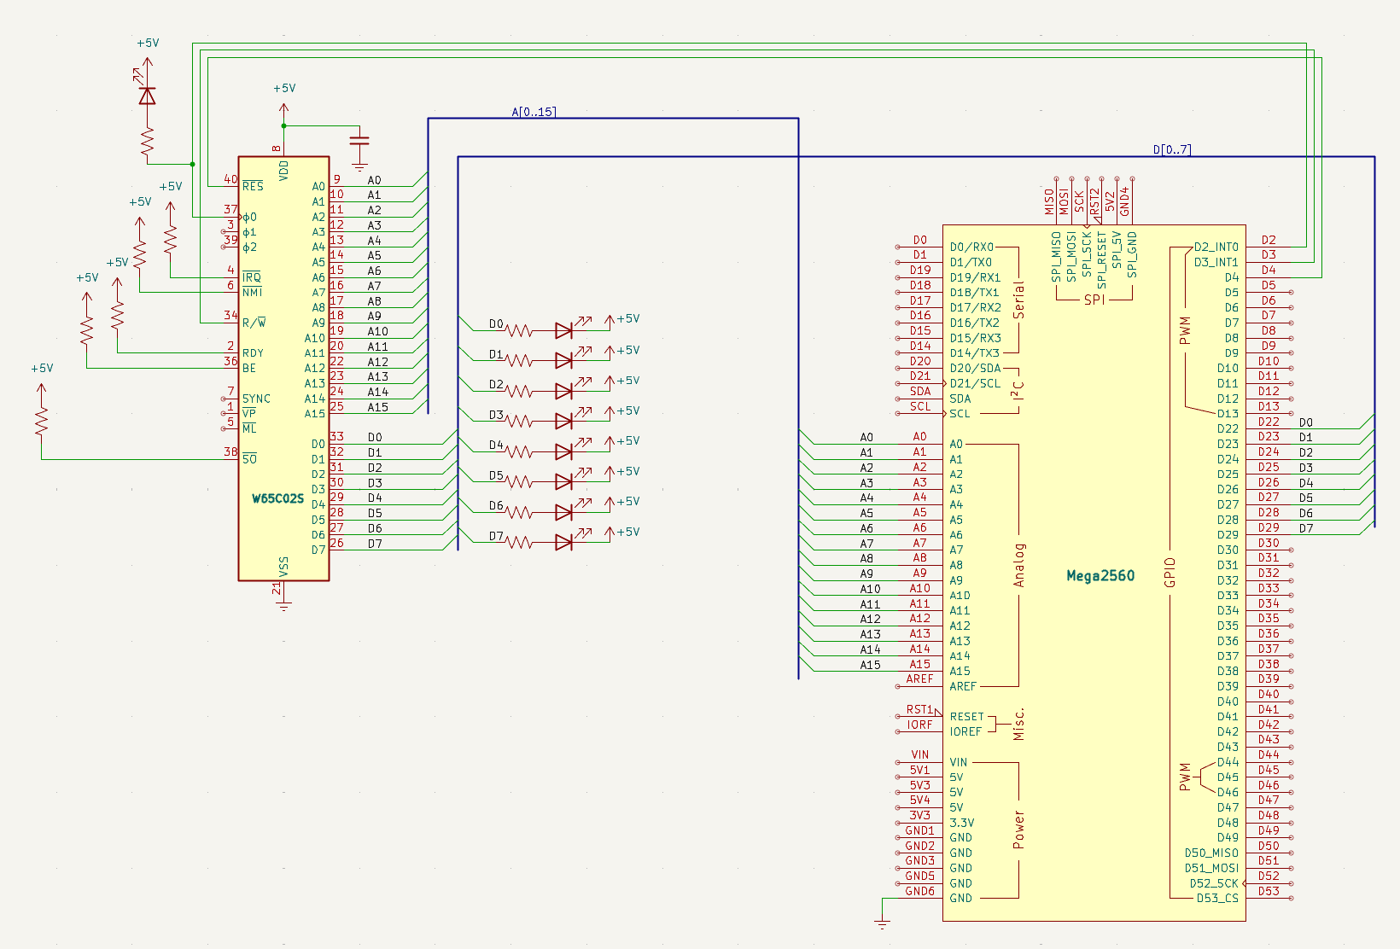
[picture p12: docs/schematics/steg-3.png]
Steg 3 — databuss och minne


## Kopplingar

Här är varenda koppling i steg 3, pinne för pinne.

??? note "📦 Kopplingar — CPU, klocka, ström, adressbuss, reset och databuss"

    | Pin | Signal | Kopplas till | Varför |
    |---|---|---|---|
    | 8 | `VDD` | +5V | Strömmatning — CPU:ns driftspänning |
    | 21 | `VSS` | GND | Systemjord — sluten krets |
    | 37 | `PHI2` | Arduino D2 | Klockingång — Arduino skickar fyrkantsvåg |
    | 2 | `RDY` | +5V via 10kΩ | Ready — HÖG = CPU får köra. Utan denna stannar CPU:n |
    | 4 | `/IRQ` | +5V via 10kΩ | Interrupt request — HÖG = inget avbrott |
    | 6 | `/NMI` | +5V via 10kΩ | Non-maskable interrupt — måste vara HÖG |
    | 36 | `BE` | +5V via 10kΩ | Bus Enable — HÖG = bussarna aktiva. Utan denna är CPU:n bortkopplad! |
    | 38 | `/SO` | +5V via 10kΩ | Set Overflow — avaktiverad |
    | 40 | `/RESET` | Arduino D4 | Kontrollerad reset — Arduino håller CPU:n i reset tills jag är redo |
    | 9–16 | `A0–A7` | Arduino A0–A7 | Låga adressbyte — läses via PORTF |
    | 17–20, 22–25 | `A8–A15` | Arduino A8–A15 | Höga adressbyte — läses via PORTK |
    | 34 | `R/W` | Arduino D3 | HÖG = CPU läser, LÅG = CPU skriver. Arduino måste veta detta |
    | 33 | `D0` | Arduino D22 via 100Ω | Databit 0 (LSB) |
    | 32 | `D1` | Arduino D23 via 100Ω | Databit 1 |
    | 31 | `D2` | Arduino D24 via 100Ω | Databit 2 |
    | 30 | `D3` | Arduino D25 via 100Ω | Databit 3 |
    | 29 | `D4` | Arduino D26 via 100Ω | Databit 4 |
    | 28 | `D5` | Arduino D27 via 100Ω | Databit 5 |
    | 27 | `D6` | Arduino D28 via 100Ω | Databit 6 |
    | 26 | `D7` | Arduino D29 via 100Ω | Databit 7 (MSB) |

## Arduino-kod

Det här är det största kodsteget hittills och det viktigaste. Arduino går från att vara en passiv observatör till att bli en *fullvärdig minnesemulator*. CPU:n kommer att ställa frågor via adressbussen, och Arduino måste svara med rätt byte på databussen — allt inom loppet av en enda klockcykel. När det fungerar har jag en dator som faktiskt kör ett program.

### Databussen — 8 ledningar som bär information

Adressbussen talar om *var* CPU:n vill läsa. Databussen bär *vad* som ska läsas eller skrivas. Det är 8 ledningar — `D0` till `D7` — och de är *dubbelriktade*. Ibland driver CPU:n dem (vid skrivning), ibland Arduino (vid läsning). 

### `R/W`-signalen — vem som pratar

CPU:ns pin 34 (`R/W`) är trafikljuset på bussen. 

- När `R/W` är HÖG vill CPU:n läsa — Arduino ska då sätta `DDRA = 0xFF` (alla pinnar som utgångar) och lägga ut rätt byte på `PORTA`. 
- När `R/W` är LÅG vill CPU:n skriva — Arduino måste omedelbart sätta `DDRA = 0x00` (tri-state, hög impedans) så att CPU:n kan driva ledningarna utan motstånd. Det här skiftet sker i *varje klockcykel*, mitt i `pulse()`.

### Kodens fyra lager

1. `read_mem()` och `write_mem()` — två enkla funktioner som slår upp eller sparar en byte i rätt array. Vektorer hamnar i `vectors[6]`, arbetsminne i `ram[1024]`. Allt annat returnerar `$EA` (`NOP`) — en ofarlig fallback som gör att CPU:n bara hoppar vidare om den läser från en oanvänd adress. 
1. `pulse()` — datorns hjärta — samma struktur som tidigare men nu med ett avgörande tillägg: efter att ha läst adress och `R/W` bestämmer den om Arduino ska driva databussen (`DDRA = 0xFF`) eller gå ur vägen (`DDRA = 0x00`). Allt detta sker medan `PHI2` är låg. När `PHI2` sedan går hög läser CPU:n av databussen — eller skriver till den.
1. `setup()` — ladda programmet — här skrivs reset-vektorn (`$8000`) och en enda `NOP`-instruktion (`$EA`) in i minnet. Det är mitt första 6502-program: CPU:n startar på `$8000`, läser `$EA`, gör ingenting, går till `$8001`, läser `$EA` (minnet returnerar `NOP` överallt), och loopar för evigt.
1. `loop()` — anropar bara `pulse()`. En klockcykel per varv, med fullständig loggning i seriemonitor.

### Vad som är nytt jämfört med steg 2

Tre stora nyheter: 

- `R/W`-signalen kopplas in på `D3`, databussen på `D22–D29` via 100Ω, och minnesarrayerna `ram[]` och `vectors[]` gör att Arduino kan svara med olika data på olika adresser. 
- `pulse()` är nu en fullständig buss-emulator — det är den här funktionen som kommer att följa med oss genom resten av projektet.

??? note "📦 Arduino-kod"

    ```cpp
    --8<-- "Mega_2560_6502/src/step1.inc"
    ```

## Exempel på körning

När jag öppnar seriemonitor (115200 baud) ser jag CPU:n läsa reset-vektorn och sedan loopa på `NOP`:

```text title="Terminal"
Steg 3 — databuss och minnesemulering
R $FFFC
R $FFFD
R $8000
R $8001
R $8002
R $8003
R $8004
...
```

Alla rader börjar med `R` — CPU:n gör inget annat än att läsa, eftersom `NOP` varken skriver till minnet eller ändrar några register. Adresserna räknas uppåt: `$8000`, `$8001`, `$8002`… och eftersom minnet returnerar `$EA` (`NOP`) på alla adresser utanför programmet, kommer CPU:n att vandra genom hela adressrymden — upp till `$FFFF`, sedan börja om från `$0000` — i en oändlig loop.

Det ser kanske händelselöst ut, men varje rad i loggen är ett mirakel: Arduino har läst adressbussen, kollat `R/W`, slagit upp rätt byte i minnet, och lagt ut den på databussen — allt innan CPU:n hann märka någon fördröjning. Jag tittar på en fungerande dator vars program är att göra ingenting — och det är ögonblicket jag förstår att jag byggt en riktig dator.

## Så här felsöker man

Här är några saker jag kontrollerar:

- Ser jag `W $0` eller `W $1`? Då driver CPU:n inte bussarna. Jag kontrollerar `BE` (måste vara HÖG) och att `PHI2` når CPU:n.
- Ser jag `R $FFFC` men inget mer? Då är databussen felaktig. Jag kontrollerar `D22–D29` och att 100Ω-motstånden sitter på alla 8 ledningar.
- Hoppar CPU:n till konstig adress? Då är reset-vektorn fel. Jag dubbelkollar `write_mem(0xFFFC, 0x00)` och `write_mem(0xFFFD, 0x80)`.
- Jag glömmer inte 100Ω:en! Utan seriemotstånd kan en enda felaktig `DDRA`-inställning förstöra CPU:n eller Arduino.

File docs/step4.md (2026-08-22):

# Manuell stegning

Att se en processor arbeta i ultrarapid är som att titta på en myrstack: först bara rörelse, sedan mönstret. Med två knappar får jag pausknappen på hela datorn och kan följa stegvis vad som händer.

## Mål

I steg 3 körde CPU:n fritt i en `NOP`-loop — kul att se, men svårt att felsöka. Nu kopplar jag in två tryckknappar och `SYNC`-signalen för att kunna styra exekveringen manuellt. Det här är en av de stora fördelarna med **W65C02S**: eftersom den är statisk CMOS kan klockan stoppas hur länge som helst.

Knapp 1 (klocksteg): varje tryckning ger en enda klockcykel. Perfekt för att se vad som händer på bussen i ultrarapid.

Knapp 2 (instruktionssteg): kör klockan tills CPU:n signalerar att en ny instruktion har hämtats. `SYNC`-pinnen (pin 7) går HÖG vid varje opcode fetch. Jag pulserar klockan tills `SYNC` går hög — då vet jag att CPU:n är i början av nästa instruktion.

## Nya komponenter

Två tryckknappar och en kopplingstråd för `SYNC` — det är allt. 

| Antal | Komponent |
|---|---|
| 2 | Tryckknappar |
| 1 | Kopplingstråd (SYNC → D13) |

## Kopplingsschema

Schemat visar de två tryckknapparna: en mellan Arduino `D11` och `GND` för klocksteg, en mellan `D12` och `GND` för instruktionssteg. Dessutom löper `SYNC`-signalen från CPU pin 7 till Arduino `D13`. Allt annat är oförändrat från steg 3.

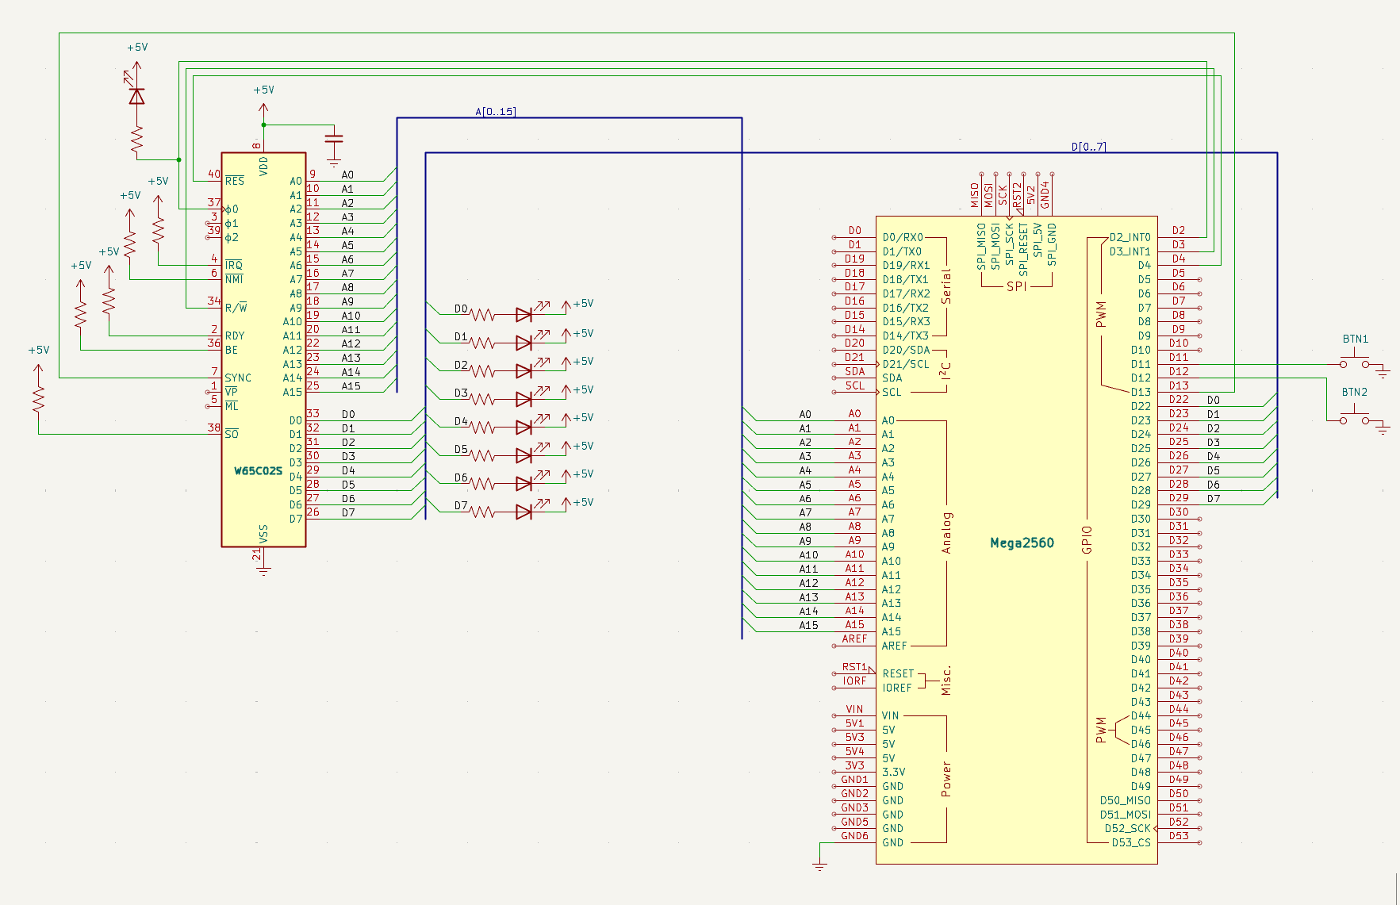
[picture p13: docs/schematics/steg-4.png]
Steg 4 — manuell stegning


## Kopplingar

Här är varenda koppling i steg 4, pinne för pinne.

??? note "📦 Kopplingar — CPU, klocka, ström, adressbuss, reset, databuss och knappar"

    | Pin | Signal | Kopplas till | Varför |
    |---|---|---|---|
    | 8 | `VDD` | +5V | Strömmatning — CPU:ns driftspänning |
    | 21 | `VSS` | GND | Systemjord — sluten krets |
    | 37 | `PHI2` | Arduino D2 | Klockingång — Arduino skickar fyrkantsvåg |
    | 2 | `RDY` | +5V via 10kΩ | Ready — HÖG = CPU får köra. Utan denna stannar CPU:n |
    | 4 | `/IRQ` | +5V via 10kΩ | Interrupt request — HÖG = inget avbrott |
    | 6 | `/NMI` | +5V via 10kΩ | Non-maskable interrupt — måste vara HÖG |
    | 36 | `BE` | +5V via 10kΩ | Bus Enable — HÖG = bussarna aktiva. Utan denna är CPU:n bortkopplad! |
    | 38 | `/SO` | +5V via 10kΩ | Set Overflow — avaktiverad |
    | 40 | `/RESET` | Arduino D4 | Kontrollerad reset — Arduino håller CPU:n i reset tills jag är redo |
    | 9–16 | `A0–A7` | Arduino A0–A7 | Låga adressbyte — läses via PORTF |
    | 17–20, 22–25 | `A8–A15` | Arduino A8–A15 | Höga adressbyte — läses via PORTK |
    | 34 | `R/W` | Arduino D3 | HÖG = CPU läser, LÅG = CPU skriver. Arduino måste veta detta |
    | 33 | `D0` | Arduino D22 via 100Ω | Databit 0 (LSB) |
    | 32 | `D1` | Arduino D23 via 100Ω | Databit 1 |
    | 31 | `D2` | Arduino D24 via 100Ω | Databit 2 |
    | 30 | `D3` | Arduino D25 via 100Ω | Databit 3 |
    | 29 | `D4` | Arduino D26 via 100Ω | Databit 4 |
    | 28 | `D5` | Arduino D27 via 100Ω | Databit 5 |
    | 27 | `D6` | Arduino D28 via 100Ω | Databit 6 |
    | 26 | `D7` | Arduino D29 via 100Ω | Databit 7 (MSB) |
    | 7 | `SYNC` | Arduino D13 | HÖG = CPU:n hämtar första byten av ny instruktion |

## Arduino-kod

I steg 3 körde CPU:n fritt i en loop — spännande men omöjligt att felsöka. Nu ger jag mig själv full kontroll över exekveringen med två fysiska knappar. Jag kan stega genom programmet i min egen takt.

### `SYNC` — processorns "nu börjar jag"-signal

CPU:ns pin 7 (`SYNC`) är en av de mest användbara signalerna på hela kretsen. Den går HÖG under den klockcykel då processorn hämtar första byten av en ny instruktion (opcode fetch). Varje gång jag ser `SYNC` tändas vet jag att CPU:n precis har påbörjat nästa instruktion — oavsett om det är en enkel `NOP` eller en komplex adresseringsmod. 

### Två knappar, två olika beteenden

Koden ändrar bara `loop()` och lägger till några nya pinkonstanter — allt annat är oförändrat från steg 3. Så här fungerar knapparna:

- Knapp 1 (`D11`) — klocksteg: varje tryckning ger exakt en klockcykel. Jag ser en ny rad i seriemonitor för varje tryck. Perfekt för att inspektera bussen.
- Knapp 2 (`D12`) — instruktionssteg: pulserar klockan tills `SYNC` går hög. Då vet jag att CPU:n är i början av nästa instruktion. En enda tryckning kan generera flera klockcykler (t.ex. 4 cykler för en `NOP`), men stannar alltid på en instruktionsgräns.

### Debounce — att hantera kontaktstudsar

När jag trycker på en mekanisk knapp studsar metallkontakterna mikroskopiskt — en enda tryckning kan generera dussintals snabba på/av-signaler. Utan debounce skulle CPU:n ta flera steg per tryck. Lösningen är enkel: `delay(50)` efter att knappen detekterats, vänta på att den släpps, och `delay(50)` igen. `INPUT_PULLUP` gör att Arduinons inbyggda pull-up-motstånd används — knappen kopplas direkt mellan pinne och `GND`, inga externa motstånd behövs.

### Vad som är nytt jämfört med steg 3

`SYNC`-pinnen kopplas in på `D13`. `loop()` ändras från en enkel `pulse()`-loop till knappläsning med debounce. Instruktionsstegningen (`do { pulse(); } while (!digitalRead(SYNC))`) är en av de smartaste kodraderna i hela projektet — den låter mig kliva genom mitt program instruktion för instruktion, precis som en debugger, fast i hårdvara.

??? note "📦 Arduino-kod"

    ```cpp
    --8<-- "Mega_2560_6502/src/step1.inc"
    ```

## Exempel på körning

Efter uppladdning händer ingenting förrän jag trycker på en knapp. CPU:n har precis lämnat reset och står stilla — klockan genereras bara när jag ber om det. Här är vad jag ser vid olika tryck:

```text title="Terminal"
Steg 4 — Knappstegning
Knapp 1 = klocksteg, Knapp 2 = instruktionssteg

[Knapp 1 trycks]
R $FFFC
[Knapp 1 trycks igen]
R $FFFD
[Knapp 1 trycks igen]
R $8000
[Knapp 2 trycks — flera cykler körs automatiskt]
R $8001
R $8002
R $8003
R $8004
```

Med Knapp 1 får jag en rad per tryck. Jag kan se reset-vektorn hämtas — `$FFFC`, `$FFFD` — och sedan följa CPU:n när den läser `NOP`-instruktioner. Med Knapp 2 körs flera rader samtidigt tills `SYNC` går hög, vilket för en `NOP` (`$EA`) betyder 2 klockcykler.

Jag har nu full kontroll. Jag kan stanna hur länge jag vill, mäta spänningar, fundera på vad som händer — och sedan trycka igen. Det är fortfarande mitt favoritsätt att felsöka.

## Så här felsöker man

Här är några saker jag kontrollerar:

- Gör knapparna inget? Då kontrollerar jag att `INPUT_PULLUP` är satt, och att knappen sitter mellan rätt pinne och `GND`.
- Flera steg per tryck? Då är debounce-tiden (50 ms) för kort. Jag ökar till 100 ms.
- Stannar Knapp 2 aldrig? Då är `SYNC` inte inkopplad eller på fel pinne. Jag mäter CPU pin 7 — den ska gå HÖG periodiskt.

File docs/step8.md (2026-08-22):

# Assembler-bygge med ca65

Att skriva 6502-kod i hex-bytes fungerar, men det är supersegt. Nu skriver jag i assembler.

## Mål

Hittills har jag skrivit 6502-program som hårdkodade hex-bytes direkt i Arduinons `setup()`. Det fungerar — men det är inte hållbart i längden. Nu tar jag steget till *riktig assembler* med **ca65**, en professionell 6502-assembler från **cc65**-verktygslådan.

Ingen ny hårdvara. Samma kopplingar som steg 7. Allt nytt finns i byggkedjan.

Arbetsflödet blir:

1. Skriv 6502-kod i `asm/program_hello.asm` — med labels, subrutiner och kommentarer
1. PlatformIO kör `ca65` + `ld65` före C++-kompileringen
1. Resultatet (`program_hello.bin`) konverteras till en C-header (`program.h`)
1. `setup()` läser `PROGRAM[]` och laddar in i minnesemulatorn

## Nya verktyg

Ingen ny hårdvara — bara mjukvara. Dessa två program installerar jag en gång, sedan bara rullar det på.

| Verktyg | Installation |
|---|---|
| ca65 / ld65 | `sudo apt install cc65` (Linux) eller ladda ner från [cc65.github.io (Windows) |
| Python 3 | Redan installerat med PlatformIO |

## Byggkedjan

Så här går min assembler-kod från en textfil till körbar kod i processorn. Tre steg, helt automatiskt — PlatformIO sköter allt.

## PlatformIO-byggskript

`scripts/build_asm.py` är en *pre-build hook* som PlatformIO kör före C++-kompileringen. Den anropar ca65, ld65 och bin2h.py i sekvens, konfigurerad i `platformio.ini`:

``` title="Terminal"
extra_scripts = pre:scripts/build_asm.py
```

??? note "📦 Byggskriptet — build_asm.py"

    ```python
    --8<-- "Mega_2560_6502/scripts/build_asm.py"
    ```

### bin2h.py — binär till C-header

Konverterar `program_hello.bin` till `PROGRAM[]` (en `PROGMEM`-array) som `main.cpp` inkluderar.

??? note "📦 Byggskriptet — bin2h.py"

    ```python
    --8<-- "Mega_2560_6502/scripts/bin2h.py"
    ```

## Så här använder jag det

1. Redigera assembler-koden:

``` title="Terminal"
nano asm/program_hello.asm
```

2. Bygg och ladda upp (Windows-maskinen):

``` title="Terminal"
pio run -e step8 -t upload -t monitor
```

Viktigt: `platformio.ini` måste ha `build_src_filter = +<*> -<program.asm>` för att förhindra att AVR-assemblern försöker kompilera 6502-koden.

Vid varje bygge körs `ca65` → `ld65` → `bin2h.py` automatiskt. Ändrar jag `program_hello.asm` byggs allt om.

## 6502-programmet i assembler

Det här programmet körs på 6502-processorn — inte på Arduino. Det är skrivet i ren assembler för **W65C02** och pratar direkt med VIA-kretsen som i sin tur styr LCD-displayen. När processorn startar efter reset hoppar den till `reset`-labeln, initierar VIA:ns portar som utgångar, skickar en standardsekvens av kommandon för att väcka LCD:n i 8-bitarsläge, och går sedan in i huvudloopen `hello`. Där skrivs två rader text ut — "=== 6502 VIA LCD ===" och "Hello from W65C02!" — displayen rensas, och allt börjar om. En oändlig loop av text, rensa, text, rensa.

Programmet är uppbyggt i lager. Överst definieras fyra konstanter — `VIA_ORB`, `VIA_ORA`, `VIA_DDRB` och `VIA_DDRA` — som ger mänskliga namn åt VIA-kretsens registeradresser. Sedan följer själva koden i segmentet `CODE` som placeras från adress `$8000`. Där finns `reset` (startpunkten), `hello` (huvudloopen), och två subrutiner: `lcd_command` och `lcd_data`. Efter koden ligger strängdatan — två rader text, var och en avslutad med en nolla som signalerar att strängen är slut. Sist kommer vektorsegmentet där `.word reset` på adress `$FFFC` talar om för processorn var programmet börjar.

De två subrutinerna är programmets verkliga arbetshästar. `lcd_command` skickar ett kommando till LCD:n: den lägger kommandobyten på PORTB, sätter `RS`=0 och `E`=1, och drar sedan `E` till 0 — den fallande flanken får LCD:n att läsa. `lcd_data` gör exakt samma sak, men med `RS`=1 för att signalera att byten är ett tecken, inte ett kommando. Båda anropas med `JSR` (Jump to Subroutine) och återvänder med `RTS` — 6502:ans motsvarighet till funktionsanrop. Strängarna skrivs ut tecken för tecken i en loop: X-registret räknar genom strängen, `LDA line1,x` hämtar nästa tecken, och när en nolla dyker upp vet programmet att strängen är slut.

Det fina med att ha programmet i en separat `.asm`-fil är att jag kan ändra och experimentera utan att röra Arduino-koden. Jag byter ut texten i `line1` mot mitt eget namn, kör `pio run -e step8 -t upload`, och inom sekunder visar LCD:n min nya text. Assemblerkoden är kommenterad på svenska så att varje instruktion förklarar sig själv — jag läser den som en receptbok, rad för rad, så förstår jag exakt vad processorn gör i varje ögonblick.

??? note "📦 6502-programmet — program_hello.asm"

    ```asm
    --8<-- "Mega_2560_6502/asm/program_hello.asm"
    ```

Komplett assembler-kod: `Mega_2560_6502/asm/program_hello.asm`.

## Arduino-kod

Steg 7:s största svaghet var att 6502-programmet byggdes som hundratals `write_mem()`-anrop i C++-koden. Det fungerar — men det är plågsamt att redigera, svårt att läsa, och omöjligt att felsöka. Steg 8 löser detta med en *professionell assembler-kedja*: jag skriver läsbar 6502-kod i en `.asm`-fil, och PlatformIO bygger om den automatiskt vid varje uppladdning.

### Från assembler till header — byggkedjan i detalj

När jag kör `pio run` händer tre saker innan C++-koden kompileras:

1. ca65 — assemblerar `program_hello.asm` till en objektfil (`.o`). Översätter mnemonics som `LDA #$FF` till maskinkod (`A9 FF`) och löser lokala labels.
1. ld65 — länkaren placerar koden på rätt adresser enligt `program.cfg`. Koden läggs på `$8000`, vektorerna på `$FFFA`. Resultatet är en binärfil på exakt 2054 bytes (2048 kod + 6 vektorer).
1. bin2h.py — konverterar binärfilen till en C-header med en `PROGMEM`-array. Arduinons flash-minne är begränsat — `PROGMEM` gör att programmet ligger kvar i flash och inte kopieras till RAM.

Hela kedjan styrs av `scripts/build_asm.py`, en pre-build hook som PlatformIO anropar automatiskt. Ändrar jag `.asm`-filen byggs allt om.

### Arduino-koden — bara `setup()` ändras

`pulse()`, `loop()` och hela minnesemulatorn är oförändrade från steg 7. Skillnaden sitter i `setup()`: istället för hundratals `write_mem()` loopar jag nu igenom `PROGRAM[]` och kopierar:

- Kod: `PROGRAM_SIZE - 6` bytes kopieras till `$8000` och uppåt. `pgm_read_byte()` läser från PROGMEM (flash).
- Vektorer: de sista 6 byten kopieras till `$FFFA`–`$FFFF`. Där finns reset-vektorn som talar om att programmet börjar på `$8000`.

### 6502-programmet — läsbar assembler

`program_hello.asm` är samma 2-radersprogram som steg 7, men nu med labels (`reset:`, `hello:`), subrutiner (`lcd_command:`, `lcd_data:`), och nollterminerade strängar (`.byte "...", 0`). `JSR` (Jump to Subroutine) och `RTS` (Return from Subroutine) använder stacken för att hålla reda på återhoppsadressen — precis som funktionsanrop i högnivåspråk.

### Vad som är nytt jämfört med steg 7

Ingen ny hårdvara. I koden: `#include "program_hello.h"`, `PROGRAM[]`, `PROGRAM_SIZE`, och `pgm_read_byte()`. I byggkedjan: `ca65`, `ld65`, `bin2h.py`, `build_asm.py`. Det här är samma verktyg som användes för att bygga spel till NES och program till Apple II — professionella verktyg för en hobbyprocessor.

??? note "📦 Arduino-kod"

    ```cpp
    --8<-- "Mega_2560_6502/src/step1.inc"
    ```

## Minneskarta

**6502**-processorn har 16 adresslinjer = 64 KB adressrymd. Arduinon svarar på adresser där den har data, och tri-statar vid **VIA**-adresser så den fysiska kretsen kan svara.

<div class="memmap">

      <div style="min-height:8px;display:flex;align-items:stretch;border-bottom:1px solid #e5e7eb">
        <div style="min-height:8px;width:5rem;padding-right:.75rem;display:flex;flex-direction:column;justify-content:space-between;text-align:right">
          <span style="color:#6b7280">$FFFF</span>
          <span style="color:#6b7280">$FFFA</small>
        </div>
        <div style="min-height:8px;flex:1 1 0%;background-color:#f3e8ff;border-left:1px solid #c4b5fd;border-right:1px solid #c4b5fd;padding-left:.5rem;padding-right:.5rem;display:flex;align-items:center">vectors[6] — NMI, RESET, IRQ</div>
        <div style="width:3.5rem;text-align:right;color:#6b7280;padding-right:.5rem">6 B</div>
      </div>
      <div style="height:200px;display:flex;align-items:stretch;border-bottom:1px solid #e5e7eb">
        <div style="width:5rem;text-align:right;padding-right:.75rem;color:#9ca3af;align-self:flex-start;padding-top:.25rem">$FFF9</div>
        <div style="flex:1 1 0%;background-color:#f3f4f6;padding-left:.5rem;padding-right:.5rem;display:flex;align-items:center;color:#9ca3af">oanvänt (returnerar $EA = NOP)</div>
        <div style="width:3.5rem;text-align:right;color:#9ca3af;padding-right:.5rem;align-self:flex-start;padding-top:.25rem">~30 KB</div>
      </div>
      <div style="min-height:16px;display:flex;align-items:stretch;border-bottom:1px solid #e5e7eb">
        <div style="min-height:16px;width:5rem;padding-right:.75rem;display:flex;flex-direction:column;justify-content:space-between;text-align:right">
          <span style="color:#6b7280">$8800</span>
          <span style="color:#6b7280">$8000</span>
        </div>
        <div style="flex:1 1 0%;background-color:#dbeafe;border-left:1px solid #93c5fd;border-right:1px solid #93c5fd;padding-left:.5rem;padding-right:.5rem;display:flex;align-items:center">program[2048] — 6502-program</div>
        <div style="width:3.5rem;text-align:right;color:#6b7280;padding-right:.5rem">2 KB</div>
      </div>
      <div style="height:100px;display:flex;align-items:stretch;border-bottom:1px solid #e5e7eb">
        <div style="width:5rem;text-align:right;padding-right:.75rem;color:#9ca3af;align-self:flex-start;padding-top:.25rem">$7FFF</div>
        <div style="flex:1 1 0%;background-color:#f3f4f6;padding-left:.5rem;padding-right:.5rem;display:flex;align-items:center;color:#9ca3af">oanvänt</div>
        <div style="width:3.5rem;text-align:right;color:#9ca3af;padding-right:.5rem;align-self:flex-start;padding-top:.25rem">~16 KB</div>
      </div>
      <div style="min-height:8px;display:flex;align-items:stretch;border-bottom:2px solid #d1d5db;border-bottom:2px solid #eab308">
        <div style="min-height:8px;width:5rem;padding-right:.75rem;display:flex;flex-direction:column;justify-content:space-between;text-align:right">
          <span style="color:#6b7280">$4010</span>
          <span style="color:#6b7280">$4000</span>
        </div>
        <div style="min-height:8px;flex:1 1 0%;background-color:#fef9c3;border-left:1px solid #facc15;border-right:1px solid #facc15;padding-left:.5rem;padding-right:.5rem;display:flex;align-items:center;font-weight:700">W65C22 VIA (fysisk krets)</div>
        <div style="width:3.5rem;text-align:right;color:#6b7280;padding-right:.5rem">16 B</div>
      </div>
      <div style="height:100px;display:flex;align-items:stretch;border-bottom:1px solid #e5e7eb">
        <div style="width:5rem;text-align:right;padding-right:.75rem;color:#9ca3af;align-self:flex-start;padding-top:.25rem">$3FFF</div>
        <div style="flex:1 1 0%;background-color:#f3f4f6;padding-left:.5rem;padding-right:.5rem;display:flex;align-items:center;color:#9ca3af">oanvänt</div>
        <div style="width:3.5rem;text-align:right;color:#9ca3af;padding-right:.5rem;align-self:flex-start;padding-top:.25rem">~15 KB</div>
      </div>
      <div style="min-height:8px;display:flex;align-items:stretch;border-bottom:1px solid #e5e7eb">
        <div style="min-height:8px;width:5rem;padding-right:.75rem;display:flex;flex-direction:column;justify-content:space-between;text-align:right">
          <span style="color:#6b7280">$0400</span>
          <span style="color:#6b7280">$0200</span>
        </div>
        <div style="min-height:8px;flex:1 1 0%;background-color:#dcfce7;padding-left:.5rem;padding-right:.5rem;display:flex;align-items:center">ram[1024] — ledigt RAM</div>
        <div style="width:3.5rem;text-align:right;color:#6b7280;padding-right:.5rem">512 B</div>
      </div>
      <div style="min-height:8px;display:flex;align-items:stretch;border-bottom:1px solid #e5e7eb">
        <div style="min-height:8px;width:5rem;padding-right:.75rem;display:flex;flex-direction:column;justify-content:space-between;text-align:right">
          <span style="color:#6b7280">$0200</span>
          <span style="color:#6b7280">$0100</span>
        </div>
        <div style="min-height:8px;flex:1 1 0%;padding-left:.5rem;padding-right:.5rem;display:flex;align-items:center">Stack (JSR/RTS, PHA/PLA)</div>
        <div style="width:3.5rem;text-align:right;color:#6b7280;padding-right:.5rem">256 B</div>
      </div>
      <div style="min-height:8px;display:flex;align-items:stretch">
        <div style="min-height:8px;width:5rem;padding-right:.75rem;display:flex;flex-direction:column;justify-content:space-between;text-align:right">
          <span style="color:#6b7280">$0100</span>
          <span style="color:#6b7280">$0000</span>
        </div>
        <div style="min-height:8px;flex:1 1 0%;padding-left:.5rem;padding-right:.5rem;display:flex;align-items:center">Zero page (snabbast)</div>
        <div style="width:3.5rem;text-align:right;color:#6b7280;padding-right:.5rem">256 B</div>
      </div>
    
</div>

## Exempel på körning

När jag bygger och laddar upp ser jag byggkedjan arbeta i terminalen:

``` title="Terminal"
pio run -e step8 -t upload -t monitor
```

``` title="Terminal"
[build_asm] Assemblerar .../asm/program_hello.asm …
[build_asm] OK — 2054 bytes → .../program_hello.h
Processing step8 (platform: ...)
...
Steg 8 — assembler-bygge med ca65
Programstorlek: 2054 bytes
Program + vektorer laddat.
```

=== "Terminal"

    ```text
    W $4002  ← VIA: FF  (DDRB)
    W $4003  ← VIA: FF  (DDRA)
    ...
    W $4000  ← VIA: 3D  (=)
    W $4000  ← VIA: 3D  (=)
    ...
    ```

=== "LCD 16×2"

    ```text
    === 6502 VIA LCD ===
    Hello from W65C02!
    ```

Seriemonitor visar samma VIA- och LCD-aktivitet som i steg 7 — men med en avgörande skillnad: jag har inte skrivit en enda `write_mem()`. Programmet kommer från `program_hello.asm`, en ren assembler-fil med labels, subrutiner och kommentarer.

Jag gör ett test: jag ändrar texten i `line1:` från "=== 6502 VIA LCD ===" till "Hej varlden!" och kör `pio run -e step8 -t upload -t monitor` igen. Hela kedjan körs om — ca65, ld65, bin2h, kompilering, uppladdning — och LCD:n visar min nya text. Iterationstiden är sekunder, inte minuter. Första gången kedjan rullade ihop på egen hand kändes det som att få en assistent.

## Så här felsöker man

Här är några saker jag kontrollerar:

``` title="Terminal"
sudo apt install cc65
```

- ca65: command not found? Då installerar jag cc65:

``` title="Terminal"
pio run -e step8
```

- "No such file: program.h"? Då måste första bygget generera den. Jag kör två gånger om det krävs.
- Gör CPU:n inget? Då kontrollerar jag att `write_mem()`-loopen faktiskt kopierar `PROGRAM[]` till `program[]`. Jag loggar med `Serial.print()`.

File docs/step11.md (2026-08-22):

# Städad adressrymd

En dator som fungerar men har en stökig adressrymd stör mig. Nu ska hela 64 KB falla på plats — RAM nedtill, I/O i mitten, ROM upptill.

## Mål

I steg 10 fick jag en fristående dator — men adressrymden var inte vacker. VIA:ns 16 bytes på `$4000` klippte av SRAM-minnet mitt i, och den övre halvan av 62256-chippet (`$4000`–`$7FFF`) låg helt oanvänd. Det kändes slarvigt.

Nu städar jag upp. SRAM utökas till hela 32 KB (`$0000`–`$7FFF`) genom att ansluta `A14` — hela 62256-chippet används äntligen. VIA:n flyttas till `$8000`–`$BFFF`, ett 16 KB-stort I/O-fönster i mitten av adressrymden, precis som I/O-portar sitter på riktiga 6502-datorer (Apple II hade I/O på `$C000`, C64 på `$D000`).

Resultatet är en adressrymd utan dött utrymme: RAM längst ner, ROM i mitten och I/O i ett fönster högst upp. Det här är den klassiska 6502-layouten — nu har jag byggt den själv. Fyra kablar och en NAND-grind — och hela 64 KB har fått ett jobb.

Samma väg som *Steve Wozniak* använde i Apple II och som *Ben Eater* visade i sin klassiska 6502-serie.

## Nya komponenter

Inga nya kretsar! Det här steget handlar om att *omkoppla det jag redan har*. Jag behöver bara en enda NAND-grind (¼ av en 74HC00) för hela den nya adressavkodningen. Dessutom en extra kopplingstråd för SRAM:ns `A14` och en för EEPROM:ets `A14`.

| Antal | Komponent | Används till |
|---|---|---|
| 1 | 74HC00 (en grind, ¼ av chippet) | EEPROM /CE = NAND(A15, A14) |
| 1 | Kopplingstråd | SRAM A14 (pin 1) → CPU A14 — öppnar den andra halvan av 62256 |
| — | Kopplingstrådar (omkoppling) | Flytta VIA:ns /CS2 och EEPROM:ets /CE till nya avkodningssignaler |

## Kopplingsschema

Schemat visar den städade bussen: SRAM tar nedre halvan, VIA mitten och EEPROM toppen — varje enhet på sin egen tydliga region.

Schema kommer snart — se avkodningstabellerna nedan så länge.

## Adressavkodning

Allt handlar om vilken enhet som får prata på bussen. Tre enheter, tre chip select-signaler — och en enda NAND-grind räcker.

??? note "Gamla kartan (steg 10) — problemen"

    ✗ SRAM bara 16 KB: 62256 är ett 32 KB-chip, men `A14` var inte ansluten. Den övre halvan låg död.

    ✗ VIA klippte av minnet: 16 bytes på `$4000` mitt i adressrymden delade RAM:et i två — `$0000`–`$3FFF` använt, `$4000`–`$7FFF` dött.

    ✗ EEPROM-avkodning enkel: bara NOT `A15` — fungerade, men kunde inte samexistera med VIA på samma sida.

??? note "Nya kartan (steg 11)"

    ✓ SRAM 32 KB (`$0000`–`$7FFF`): `A14` ansluts, `/CE` = `A15` direkt (aktivt låg) — hela chippet aktivt när `A15`=0.

    ✓ VIA på `$8000`–`$BFFF`: `A15` → `CS1` (aktivt hög), `A14` → `/CS2` (aktivt låg) — *inga grindar alls*, kretsens egna chip-selects gör jobbet.

    ✓ EEPROM på `$C000`–`$FFFF`: `/CE` = NAND(`A15`, `A14`) — en enda grind, och `A14` kopplas även till EEPROM:ets `A14` så chippet läser sin övre halva.

### Sanningstabell — vem svarar på vilken adress?

Varje enhet har en egen region — inga fönster, inga speglingar mellan enheter. Adressavkodningen är bara fyra kablar och en NAND-grind.

| Adressintervall | A15 | A14 | SRAM /CE | VIA CS1·/CS2 | EEPROM /CE | Vem svarar |
|---|---|---|---|---|---|---|
| $0000–$7FFF | 0 | – | LÅG ✓ | – | HÖG | SRAM |
| $8000–$BFFF | 1 | 0 | HÖG | AKTIV ✓ | HÖG | VIA |
| $C000–$FFFF | 1 | 1 | HÖG | – | LÅG ✓ | EEPROM |
| VIA: CS1 = A15 (aktivt hög) och /CS2 = A14 (aktivt låg) — aktiveras när A15=1 och A14=0. A0–A3 går till RS0–RS3 och väljer register; de speglas var 16:e byte i fönstret. EEPROM: A14 kopplas också till chippets A14 så det läser övre halvan. |  |  |  |  |  |  |

## Kopplingar

Här är vad som ändras jämfört med steg 10. Allt annat — ström, klocka, reset, adress-/databuss till SRAM och EEPROM — är oförändrat.

### SRAM — nu med `A14`

| Pin | Signal | Kopplas till | Varför |
|---|---|---|---|
| 1 | `A14` | CPU A14 (NY!) | Öppnar den andra halvan av 62256 — SRAM blir 32 KB |
| 20 | `/CE` | CPU `A15` direkt (aktivt låg) | LÅG när A15=0 — hela nedre halvan, ingen grind behövs |

### VIA — flyttad till `$8000`

| Pin | Signal | Kopplas till | Varför |
|---|---|---|---|
| 23 | `/CS2` | CPU `A14` direkt (aktivt låg) | LÅG när A14=0 → VIA vid $8000–$BFFF |
| 24 | `CS1` | CPU `A15` direkt (aktivt hög) | HÖG när A15=1 → övre halvan |
| 38–35 | `RS0–RS3` | CPU A0–A3 (oförändrad) | Väljer register — de speglas var 16:e byte i fönstret |

### EEPROM — övre halvan (`$C000`–`$FFFF`)

| Pin | Signal | Kopplas till | Varför |
|---|---|---|---|
| 20 | `/CE` | NAND-grindens utgång (74HC00 pin 3) | LÅG när A15=1 och A14=1 → $C000–$FFFF |
| 1 | `A14` | CPU `A14` | EEPROM läser sin övre halva — $C000–$FFFF |

### Adressavkodning — en enda NAND-grind

Här är tricket: kretsarnas egna chip-select-pinnar gör avkodningen. SRAM:s `/CE` är aktivt låg, och VIA:n har *två* chip-selects med motsatt polaritet — `CS1` (pin 24, aktivt hög) och `/CS2` (pin 23, aktivt låg). Då matchar adressbitarna kretsarna direkt, och bara EEPROM:s `/CE` behöver en NAND-grind. Aktiveringslogiken finns i sanningstabellen i Adressavkodning-sektionen ovan, och de fyra direktanslutningarna — SRAM `/CE`, VIA `CS1`/`/CS2` och EEPROM `A14` — står i kretstabellerna ovan. Här visas bara NAND-grinden. 

??? note "📦 Kopplingar — 74HC00 NAND-grind"

    | Pin | Signal | Kopplas till | Varför |
    |---|---|---|---|
    | 74HC00 — endast en NAND-grind |  |  |  |
    | 1, 2 | `A15`, `A14` (in) | CPU `A15`, CPU `A14` | NAND(`A15`, `A14`) — HÖG när någon är 0 |
    | 3 | EEPROM `/CE` (ut) | AT28C256 pin 20 | LÅG när A15=1 och A14=1 → $C000–$FFFF |
    | 14, 7 | VCC, GND | +5V, GND | Strömmatning |

## Minneskarta

Nu används hela 64 KB, varje enhet på sin egen tydliga region: **SRAM** nedtill, **VIA** i mitten, **EEPROM** upptill.

<div class="memmap">

        <div style="height:100px;display:flex;align-items:stretch;border-bottom:2px solid #d1d5db;border-bottom:2px solid #a855f7">
          <div style="min-height:8px;width:5rem;padding-right:.75rem;display:flex;flex-direction:column;justify-content:space-between;text-align:right">
            <span style="color:#6b7280">$FFFF</span>
            <span style="color:#6b7280">$C000</span>
          </div>
          <div style="flex:1 1 0%;background-color:#f3e8ff;border-left:1px solid #a78bfa;border-right:1px solid #a78bfa;padding-left:.5rem;padding-right:.5rem;display:flex;align-items:center">AT28C256 EEPROM — program + vektorer</div>
          <div style="width:3.5rem;text-align:right;color:#6b7280;padding-right:.5rem">16 KB</div>
        </div>
        <div style="height:100px;display:flex;align-items:stretch;border-bottom:2px solid #d1d5db;border-bottom:2px solid #eab308">
          <div style="min-height:16px;width:5rem;padding-right:.75rem;display:flex;flex-direction:column;justify-content:space-between;text-align:right">
            <span style="color:#6b7280">$BFFF</span>
            <span style="color:#6b7280">$8000</span>
          </div>
          <div style="flex:1 1 0%;background-color:#fef9c3;border-left:1px solid #facc15;border-right:1px solid #facc15;padding-left:.5rem;padding-right:.5rem;display:flex;align-items:center;font-weight:700">W65C22 VIA — I/O-fönster</div>
          <div style="width:3.5rem;text-align:right;color:#6b7280;padding-right:.5rem">16 KB</div>
        </div>
        <div style="height:200px;display:flex;align-items:stretch;border-bottom:2px solid #d1d5db;border-bottom:2px solid #22c55e">
          <div style="min-height:8px;width:5rem;padding-right:.75rem;display:flex;flex-direction:column;justify-content:space-between;text-align:right">
            <span style="color:#6b7280">$7FFF</span>
            <span style="color:#6b7280">$0000</span>
          </div>
          <div style="flex:1 1 0%;background-color:#dcfce7;border-left:1px solid #4ade80;border-right:1px solid #4ade80;padding-left:.5rem;padding-right:.5rem;display:flex;align-items:center;font-weight:700">62256 SRAM — 32 KB (hela chippet)</div>
          <div style="width:3.5rem;text-align:right;color:#6b7280;padding-right:.5rem">32 KB</div>
        </div>
      
</div>

## Arduino-kod

Ändringarna i Arduinon är minimala — bara tre konstanter och en villkorsändring i `is_eeprom()`. Koden vet nu att SRAM täcker `$0000`–`$7FFF`, VIA bor på `$8000` och EEPROM på `$C000`. Allt annat är tri-state för fysiska kretsar.

??? note "📦 Arduino-kod"

    ```cpp
    --8<-- "Mega_2560_6502/src/step1.inc"
    ```

## Länkskript — program.cfg

I steg 8 skapade jag `program.cfg` — länkaren ld65:s karta över minnet. Den talar om var i adressrymden koden hamnar. Nu uppdateras den: ROM:en ligger nu rent på `$C000`–`$FFFF` (16 KB) — inga fönster eller gap längre.

### Så här gör jag

1. Jag öppnar `asm/program.cfg` i mitt PlatformIO-projekt — samma fil som skapades i steg 8.
1. Jag ersätter innehållet med koden nedan och sparar.
1. Jag bygger projektet — `build_asm.py` skickar filen till ld65 automatiskt (`-C program.cfg`). Inget att köra manuellt.
1. Assembler-filen behöver inga ändringar — segmenten nedan matchar den.

??? note "📦 Länkskript"

    ```cfg
    --8<-- "Mega_2560_6502/asm/program.cfg"
    ```

Koden läggs i `$C000`–`$FFFF` (ROM, 16 KB). Reset-vektorn ligger som alltid på `$FFFA`–`$FFFF`.

## Exempel på körning

När jag laddat upp koden och startat datorn ser jag i seriemonitorn att enheterna svarar på sina nya adresser:

=== "Terminal"

    ```text
    Steg 11 — städad adressrymd
    SRAM 32 KB ($0000-$7FFF), VIA ($8000), EEPROM ($C000+)
    CPU startad.

    R $FFFC  ← RESET-VEKTOR LÅG (EEPROM)
    R $FFFD  ← RESET-VEKTOR HÖG (EEPROM)
    R $C000  ← EEPROM
    R $C001  ← EEPROM
    W $0200  ← SRAM            (variabel skrivning)
    W $8000  ← VIA: 01         (LCD-kommando via VIA)
    W $8001  ← VIA: 05         (registerval)
    ...
    W $8000  ← VIA: 3D         (tecknet "=")
    ...
    ```

=== "LCD 16×2"

    ```text
    === 6502 VIA LCD ===
    Hello from W65C02!
    ```

Samma program som steg 8–10, men VIA:n adresseras nu på `$8000` istället för `$4000`.

Lägg märke till skillnaden mot steg 10: SRAM-skrivningar kan nu ske var som helst i `$0000`–`$7FFF`, VIA:n svarar på `$8000` och EEPROM på `$C000`. Bussloggen visar tydligt vilken enhet som pratar.

## Så här felsöker man

Här är några saker jag kontrollerar:

- Läser CPU:n `$FFFC`/`$FFFD` men hoppar till fel adress? Då är EEPROM:ets `/CE` förmodligen inte rätt avkodat. Jag kontrollerar NAND-grinden (74HC00 pin 3) — den måste ge LÅG när `A15`=1 och `A14`=1.
- Svarar VIA:n inte på `$8000`? Då kontrollerar jag `CS1` (pin 24) = `A15` (hög) och `/CS2` (pin 23) = `A14` (låg) — VIA:n kräver båda samtidigt. Jag dubbelkollar att `RS0–RS3` fortfarande går till `A0–A3`.
- Är SRAM fortfarande bara 16 KB? Då är `A14` (SRAM pin 1) inte ansluten. Utan den kan processorn inte nå `$4000`–`$7FFF`.
- Busskrockar? Då kan två enheter svara samtidigt om avkodningen är fel. Jag mäter `/CE` och `/CS2` medan CPU:n läser — exakt en ska vara LÅG.
- Kraschar programmet vid `$8000`? Då placerade länkskriptet kod i VIA-fönstret. Jag kontrollerar `program.cfg` — ROM ska börja på `$C000`, inte tidigare.

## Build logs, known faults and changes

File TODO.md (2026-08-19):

# TODO — Kommande korrigeringar

## Hårdvara / KiCad
- [ ] Koppla BE (CPU pin 36) till +5V via 10 kΩ i KiCad för alla steg — HÖG = bussar aktiva enligt databladet. Koppla INTE till GND.
- [ ] Kontrollera VIA CS1 (pin 24) — ska vara +5V (aktiv HÖG). Koppla inte till GND.
- [ ] Exportera nya netlister för alla steg
- [ ] Generera nya PNG:er

## Dokumentation
- [ ] Kopiera nya PNG:er till `schematics/`
- [ ] Uppdatera step1–11.html med korrigerade scheman
- [ ] Steg 11: fyll i kopplingsschema (placeholder finns kvar i step11.html)

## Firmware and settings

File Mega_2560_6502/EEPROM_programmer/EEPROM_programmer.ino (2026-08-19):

// ==============================================================
// Steg 10 — EEPROM-programmerare (andra Arduino Mega)
// ==============================================================
// Tar emot en .bin-fil över serieporten, bränner den på
// AT28C256, och verifierar. Körs EN gång i setup().
//
// Använd med: python3 scripts/upload_eeprom.py asm/program_hello.bin /dev/ttyACM0
// Detta är en separat Arduino — INTE samma som datorns klocka/diagnostik.

#include <Arduino.h>

// --- Pindefinitioner ---
#define WE 2       // Arduino D2 → AT28C256 /WE (pin 27)
#define OE 3       // Arduino D3 → AT28C256 /OE (pin 22)

#define EEPROM_SIZE 32768  // 32 KB = 32 768 bytes

// --- Buffert för mottagen data ---
// Arduino Mega har 8 KB SRAM — för lite för hela 32 KB.
// Vi använder därför ett sid-indelat protokoll: 256 bytes åt gången.
uint8_t page[256];       // 256-byte sida
int pages_total = 0;     // Räkna antal mottagna sidor

// --- read_eeprom() — läs en byte från EEPROM ---
uint8_t read_eeprom(uint16_t addr) {
  // Sätt adress
  PORTF = addr & 0xFF;         // A0–A7  (PORTF = Arduino A0–A7)
  PORTK = (addr >> 8) & 0x7F;  // A8–A14 (PORTK = Arduino A8–A14, bit 7 oanvänd)

  DDRA = 0x00;                  // PORTA = INPUT (tri-state)
  digitalWrite(OE, LOW);        // /OE låg → EEPROM kör ut data
  delayMicroseconds(1);         // Vänta på utgångsdata
  uint8_t data = PINA;          // Läs D0–D7
  digitalWrite(OE, HIGH);       // /OE hög → EEPROM tri-state
  return data;
}

// --- write_eeprom() — bränn en byte till EEPROM ---
// AT28C256 har inbyggd timing — vi behöver bara hålla /WE
// låg i minst 10 ms så sköter kretsen resten.
void write_eeprom(uint16_t addr, uint8_t data) {
  // Sätt adress
  PORTF = addr & 0xFF;
  PORTK = (addr >> 8) & 0x7F;

  // Sätt data
  DDRA = 0xFF;                  // PORTA = OUTPUT
  PORTA = data;                 // Lägg ut data på D0–D7
  digitalWrite(OE, HIGH);       // /OE hög — vi ska inte läsa nu

  // Bränn: puls /WE låg i 10 ms
  digitalWrite(WE, LOW);
  delay(10);                    // 10 ms — gott om marginal
  digitalWrite(WE, HIGH);

  DDRA = 0x00;                  // Tri-state databussen
}

// --- setup() — ta emot data, bränn, verifiera ---
void setup() {
  Serial.begin(115200);
  pinMode(WE, OUTPUT);  digitalWrite(WE, HIGH);
  pinMode(OE, OUTPUT);  digitalWrite(OE, HIGH);
  DDRF = 0xFF;   // Adress A0–A7 = OUTPUT
  DDRK = 0xFF;   // Adress A8–A14 = OUTPUT
  DDRA = 0x00;   // Data = INPUT (tri-state från start)

  Serial.println("AT28C256 EEPROM-programmerare");
  Serial.println("Redo att ta emot .bin-fil...");
  Serial.println("Skicka data med: python3 scripts/upload_eeprom.py program.bin");

  // --- Ta emot data sida för sida ---
  // Protokoll: 256 bytes per sida. Efter sista sidan: "DONE".
  uint16_t total_addr = 0;
  pages_total = 0;

  while (true) {
    // Vänta på startsignal från Python-skriptet
    while (Serial.available() < 1);
    char cmd = Serial.read();

    if (cmd == 'P') {
      // "PAGE" — nästa 256 bytes är en sida
      pages_total++;
      int bytes_read = Serial.readBytes((char*)page, 256);
      if (bytes_read != 256) {
        Serial.print("FEL: endast ");
        Serial.print(bytes_read);
        Serial.println(" bytes mottagna (väntade 256)");
        return;
      }

      // Bränn sidan
      Serial.print("Bränner sida ");
      Serial.print(pages_total);
      Serial.print(" (adress $");
      Serial.print(total_addr, HEX);
      Serial.print(")... ");

      for (int i = 0; i < 256; i++) {
        write_eeprom(total_addr + i, page[i]);
      }
      Serial.println("OK");
      total_addr += 256;
    }
    else if (cmd == 'D') {
      // "DONE" — alla sidor mottagna
      Serial.println("Alla sidor mottagna.");
      break;
    }
    else {
      Serial.print("Okänt kommando: ");
      Serial.println(cmd);
    }
  }

  // --- Verifiera ---
  Serial.println("Verifierar...");
  int errors = 0;
  for (uint32_t addr = 0; addr < total_addr; addr++) {
    // Vi har inte kvar originaldatan i RAM på ett enkelt sätt
    // efter sidbränningen. I praktiken: använd ett Python-skript
    // som skickar om datan för verifiering, eller lagra checksummor.
    //
    // Här visar vi principen: läs tillbaka och låt Python-skriptet
    // jämföra.
    uint8_t val = read_eeprom(addr);
    Serial.print("V ");
    Serial.print(addr, HEX);
    Serial.print(" ");
    Serial.println(val, HEX);
  }

  Serial.println("KLAR");
  Serial.print("Totalt brända bytes: ");
  Serial.println(total_addr);
}

void loop() {
  // Tom — allt sker i setup()
}

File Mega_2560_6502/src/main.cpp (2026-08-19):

// W65C02 8-bitarsdator — dispatcher
// Välj steg via platformio.ini build_flags: env:step1 … env:step11
// Default (inget definierat) = steg 9

#if defined(STEP1)
  #include "step1.inc"
#elif defined(STEP2)
  #include "step2.inc"
#elif defined(STEP3)
  #include "step3.inc"
#elif defined(STEP4)
  #include "step4.inc"
#elif defined(STEP5)
  #include "step5.inc"
#elif defined(STEP6)
  #include "step6.inc"
#elif defined(STEP7)
  #include "step7.inc"
#elif defined(STEP8)
  #include "step8.inc"
#elif defined(STEP9)
  #include "step9.inc"
#elif defined(STEP10)
  #include "step10.inc"
#elif defined(STEP11)
  #include "step11.inc"
#else
  #include "step9.inc"
#endif

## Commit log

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2026-07-20 Regenerate step schematics: both ICs shown in all steps, only connections vary
2026-07-20 Fix R6+LED1 routing: now left of CPU, not over Arduino
2026-07-20 Fix R6+LED1: UP above CPU, then LEFT
2026-07-20 R6+LED1: revert to proven pattern — left from D4_RST height
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2026-07-20 Split step 4+5: buttons then LCD. Remove Schema from nav. Add step5.
2026-07-21 Lägg till kommentarer och förklaringar i Arduino-koden för steg 1–5, samt W65C02S-dokumentation
2026-07-26 Korrigera mem[65536] → read_mem/write_mem, ta bort databuss-LED-referenser
2026-07-27 W65C02S: Steg 3+4 - Fullt fungerande CPU, LCD, knappar
    - Kompileringsfixar: forward declaration, baud rate
    - BE (pin 36) -> GND (aktiv lÃ¥g, schemat var fel)
    - Breadboard-kortis: flyttade CPU till ny plats
    - StrÃ¶m: bytt USB-kabel -> 12V/18V-adapter
    - Databuss: PORTA D22-D29 med 100Î© skydd
    - Adressbuss: 1:1-koppling, rÃ¤tt byteordning (PINF/PINK)
    - Separat vectors[6] fÃ¶r - (ram[512] rÃ¤cker ej)
    - 20 Hz klocka + LED pÃ¥ D2
    - LCD QC1602A: parallell 4-bit, omvÃ¤nd datapinneordning
    - Steg 4: Knappar pÃ¥ D11/D12, SYNC pÃ¥ D13
    - Program: LDA/INA/STA/JMP som rÃ¤knar A-registret
    - LCD visar A-register frÃ¥n i realtid
    - README.md: korrigerat BE, adressbuss 1:1, LCD parallel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
    [main.cpp]
2026-07-27 Korrigera scheman: BE→GND, adressbuss 1:1, LED på PHI2, SYNC D13, knappar D11/D12, pull-ups 10k, komponenttabeller uppdaterade
2026-08-04 Steg 7: W65C22 VIA + 74HC00 + LCD, KiCad-schema, schemdraw borttaget
    [6502.smutje.se.kicad_pcb, 6502.smutje.se.kicad_sch]
2026-08-04 Steg 6 & 7: KiCad-scheman uppdaterade, HTML-sidor fixade, main.cpp för VIA+LCD
    [6502.smutje.se.kicad_pcb, 6502.smutje.se.kicad_sch]
2026-08-04 Korrigera BE: +5V (aktiv hög), inte GND
2026-08-04 Uppdatera steg-6 och steg-7 PNG:er med BE→+5V
    [6502.smutje.se.kicad_sch]
2026-08-04 Steg 6 & 7: knappar + SYNC tillagda, nya PNG:er
    [6502.smutje.se.kicad_sch]
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2026-08-04 Steg 7: ta bort upprepningar, fixa LCD R/W→GND, slå ihop test+diagnostik
2026-08-04 README: fixa adressrymdslayout, 74HC00 pin 6→/CS2, komponentlista
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2026-08-04 Uppdatera main.cpp för att förbättra LCD-styrning och debug-logik; justera README.md för att inkludera 20×4 LCD och korrigera BE-signalkoppling; revidera TODO.md för att specificera netlist-ändringar.
    [main.cpp]
2026-08-05 Kicad projekt ligger här nu, med alla steg
    [6502.smutje.se.kicad_pcb, 6502.smutje.se.kicad_sch, steg_2.kicad_sch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]
2026-08-05 Uppdaterat med bättre dumpar
    [steg_7.kicad_sch]
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2026-08-05 Steg 7: fixa →0, 74HC00 pin 8→6, maskinkodstabell = main.cpp
2026-08-05 Steg 8: Assembler-bygge med ca65 — program.asm, bin2h.py, build_asm.py, step8.inc, step8.html
    [program.cfg]
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2026-08-05 index: samma stil som steg-sidor — text direkt i sektioner, inga kort-wrappers
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2026-08-06 Fetstil på kretsnamn i kopplingstabeller: Arduino D2, +5V, PORTF, LCD 1 osv
2026-08-06 Add trim potentiometer symbol and update power symbols in schematics
    - Introduced a new trim potentiometer symbol (Device:R_Potentiometer_Trim) with properties for reference, value, footprint, and simulation details.
    - Updated existing power symbols for +5V and Earth, including new references and descriptions.
    - Adjusted positions and properties of various components in the schematic to enhance clarity and organization.
    - Updated multiple schematic images to reflect the latest changes.
    [6502.smutje.se.kicad_sch, steg_2.kicad_sch, steg_3.kicad_sch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]
2026-08-06 Revert "Add trim potentiometer symbol and update power symbols in schematics"
    This reverts commit c4bb345892a428583a00d61d4c040ffcc3a1eb40.
    [6502.smutje.se.kicad_sch, steg_2.kicad_sch, steg_3.kicad_sch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]
2026-08-06 Revert "Revert "Add trim potentiometer symbol and update power symbols in schematics""
    This reverts commit 8fd96efb5274e10621895305847faa9d6d6df2a0.
    [6502.smutje.se.kicad_sch, steg_2.kicad_sch, steg_3.kicad_sch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]
2026-08-06 Revert "Fetstil på kretsnamn i kopplingstabeller: Arduino D2, +5V, PORTF, LCD 1 osv"
    This reverts commit eae4dcc80c4517bfbff4d0eaabf3f18a76de19a2.
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2026-08-08 Steg 1: rätt ordning högersida W65C02S — pin 40 (/RESET) överst
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2026-08-08 Steg 7: rätt ordning 74HC00 högersida — VCC, U4D in A/B/ut, U4C in A/B/ut
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2026-08-08 Arduino-pinout: tom cell i rad 1 som matchar GND i rad 2
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2026-08-08 Ritat schema och skärdump för steg-9
    [steg_9.kicad_sch]
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2026-08-08 Steg 9: fixa halt-loop JMP-adress — CPU hoppade till fel ställe
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2026-08-08 Steg 9: debug_pulse-flagga — helt tyst under fas 1 och fas 2
2026-08-08 Steg 9: Fibonacci i äkta 6502-kod via ca65 — decimalutskrift på LCD
2026-08-08 Steg 9: fixa Fibonacci-delay — 1s istället för 2 min mellan tal
    [program_fib.asm]
2026-08-08 Steg 9: fixad Fibonacci — korrekt sekvens 0,1,1,2,3..., delay_ms som subrutin, 500 cykler fas 1
    [program_fib.asm]
2026-08-08 Steg 9: fixa vektor-laddning från program_fib.h — separata write_mem för -
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2026-08-08 Flytta program.cfg till asm/
    [program.cfg]
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2026-08-09 Steg 7: anpassa text till 16×2 LCD — 2 rader, inte 4
2026-08-10 Steg 7: ta bort tomma rad 3/4 — endast 2 rader för 16×2 LCD
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2026-08-11 Steg 8–9: pedagogisk intro till assembler-programmen, 2-raders LCD, körning med seriemonitor + LCD
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2026-08-12 Nytt schema för eeprom-1
    [steg_10.kicad_sch, steg_9.kicad_sch]
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2026-08-13 Steg 1-11: lägg till Arduino-pinnar D0-D53, GND, 5V; slå ihop intervall-spans till enheter
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2026-08-13 Steg 5: LiquidCrystal-konstruktorn som svart kodbox, en pin per rad med kommentar
2026-08-13 Formatera alla kretsar med strong (CPU, VIA, SRAM, EEPROM, 74HC00, Arduino, LCD)
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2026-08-13 Steg 1: Arduino-pinout — nedre kontakter dubbelt breda, ta bort 'nedre kant ·'
2026-08-13 Steg 1: Arduino-pinout — flytta D20–D53 + GND in i body ovanför nedre kanten
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2026-08-13 Steg 1: Arduino-pinout — 40px text på två rader, kontakter med rundade yttre hörn
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2026-08-13 Steg 11: registrera custom cfg-språk i highlight.js så program.cfg färgas med Monokai som Arduino-koden
2026-08-18 Kopplingsschema — datorn med EEPROM
    [steg_11.kicad_sch]
2026-08-18 Steg 11: 4 KB VIA-fönster (-) — byggbar NAND-träd-avkodning, uppdaterad sanningstabell, minneskarta, program.cfg (ROM2 → )
2026-08-18 Steg 11: förenklad avkodning — SRAM /CE direkt på A15, NAND-träd med X/Y/X_INV/Y_INV (8 grindar)
2026-08-18 Steg 11: minimalistisk avkodning (Wozniak/Eater-vägen) — 1 NAND-grind, SRAM $0000, VIA $8000, EEPROM $C000
2026-08-19 Steg 11: städa Adressavkodning-sektionen — intro före tabell, ingen upprepning, Wozniak/Eater i introt
2026-08-19 Analys + åtgärder: BE → +5V, fixa byggkedjan, steg 10–11 kod, städa TODO
    - README: rätta BE till +5V via 10kΩ (BOM, pinout, CPU-tabell), uppdatera
    minneskartan för steg 11 (000/), komplettera komponentlistan
    (62256, AT28C256, 2:a Arduino, 2:a 74HC00), klocka 500 Hz, elva steg
    - TODO.md: rensa felaktiga/färdiga poster; BE och VIA CS1 (pin 24) → +5V
    - build_asm.py: bygg alla asm/*.asm (fixade filnamnsbuggen); bin2h.py
    får array-namn; program_fib.h genereras automatiskt
    - steg 2–6: rätta byte-vänt adressläsning till (PINF << 0) | (PINK << 8)
    - steg 7–10: is_via() täcker hela VIA-fönstret 000–FFF (ingen
    latent busskollision); synka kodblocken i step7/8/9/10.html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
    [EEPROM_programmer.ino, bin2h.py, build_asm.py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]
2026-08-19 Pedagogisk analys + stilfixar: enhetligt utseende, röd tråd, snabba fixar
    - Ny PEDAGOGIK.md: kriterier (jämn svårighetskurva, konkret byggbarhet,
    röd tråd och berättarröst, enhetligt utseende), per-sida-bedömning,
    prioriterad åtgärdslista (14+ punkter)
    - Snabba fixar: step8 rätt env-kommando, step11 rätt program.cfg-sökväg,
    step10/11 Om-det-inte-fungerar utan box, step6 Nya komponenter +
    'körs på 6502'-markering, print-CSS i style.css
    - Enhetligt utseende: seriellog-stilen i step2/5/8 till standard,
    signal-spans i step8, callout-konvention definierad
    - K3-komplettering: de visade kodblocken i step2-6.html synkade med den
    rättade adressformeln (PINF << 0) | (PINK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
    [EEPROM_programmer.ino]
2026-08-19 Röstarbete: personlig öppningsrad + framåtblick på alla stegsidor
    - Varje stegsida (1–11) öppnar nu med en personlig, mänsklig introduktion
    efter h1 (kursiv, grå) — samma röst som index: 'jag har drömt om...'
    - Varje sida avslutas med en 'Vad händer härnäst?'-sektion som binder
    ihop stegen och pekar framåt (steg 11 blickar bortom serien)
2026-08-19 Enhetlig färglegend i minneskartorna (steg 6–11)
    Samma legend med färgrutor överallt: blå = Arduino-emulerat minne,
    grön = RAM/SRAM, gul = VIA, lila = EEPROM/ROM, grå = oanvänt — plus
    varje sidas egna insikt som andra raden.
2026-08-19 Steg 7-utjämning: 'Vad är nytt' + 'Så här fungerar en VIA'
    Två nya sektioner mellan Nya komponenter och Kopplingsschema:
    - checklista över de fem nya koncepten i steget
    - konceptsektion: register som brevlådor, DDR, minnesmappad I/O,
    chip-select och LCD:ns fallande flank
    (Maskinkodstabellen var redan chunkad med delrubriker — ingen ändring
    behövdes där.)
2026-08-19 Steg 9-utjämning: instruktionstabell + spårat exempel
    - 'Nya instruktioner i det här programmet': tabell över CLC/SEC, ADC,
    BCC, SBC, CMP, PHA/PLA, TXA, DEX/DEY, BNE, zero page-adressering
    - 'Så här visas 144': show_num följt steg för steg (hundratal, tiotal,
    ental, mellanslagen)
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2026-08-21 Radnummer i de kollapsbara kodblocken
    - Varje rad i details.codeblock får grått radnummer till vänster med
    skiljelinje (flex-rad: .ln + .ln-code)
    - Logik i toc.js som körs efter hljs.highlightAll(): delar innerHTML
    per rad, hanterar sista tomma raden och tomma rader i mitten
    - Gäller bara kodblocken — serielloggarna och tabellerna är orörda
2026-08-21 Ta bort radbrytningarna mellan kodraderna (gav tomma rader med white-space: pre)
    ln-row-spanen är block (flex) och staplar utan mellanrum — radbrytningarna
    som lades som skydd skapade i stället avstånd mellan raderna.
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2026-08-21 Steg 12: fristående klocka — 16 MHz-oscillator + 74HC393, datorn utan Arduino
    - Ny step12.html: klockkedjan (16 MHz → ÷16 = 1 MHz), kopplingar
    (oscillator, 74HC393, reset-RC), program med delay-subrutiner
    (tidshantering vid 1 MHz), bygg- och brännkommandon
    - Nytt program: asm/standalone/program_standalone.asm + .cfg (ROM på
    , vektorer på ) — byggtestat, 16 KB-binär, reset →
    - Nav: Steg 12 på alla sidor; index 'Vad du lär dig' + README (BOM,
    stegtabell) + begrepp (kristalloscillator, ripple-räknare)
    - Steg 11: 'Vad händer härnäst?' pekar mot steg 12; program.cfg-kodblocket
    rättat (#-kommentarer + file/fill så det verkligen bygger med ld65)
    - md/: step12.md gene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
    [program_standalone.cfg]
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2026-08-22 md/index.md: återställ jag-röst-fixarna + markör
    Föregående commit tappade index.md (markören saknades, så html2md
    regenererade filen och suddade omskrivningen). Nu: markör tillagd,
    alla 'vi/du' → 'jag' återställda, 'man' → 'jag' i presens. Dina
    ändringar från GitHub (svårighetsskala Lätt/Hög) är kvar.
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2026-08-22 MkDocs: fixa snippet-sökvägar (Mega_2560_6502/scripts/) + normalisera blankrader kring tabeller
    - Snippets pekade på scripts/ i stället för Mega_2560_6502/scripts/
    (build_asm.py, bin2h.py, upload_eeprom.py) — nu visas koden
    - Python-Markdown kräver blankrad efter tabell, annars slukas nästa
    rubrik som tabellrad (t.ex. '## 62256 SRAM — pinout'). Alla docs/*.md
    normaliserade med blankrader mellan block.
2026-08-22 Fix: normaliseraren bröt tabellerna (blankrad mellan varje rad) — k==prev-kontroll först
    - Återställt från d0444ba och kört om med korrekt normalisering
    - Tabellintegritet verifierad; Minnestarta → Minnestarta (steg 6-11)
2026-08-22 step11: kollapsbara block för Gamla/Nya kartan (fixa ??? → ??? note-syntax)
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2026-08-22 Fix: snippet-sökvägar (Mega_2560_6502/scripts/...) återställda — build_asm.py, bin2h.py, upload_eeprom.py visas igen
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
